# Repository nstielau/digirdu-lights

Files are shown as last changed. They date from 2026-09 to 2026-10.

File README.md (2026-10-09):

# Digirdu Lights

Expressive didgeridoo lighting for an **Unexpected Maker FeatherS2**, an
**ICS43434 I2S microphone**, and **32-pixel NeoPixel FeatherWings**. The local
wing previews a ~100-foot culvert with the player at its midpoint. Additional
ESP32/wing nodes receive musical features wirelessly over **ESP-NOW**.
Brightness is capped at **15%**, including overlapping visual layers. Audio
stays in RAM; only normalized features and animation state are transmitted.

## Hardware designs

The [producer enclosure](hardware/producer/README.md) contains the editable
Fusion model, pink/purple print files, all button variants, and assembly notes
for the **Adafruit ESP32-S3 Reverse TFT Feather** with an ICS43434 microphone
and 350 mAh LiPo. Revision 11 includes removable four-button assembly carriers.
This mechanical design targets a different board from the FeatherS2 software
setup described below; importing the CAD does not change deployed firmware.

## OTA application upgrades

[OTA operations and recovery](docs/ota-operations.md) describe the implemented
GitHub release/Firebase update workflow, device enrollment and validation status.
Devices try open `openwireless.org` at boot and return to ESP-NOW for playing.
App 1.0.7 adds Battery as the sixth effect. USB base 1.0.4 adds voltage to
device reports and supplies the shared sensor reader; install that base on
each board before it can receive app 1.0.7.
App 1.0.6 keeps the wing data line LOW through sleep to prevent stray pixels.
App 1.0.5 added hold-to-sleep with a synchronized red fade. App 1.0.4 added
Chroma, stronger musical effects and the IO43 effect button.
It keeps the app 1.0.3 fix for an intermittent CircuitPython ESP-NOW receive-buffer error that
could stop a consumer or trigger OTA recovery.
Manage enrolled devices at [Digirdu Lights](https://digirdu-lights.firebaseapp.com):
view their reported versions, follow the latest release, pin a version, or pause
updates. Each board needs a one-time USB bootstrap and its own credential.
Your Google profile photo opens the account menu in the top right; sign out
from that menu. Allowlisted administrators can also use the authenticated
[Sound review](https://digirdu-lights.firebaseapp.com/review.html) library. The
public [Effects guide](https://digirdu-lights.firebaseapp.com/effects.html)
describes Spectrum, Ember, Aurora, Ripple, Chroma and Battery for app 1.0.7, including frequency
bands, musical layers, BOOT selection and the mirrored number indicator.
Both web pages use a cyan/hot-pink 1980s laser theme with the supplied horizon
artwork, bundled locally in `web/assets/laser-horizon.png`.
Updates preserve the node's role, wiring and settings. A failing candidate
rolls back to the previous app; CircuitPython and the OTA base remain USB-managed.
The [original proposal](docs/ota-plan.md) records the approved design.

## What the playing controls

Effect 1 is an eight-band spectrum for microphone diagnostics. The other three
effects use the musical layers below simultaneously, with no exclusive
“current instrument” mode. See [spectrum display](#spectrum-display-effect-1).

| Component | Measurement | Visual response |
| --- | --- | --- |
| Drone | 45–180 Hz energy above background, concentrated low peak and pitch stability | Slow, sustained field extending in both directions |
| Harmonics / timbre | Relative 180–1000 Hz energy; 150–1000 Hz centroid and formant balance | Field hue, spacing and motion change at constant loudness |
| Growl | Relative low/mid energy × flatness, spectral change/modulation and spread | Rolling, irregular colored texture within the drone |
| Vocal | 700–3500 Hz share of total energy AND ratio to drone, plus spectral baseline excess | Brighter moving ribbons; strong onset launches a broader pulse |
| Attack | Positive spectral flux plus relative broadband RMS rise | Short pulses traveling outward from the player |
| Silence / decay | Activity hysteresis and separate release envelopes | Lingering light and trails that gradually fade to black |

These are acoustic **heuristics**, not voice identification. Resonance, vocal
formants and noisy articulations overlap. The intensity values express acoustic
character, not guaranteed classifications or source separation. Tune them while
playing the actual instrument in the culvert. A single microphone cannot tell
a fresh articulation from every strong reflected copy of it.

## Signal path and feature interface

`audio_spectrum.py` uses native `ulab` FFT operations, a **1024-sample Hann
window**, DC removal, **16 kHz** signed input and **1024-sample hops** (contiguous, non-overlapping windows).
The nominal update interval and analysis window are **64 ms**, with
15.625 Hz bin spacing. A 512-sample FFT, half-window overlap, or 22.05 kHz is also
configurable; re-run the hardware benchmark before using a shorter hop. Band edges select FFT bins; they are not brick-wall filters.
The low peak estimate is coarse, not a precision pitch tracker.

Initial energy bands: 45–180, 180–450, 450–1000, 1000–3500 and 3500–8000 Hz.
Power is normalized for the Hann window. Broadband RMS is computed from all
FFT power using Parseval's identity, so it is a DC-removed, Hann-weighted RMS.
The separate mic diagnostic reports unwindowed time-domain RMS. Spectral flux uses positive magnitude
changes normalized by frame magnitude; shape flux compares normalized spectral
shapes. By default, noisiness uses the participation ratio in 180–3500 Hz:
`(sum(power)**2 / sum(power**2))` estimates how many bins carry energy, then
removes the Hann footprint of a tone and normalizes to a noise-like spectrum.
This avoids hundreds of logarithms per frame on the ESP32-S2. Set
`roughness_metric="flatness"` for geometric/arithmetic mean power instead, and
check timing again. The diagnostic `flatness` field holds the selected
noisiness measure. Modulation
tracks changes in the *relative* low/mid energy, so scaling volume alone does
not define growl.

`Analyzer.update(raw, dt)` returns a reused `AudioFeatures` object with:

```python
volume, drone, harmonics, timbrePosition, growl, vocal
roughness, centroid, attack, decay                 # all 0..1
attackEvent, yellEvent                            # one-frame booleans
active, calibrating, clipped                      # state/diagnostics
rms, noiseFloor, bandEnergy, bandRatio, flux, flatness, modulation
spectrum  # Eight normalized band amplitudes, low to high frequency
fundamentalHz                                    # coarse low-band peak, or 0
```

Copy values if retaining history: the object is updated in place. Consume event
flags once per analysis frame. `attack` holds the event strength, then releases.
Drone, growl and vocal envelopes have separate attack/release times. Timbre and
centroid retain their last positions through silence while light decays.

### Algorithm, step by step

The implementation is split between [spectral measurements](audio_spectrum.py),
[feature detection](audio_features.py), and [rendering](animation.py). All
numbers below describe the defaults in [config.py](config.py); per-node
`OVERRIDES` can change the named parameters.

```mermaid
flowchart TD
    PCM[I2S signed PCM] --> FFT[Remove DC, Hann window, FFT]
    FFT --> Raw[Power bands, centroid, flux, noisiness, spread]
    Raw --> Adapt[Background subtraction and adaptive level reference]
    Adapt --> Features[Simultaneous drone, harmonics, timbre, growl, vocal]
    Raw --> Events[Attack and yell onset gates]
    Features --> Smooth[Separate attack and release envelopes]
    Events --> Scene[Layered field, textures, ribbons and outward pulses]
    Smooth --> Scene
    Smooth --> Radio[ESP-NOW features and scene state]
    Events --> Radio
    Scene --> LEDs[Trails, brightness cap and GRB pixels]
```

**1. Turn each audio window into comparable spectral measurements.** Subtract
its mean before applying the Hann window. For an FFT result `X[k]`, the
one-sided power is `2 * gain² * |X[k]|² / (N * sum(window²))`; DC and Nyquist
get half that factor because they have no separate negative-frequency partner.
RMS is the square root of the sum of this power over all bins. Band energy is
the sum over bins inside each configured interval (lower edge included, upper
edge excluded). The spectrum's `total` used for spectral ratios covers 45 Hz
up to, but excluding, Nyquist; it is distinct from the all-bin RMS power.

Centroids use **power weighting**: `sum(frequency * power) / sum(power)`.
The broad centroid becomes `centroid = clamp(centroid_hz / 3500)` before
smoothing. A second centroid uses only 150–1000 Hz for mouth/formant movement.
The drone estimate is the strongest FFT bin in 45–180 Hz; its concentration
is the fraction of drone-band power in that bin and its immediate neighbors,
clipped to the band. There is no harmonic pitch reconstruction or interpolation.

Two different flux measures serve different purposes:

- **Onset flux:** sum of positive changes in FFT magnitude, divided by the
  larger of the previous/current magnitude sums over 45 Hz to Nyquist. It
  responds to an amplitude jump as well as newly appearing frequencies.
- **Shape flux:** half the sum of absolute differences between spectra after
  each is normalized to unit magnitude sum. It responds to spectral
  redistribution with much less sensitivity to uniform volume changes.

Noisiness and frequency spread use 180–3500 Hz. The default participation
ratio estimates the effective number of occupied power bins; subtract
`noise_tonal_bins=2`, divide by `bin_count * noise_expected_fill` (default 0.5),
and clamp to 0..1. Optional logarithmic flatness computes the geometric mean
relative to the arithmetic mean, with a small numerical floor. Spread is the
power-weighted standard deviation of frequency, in Hz. These are texture
proxies: dense tonal harmonics can also occupy many bins.

**2. Learn background slowly and normalize playing level separately.**
Calibration lasts two seconds and ignores the first 0.2 seconds of microphone
startup. It takes the lower 20th percentile of RMS and, independently, each
band's power. The RMS noise floor cannot fall below 2 PCM units; each band has
a minimum background power of `2² / 5`.

During operation, the background updates only when `rms < 1.8 * noiseFloor`.
It rises with a 120-second time constant and falls with a four-second time
constant. Each band's learning target is also capped at twice its current
estimate. A strong foreground event therefore cannot immediately become the
new background. Continuous playing during calibration can still produce a bad
starting floor; calibrate quietly.

Let `S(a, b, x) = clamp((x-a)/(b-a), 0, 1)`. The shared activity gate is
`g = S(1.6, 5.0, rms/noiseFloor)`. `active` turns on at a ratio of 2.8 and turns
off after 0.45 seconds continuously below 1.6. This flag describes activity;
the continuous gate and release envelopes control the lights.

A separate playing-level reference starts at the larger of 120 PCM units or
five times the calibrated noise floor. Only frames above the active-on ratio
update it. Clamp each observation to between half and twice the reference,
then follow it with a 12-second rise or 45-second fall. Volume is:

```text
volume_target = g * clamp(
    log(1 + max(0, rms-noiseFloor)/noiseFloor)
    / log(1 + 2*level_reference/noiseFloor), 0, 1)
```

This logarithmic response makes quiet detail visible while limiting one loud
burst's influence. It is a rolling exponential reference, not a sliding-window
maximum. Other features mostly use spectral ratios rather than this volume.

**3. Calculate the continuous musical layers together.** Subtract the learned
background from each of the five band powers and clamp at zero. Divide by the
larger of their sum and the squared noise floor to obtain `bandRatio`.
Consequently the ratios can sum to less than one near silence. Below, `m` is
the combined 180–1000 Hz ratio, and all `S` outputs are bounded to 0..1.

| Feature | Calculation before its final smoothing |
| --- | --- |
| Drone | `g * S(2,6,drone_snr) * S(0.4,0.85,concentration) * (0.6 + 0.4*pitch_stability)`. `drone_snr` is the square root of raw drone power divided by its learned background. Stability follows frame-to-frame fractional changes of the strongest low bin; a 30% change maps to zero instantaneous stability. |
| Harmonics | `g * S(0.03,0.65,m)`: relative harmonic presence rather than loudness. |
| Timbre position | `0.65*S(150,1000,timbre_centroid_hz) + 0.35*(450–1000 Hz ratio)/m`, with a protected denominator. This blends formant position and upper-mid balance. |
| Roughness | `g * (0.55*noisiness + 0.25*modulation + 0.20*shape_flux)`, after mapping these inputs through their configured ranges. |
| Growl | `roughness * S(0.08,0.55,m) * (0.6 + 0.4*S(200,1200,spread_hz))`. Mid energy must coexist with texture; level alone is insufficient. |
| Vocal | Compute the ratio-based vocal base below, then multiply by `0.75 + 0.25*excess` relative to a slowly learned vocal share. |

Modulation here is **variation of relative mid-band energy**, not a detected
vibrato frequency: compare `m` with its 0.6-second reference, take the absolute
difference, and smooth it over 0.16 seconds. Default scaling ranges are
0.015–0.18 for modulation, 0.03–0.4 for noisiness, and 0.02–0.25 for shape flux.

Vocal detection uses the overlapping **700–3500 Hz** range, including part of
the mid/formant band; it does not use only the named 1000–3500 Hz band.
Unlike `bandRatio`, these vocal ratios use raw spectral powers with noise-floor
protection in the denominators:

```text
share = vocal_energy / max(total_energy, noiseFloor²)
relative_to_drone = vocal_energy / max(drone_energy, noiseFloor²)
vocal_base = g * sqrt(S(0.10,0.55,share) * S(0.12,1.50,relative_to_drone))
excess = S(0.04,0.25,share-vocal_reference)
vocal_target = vocal_base * (0.75 + 0.25*excess)
```

The vocal reference follows the share over 15 seconds only while the gate is
open and `vocal_base < 0.25`. Strong vocals cannot train themselves away.
Uniformly amplifying a clean drone preserves its spectral ratios, so it does
not create the missing high-frequency share required for a yell.

**4. Detect events without repeatedly firing on a sustained sound.**

- ATTACK score is `g * (0.65*S(0.06,0.4,flux) + 0.35*S(0.08,0.6,rms_rise))`,
  where `rms_rise = max(0, rms-previous_rms) / max(rms,noiseFloor)`. Fire at
  score 0.5 or above; rearm only below 0.18, with a 0.18-second cooldown.
- YELL fires when `vocal_base >= 0.58` **and** its rise from the previous frame
  is at least 0.10. Rearm below 0.25, with a 0.6-second cooldown. These checks
  use the unsmoothed base so a sustained vocal produces an envelope without
  repeatedly creating events. A gradual vocal can have intensity without YELL.
- Both events require the active-on RMS ratio and compare current RMS with
  60% of their own previous-event RMS memory, which decays over 0.8 seconds.
  This suppresses some weaker echoes; it cannot identify all reflected sounds
  and may also reject intentionally softer articulations.
- Calibration completion and detected capture gaps suppress events for 0.15
  seconds. Partial capture, a reported overflow, or a gap over three hop periods
  resets spectrum history. The first fresh spectrum has zero flux.

`attackEvent` and `yellEvent` last one analysis frame. `attack` preserves the
triggering score and decays with a 0.22-second time constant. ESP-NOW repeats
recent event counters and ages so a missed packet need not lose the pulse.

**5. Smooth features and let the scene ring out.** Every exponential smoother
uses `target + (previous-target)*exp(-dt/tau)`, choosing the attack constant
when rising and the release constant when falling. Times below are time
constants: after one constant, about 37% of the old difference remains.

| Envelope | Attack | Release |
| --- | --- | --- |
| Volume and harmonics | 0.09 s | 0.60 s |
| Drone | 0.30 s | 1.80 s |
| Growl and roughness | 0.16 s | 0.85 s |
| Vocal | 0.08 s | 0.50 s |
| Timbre and centroid | 0.22 s | 0.22 s; retain last position when the gate closes |

The scene also retains `decay = max(volume_target, previous_decay*exp(-dt/3.5))`.
The renderer builds a continuous field from drone, volume and this decay;
harmonics change wave spacing and speed, timbre changes hue, growl adds moving
texture, and vocal adds ribbons. Events enter a fixed eight-pulse pool and
travel outward from the player's coordinate at 1.15 half-culvert lengths/s,
with a 1.35-second intensity decay. These are artistic speeds, not sound speed.
App 1.0.4 mixes the larger of `0.85*drone`, `0.30*volume`, and
`0.42*decay`, with 0.28-second pixel trails. The 3.5-second audio decay remains
separate, so shortening trails does not abruptly end the atmosphere.
Contributions are capped before
conversion to GRB bytes at brightness 0.15 (maximum channel value 38).
The musical effects change palette and layer parameters while preserving the
shared detector and scene state. Spectrum uses its own band-level envelopes.

### Expressive musical effects (1.0.4)

App 1.0.4 includes the September 16 preview that strengthens effects 2–4
using a labelled didgeridoo feature capture, plus the IO43 button and Chroma. Spectrum's eight bar envelopes and the detector thresholds
are unchanged. Consumers need the updated renderer to match this release;
the ESP-NOW packet format remains v3.

| Feature (median) | Drone section | Rhythms | Growls |
| --- | --- | --- | --- |
| Drone | 1.00 | 0.98 | 0.99 |
| Harmonics | 0.45 | 0.635 | 0.66 |
| Growl | 0.05 | 0.18 | 0.21 |
| Roughness | 0.16 | 0.44 | 0.47 |

There were 4 attack events in the drone label, 42 during rhythms and 16 during
growls. Growls and rhythms overlap; these results do not establish reliable
technique classification. One yell event occurred under the growl label and
two under the yell label. The 80-second logger ended before the final decay
section, so the full three-yell exercise and acoustic decay were not verified.
Only timestamped feature/event logs were saved locally, not raw audio.
Labels follow host cues; tool/message delays made the windows longer than the
requested ten seconds. The median table includes transition samples and uses
the normal once-per-second feature log, not every FFT frame.

The renderer now expands measured timbre positions 0.12–0.45, growl 0.04–0.30,
and vocal 0.03–0.40 to their full visual ranges. These are visual transfer
functions (`visual_*_range`), not changes to classification. Faster waves and
a lower wave trough increase motion contrast. Short pixel trails keep attacks
distinct; immediate whole-wing accents accompany the outward pulse on attacks
and yells. These accents decay over 0.13/0.32 seconds and account for event age
on wireless receivers. Ripple has a stronger underlying field, while remaining
the most pulse-focused effect. All overlapping layers still obey brightness 0.15.

New visual controls in `config.py`: `visual_timbre_range`, `visual_growl_range`,
`visual_vocal_range`, the three `*_field_gain` values, `wave_floor`,
`vocal_ribbon_gain`, `attack_bloom_gain/s`, `yell_bloom_gain/s`, and `pulse_gain`.
The existing wave speeds, pulse width/speed/decay and `trail_s` remain tunable.

A host comparison used 32 frames at 64 ms with the observed drone feature
values, then changed only growl from 0.05 to 0.21 or timbre from 0.20 to 0.30.
Mean absolute GRB-byte differences (old → preview) were:

| Effect | Growl response | Timbre response | Frame-to-frame motion |
| --- | --- | --- | --- |
| Ember | 2.04 → 9.39 | 0.30 → 1.10 | 0.18 → 0.72 |
| Aurora | 0.80 → 5.78 | 0.59 → 2.43 | 0.09 → 0.55 |
| Ripple | 0.70 → 4.63 | 0.12 → 0.96 | 0.05 → 0.37 |

These compare output buffers, not perceived brightness or measured light.
The baseline is the renderer/configuration at commit `17d17ed`. Brightest
channel values remain at most 38; regression checks cover observed-range
response, late event accents, fade to black, and the cap.

The producer USB upload verified all 18 base/recovery files. Eight-second
native runs per musical effect included I2S, FFT, actual NeoPixel writes,
ESP-NOW, watchdog and health checks (including each run's calibration):

| Effect | Frames / fps | Mean / maximum work | Frames over 64 ms | Radio sends / errors |
| --- | --- | --- | --- | --- |
| Ember | 111 / 13.8 | 63.4 / 84.0 ms | 47 | 93 / 0 |
| Aurora | 107 / 13.4 | 65.5 / 86.1 ms | 63 | 92 / 0 |
| Ripple | 115 / 14.3 | 62.3 / 82.0 ms | 43 | 81 / 0 |

All three runs reported zero send skips and zero detected discontinuities.
Timing still exceeds the hop budget on many frames; no-discontinuity output
does not prove lossless capture. These runs used ambient sound, not a repeat
of the labelled didgeridoo performance. CircuitPython subsequently hard-faulted
during the post-benchmark soft restart. All installed files still matched;
a full reset was used to leave safe mode. The fault's native cause has not
been established, and a short running-app check cannot establish long-term
stability.

## Spectrum display (effect 1)

The initial effect is **Spectrum**, display number 1 / protocol ID 0. Hold the
wing in landscape: **eight columns across, four rows high**. Low frequencies
are left, high frequencies right; bar height is the level in that frequency
bucket. A red-to-violet rainbow runs across the columns. The top pixel of each
bar dims continuously between row steps. Brightness remains capped at 0.15.

| Column, left to right | Frequency range (Hz) |
| --- | --- |
| 1 | 45–90 |
| 2 | 90–180 |
| 3 | 180–350 |
| 4 | 350–700 |
| 5 | 700–1400 |
| 6 | 1400–2800 |
| 7 | 2800–5000 |
| 8 | 5000–8000 |

These are eight independent sums of the existing Hann FFT's power, not a
redistribution of the five musical detector bands. Upper edges are exclusive.
At 16 kHz / 1024 samples, FFT bins are 15.625 Hz apart; this is a coarse
level display, not precision pitch measurement. Raising the sample rate leaves
the default top edge at 8 kHz; tune `spectrum_edges` to include higher frequencies.
Wider buckets collect more broadband-noise power; heights show integrated band
amplitude, not power per Hz or calibrated sound pressure.

Each bucket gets a quiet-start background estimate and the same gated, slow
background learning as the musical detectors. The display computes:

```text
amplitude[i] = sqrt(max(0, power[i] - background[i]))
target[i] = activity_gate * clamp(spectrum_gain * amplitude[i]
                                / (level_reference * spectrum_full_scale)) ** spectrum_curve
height[i] = 4 * attack_release_smooth(target[i])
```

The shared level reference adapts slowly (12 s up / 45 s down, bounded input).
It does not stretch every frame's tallest bar to full height: a louder version
of the same sound raises the bars. Defaults are gain 1, full-scale reference
multiplier 2, amplitude curve 0.6, attack 0.05 s and release 0.30 s. Adjust
`spectrum_gain`, `spectrum_full_scale`, `spectrum_curve`, `spectrum_attack_s`,
`spectrum_release_s`, and the nine `spectrum_edges` in your node profile.
Calibration still needs two quiet seconds. On silence the bars fall smoothly;
there are no added musical pulses or background glow in this diagnostic effect.

Factory wiring has four progressive rows: top row indices 0–7, bottom 24–31.
The bottom-up bar coordinate `(x, y)` maps to `(3-y)*8+x`. Set
`spectrum_rotation=180` on a flipped wing. This mapping ignores culvert
`pixel_positions`; complete 32-pixel tiles repeat the display, and leftover
pixels stay dark. The confirmed portrait number indicator keeps its independent
orientation and still appears for 1.5 s when BOOT changes the effect.

ESP-NOW **protocol v3 / 51 bytes** carries all eight normalized levels at
8-bit precision, as well as the existing features, events and effect ID.
Update producer and consumers together: v2 and v3 reject each other's packets.
Consumers do not need a microphone or FFT. They use the producer's level
smoothing; loss of the radio link fades the last levels over `decay_s`.
`SPECTRUM levels=(...)` in both serial logs exposes the eight values, low to high.

## FeatherS2 wiring

Disconnect power before changing wiring. These are **GPIO numbers**: Feather
D-number aliases do not necessarily match them.

| Connection | FeatherS2 pin | CircuitPython name |
| --- | --- | --- |
| Mic BCLK / SCK | GPIO 5 | `board.IO5` |
| Mic LRCLK / WS | GPIO 6 | `board.IO6` |
| Mic DOUT / SD | GPIO 9 | `board.IO9` |
| Mic SEL / LR | GND | Left channel selected |
| Mic 3V / VDD | 3.3V | Use the main 3V3 supply |
| Mic GND | GND | Shared ground |
| Wing data, factory jumper | GPIO 38 | `board.IO38` |
| Wing power | Feather USB/BAT and GND headers | Aligned, soldered headers |

The mic uses standard I2S, 32-bit slots carrying 24-bit signed samples,
16 kHz sampling, and the left channel. CircuitPython converts capture to
signed 16-bit samples for level measurements. GPIO 9 is also the SCL pin:
do not use I2C/STEMMA devices on that pin while this mic is connected.
The FeatherS2 onboard APA102 status LED is separate from the FeatherWing.
The wing's default jumper occupies the standard Feather M0 D6 header position,
which maps to **GPIO 38** on FeatherS2. Do not use FeatherS2's `board.D6` alias:
it maps to GPIO 3 at a different physical position and leaves this wing dark.

## Setup and firmware

Host requirements: Python 3.10+, `make`, `curl`, USB data cable. Tools install
into `.venv`; no extra CircuitPython library bundle is needed by this app.
`make check` additionally needs Python 3.10–3.13 for the pinned NumPy version.
The pinned firmware is **CircuitPython 10.3.1 for `unexpectedmaker_feathers2`**.
The Adafruit ESP32-S2 Feather and FeatherS2 Neo use different firmware.

```sh
make setup
make ports
make firmware       # Download the correct .uf2
```

The connected FeatherS2 initially had CircuitPython **6.2.0-beta.1** from 2021.
That version needs upgrading for the `audioi2sin.I2SIn` API used here. Its
existing app and libraries were backed up to
`.artifacts/feathers2-files-1789493704704278000/` before the upgrade.

For future firmware upgrades, first back up the files on `CIRCUITPY`. Enter
the UF2 loader: press Reset, then press Boot when the onboard RGB LED turns
purple. The drive is normally called **FTHRS2BOOT**.
Older loaders may show no purple: press Reset, wait about one second, then
press Boot. Their drive may be called **UFTHRS2BOOT**; both names are supported.
Once that drive appears, run:

```sh
make flash
```

The FeatherS2 target copies the official UF2 to the identified bootloader drive.
It does not erase the entire flash. Wait for **CIRCUITPY** to reappear. If no
bootloader drive appears, consult the manufacturer's recovery instructions
linked below; do not use the old ESP32 board's flash command on this board.

### Older boards without a working UF2 loader

Hold **BOOT**, tap **RESET**, then release BOOT. If the recovery USB port does
not appear, unplug USB and reconnect it while holding BOOT, then release BOOT.
This uses the chip's built-in ROM loader and does not require a purple LED.

```sh
make ports
make flash-rom      # Checks ESP32-S2/16 MB, backs up flash, ERASES, writes .bin
```

Tap Reset after flashing if instructed. This installs CircuitPython directly;
it does not install the optional TinyUF2 loader. Use `make flash-rom` for later
firmware reinstalls if no FTHRS2BOOT drive is available. Routine app changes
still use only `make deploy`. Firmware and full flash backups stay in
`.artifacts/` and are ignored by Git.

## Deploy and test

```sh
make check
make deploy
make test-mic
make benchmark
make console
```

`make deploy` automatically identifies supported boards from CircuitPython's
board ID: FeatherS2 uses GPIO 38 and its matched CIRCUITPY drive; Adafruit
Feather ESP32 V2 (HUZZAH32 V2) uses GPIO 32 and serial file transfer. Both get
the same OTA base and complete recovery application, preserving device settings. An unknown model stops before
writing; add and verify its hardware profile before deploying to it. Use
`BOARD=...` to require a specific model. Firmware installation still requires
an explicit board choice for anything other than the default FeatherS2.

Deployment stops the app, backs up existing application files under
`.artifacts/`, stages uploads, verifies readback, and restarts. Startup checks require audio-level output (leader)
or a running render loop (follower), with no traceback. Existing `node_config.py` is preserved unless `NODE_CONFIG=...`
is supplied explicitly. A level log alone cannot establish that the microphone responds
to sound; compare quiet and clap levels and watch the LEDs.

Keep the room quiet for the **first two seconds** after startup to calibrate
the noise floor. Then play a steady drone, change mouth/tongue position, add a
growl, vocalize, and try hard DOOTs. Watch both the feature logs and the lights.

`make test-mic` captures ten seconds with the LEDs off, prints RMS (average
signal strength), peak, and sample span, then resumes the app. Stay quiet at
first and clap during the test. The maximum RMS should exceed the quiet level;
constant zero/span-zero data indicates a wiring or power problem. These are
relative digital levels, not calibrated sound-pressure decibels.

`make benchmark` measures the producer's live audio/animation loop and then
resumes the app. See [Benchmarking](#benchmarking) for its scope, interpretation,
and recorded hardware results.

`make console` shows `AUDIO rms=... drone=... growl=... vocal=...` plus
`ATTACK strength=...` and `YELL vocal=...` lines. `clip=True` means the microphone
PCM is saturating; software gain cannot recover the lost waveform.
Ctrl-C stops the app and turns off the wing, Ctrl-D restarts/calibrates it,
and Ctrl-] closes the console. Close other serial terminals before deployment.

For multiple boards or a differently named mount:

```sh
make deploy PORT=/dev/cu.usbmodem... MOUNT=/Volumes/CIRCUITPY
# Linux example: PORT=/dev/ttyACM0 MOUNT=/media/yourname/CIRCUITPY
```

## Benchmarking

### Repeat the hardware measurement

Connect the **microphone FeatherS2**, close other serial terminals, and run:

```sh
make ports
make benchmark PORT=/dev/cu.usbmodem...
```

With OTA enabled, first enter [USB maintenance](docs/ota-operations.md#maintenance-and-usb-repair).
This loads the recovery app and invokes `lights_app.benchmark(5)` through the REPL. It stops the
running app, creates fresh analysis/render/radio state, and runs for about five
seconds including the initial two-second calibration. Stay quiet during
calibration, then play or clap to exercise the feature and pulse layers. The
benchmark calculates all pixel bytes but **does not write them to the wing**.
It then restarts the normal app, which calibrates again. A standalone producer
profile with `radio_role="off"` omits radio work; record the role with results.

For comparisons, record board/firmware, deployed revision, node overrides,
FFT/hop/rate, pixel count, radio role, effect, and the sound used. Compare quiet,
steady-drone and attack/vocal-heavy runs separately: active pulses increase
rendering work. Five seconds is a quick diagnostic with only about three
seconds after calibration, not a sustained-load test. Re-run after changes to
FFT overlap, pixel count, noisiness metric or effects; also inspect normal
LED-enabled operation for timing warnings.

### What the output measures

| Field | Meaning |
| --- | --- |
| `frames` | Complete analyzed and rendered frames, including calibration frames |
| `fps` | Frames divided by total loop wall time, including blocking microphone capture |
| `work_mean_ms`, `work_max_ms` | Processing time **after** each `mic.record()` returns: FFT, feature updates, button polling, rendering, radio work, event/periodic logging and explicit garbage collection |
| `budget_ms` | `1000 * hop_size / sample_rate`; 64 ms with the defaults |
| `overruns` | Frames whose measured post-capture work exceeds that budget |
| `discontinuities` | Detected incomplete captures, reported overflows, or capture-to-capture gaps longer than three hop periods |
| `sent` | Broadcasts submitted without a synchronous send error; not consumer acknowledgements |
| `errors` | Exceptions from send attempts |
| `skipped` | Send opportunities skipped while the previous send is still pending |

The work timer excludes the blocking capture call and its internal copying;
it also excludes printing the over-budget warning itself. LED serialization
is excluded in benchmark mode. Consequently a mean below 64 ms does **not**
prove that the complete producer keeps up continuously. Normal operation uses
the same timing loop with LED writes enabled. The ESP32-S2 driver does not
report every DMA overflow: `discontinuities=0` is not proof of lossless capture.
The nominal maximum is 15.625 windows/s; this is not a measured end-to-end
sound-to-light latency. Capture, envelopes, radio scheduling and consumer
rendering all contribute to perceived response.

### Recorded results — September 15, 2026

FeatherS2, ESP32-S2 at 240 MHz, CircuitPython 10.3.1, 16 kHz capture, 1024 FFT /
1024 hop, 32-pixel renderer, participation noisiness, ESP-NOW producer enabled.
The live sound varied and triggered ATTACK/YELL features; it was not a recorded,
repeatable didgeridoo dataset. These measurements were taken during development
of the implementation committed in `4ceb381`; no new hardware timing run is
implied by this documentation update.

```text
AUDIO BENCH frames=72 fps=14.3 work_mean_ms=59.1 work_max_ms=97.7 budget_ms=64.0 overruns=20 discontinuities=0
RADIO BENCH sent=48 errors=0 skipped=0
```

| Check | Measured result | Interpretation |
| --- | --- | --- |
| Live producer throughput | 14.3 frames/s versus nominal 15.625 | Below the intended capture-window cadence |
| Post-capture work | 59.1 ms mean; 97.7 ms maximum | Average fits narrowly; peak exceeds the 64 ms budget |
| Over-budget frames | 20 of 72 (about 28%) | Current configuration has intermittent processing overruns |
| Radio submissions | 48; zero reported errors or pending-send skips | Sender path ran; submission success alone says nothing about reception |
| Separate renderer stress check | Maximum 20.2 ms with all features/events and a full pulse pool | Renderer-only diagnostic, not total frame time; do not add it to the live measurement, which already includes rendering |
| Native FFT sanity check | 93.75 Hz sine, amplitude 1000: RMS 706.65, drone-power share about 0.99998 | Agrees with the expected sine RMS near 707 and correct low-band placement |
| Two-device radio check | ESP32 V2 accepted 94 packets in its first eight seconds, zero rejected; later restart/rejoin reached 256 accepted, zero rejected | Confirms actual reception and automatic rejoining at the tested location; not culvert-wide RF coverage |

The implementation uses native `ulab` arrays for FFT, dot products and
per-pixel math. Full-window hops reduce the number of FFTs per second;
participation noisiness avoids per-bin logarithms; RMS reuses FFT power;
frequency arrays are cached and the event pulse pool is bounded. These choices
reduce work, but the measured overruns remain. Validate processing headroom on
the actual sound/effect load before adding pixels or shortening the hop.

### Previous Culvert preview: historical measurement

Before Spectrum replaced effect 1, after adding the stronger volume response and attack bloom, a mostly quiet
five-second producer run measured **77 frames, 15.3 frames/s, 55.4 ms mean work,
66.1 ms maximum, two overruns, zero detected discontinuities**, and 44 radio
submissions with no errors/skips. The sound load differs from the earlier
attack-heavy run, so this is a functional timing check, not evidence of a
performance improvement. LED writes are still excluded in benchmark mode.

On the board's native renderer, fixed test features at volume 0.05 versus 0.8
produced sums of all pixel channel bytes of **298 versus 1540** (about 5.2×),
with the same drone and residual decay levels. An attack-strength-0.8 test
produced a peak of **38**, with every pixel reaching at least 20 in one channel.
These are output-byte checks, not measured light intensity or an acoustic test.
The producer's full file readback and startup passed with effect 0 selected.

### Producer with OTA health monitoring (September 16, 2026)

After installing app **1.0.3** and base **1.0.1** on FeatherS2, a 12-second
mostly quiet run used `lights_app.run(seconds=12, health=Health(watchdog, False))`.
It included actual NeoPixel writes, the 20-second watchdog and OTA feature-health
checks, as well as microphone capture, FFT, Spectrum rendering and ESP-NOW.

| Measurement | Result |
| --- | --- |
| Frames / update rate | 146 / 12.1 fps |
| Post-capture work | 74.6 ms mean / 93.0 ms maximum |
| Work over the 64 ms budget | 136 of 146 frames |
| Detected discontinuities | 0 |
| ESP-NOW sends / errors / skips | 146 / 0 / 0 |
| Free Python heap before the run | 7,678,640 bytes |

Most frames exceeded the processing budget. Zero detected discontinuities does
not prove lossless capture; the driver cannot report every DMA overflow. These
numbers include LED writes and the health monitor, so they are not directly
comparable to the LED-disabled measurements below. After enabling OTA, the board
checked in to Firebase over HTTPS, returned to ESP-NOW channel 1 and continued
processing changing microphone levels for the 65-second observation window.

### Spectrum preview: measurement before OTA

After replacing effect 1 with the eight-band display, `make deploy` verified all
ten application files on the FeatherS2 and retained its producer profile.
A mostly quiet five-second `make benchmark` run measured **74 frames, 14.7 fps,
55.9 ms mean work, 69.1 ms maximum, three overruns of the 64 ms budget, and zero
detected discontinuities**. ESP-NOW submitted **51 packets with zero errors or
skips**. Benchmark mode excludes LED writes and capture blocking from work time;
these numbers do not establish worst-case performance or consumer reception.
The initial serial logs showed changing low-band levels near the noise floor.
The ESP32 V2 consumer subsequently received the same update: all ten application
files passed final readback, with its saved consumer profile preserved. Its
eight-second startup check accepted **96 protocol-v3 packets, zero rejected**,
with a live link to the producer and Spectrum selected. Reported band levels
were near zero (mostly dark; one bottom pixel briefly at channel value 1).
A subsequent 30-second serial observation included a consumer reboot/rejoin
and reached **308 accepted packets, zero rejected**. During active sound, sampled
volume varied from **0.34 to 0.91**, the second frequency bucket reached **0.87**,
and rendered output varied from **5 to 17 lit pixels**, with peak channel values
**13–38**. This verifies changing producer features, consumer reception and bar
output. The source sound during that log capture was not identified.

The user subsequently **visually confirmed rainbow bars rising and falling in
response to sound on both the producer and consumer wings**. This completes
the two-board Spectrum response check; it does not establish didgeridoo
classification accuracy or RF coverage inside the culvert.

### Algorithm checks versus musical accuracy

`make check` runs 72 host tests using pinned NumPy and generated PCM, plus
packet-state, renderer, button and deployment checks. Signal cases include
50/93.75/140/175 Hz drones at different levels, equal-RMS timbre changes,
modulated mid-band noise, vocals layered over drone, attacks and decaying tails,
loud outliers, and a 60-second sustained drone that must not become background.
They verify calculations and expected behavior under controlled inputs. Host
execution time is not an ESP32 performance benchmark, and these tests do not
provide precision/recall or classification accuracy on real didgeridoo playing.
The earlier clap-reactive rainbow and the two-board Spectrum response have
visual confirmation; the musical layers still need an instrument trial in the culvert.

## Tune the installation

Defaults live in `config.py`; put per-node changes in an `OVERRIDES` dictionary
in a node profile, then run `make deploy NODE_CONFIG=path/to/profile.py`. Routine
`make deploy` preserves the configuration already saved on that board. Important groups:

- **Capture:** `sample_rate`, `fft_size`, `hop_size`, `bands`, `timbre_band`,
  `vocal_band`, `roughness_band`, `gain`. Use full-window hops on this FeatherS2 for processing headroom; half-window
  hops are available for faster boards. At 22.05 kHz,
  extend the high band's upper edge to 11025 Hz.
- **Background:** `calibration_s`, `min_noise_rms`, `noise_rise_s`,
  `noise_fall_s`, `noise_learn_ratio`, activity ratios and `silence_hold_s`.
- **Dynamics:** `level_initial`, `level_rise_s`, `level_fall_s`,
  `adaptation_limit`, and each feature's attack/release times.
- **Growl:** `mid_ratio`, `flatness_range`, `modulation_range`,
  `shape_flux_range`, `roughness_weights`, `spread_hz`, `roughness_metric`,
  `noise_tonal_bins`, `noise_expected_fill`.
- **Vocal:** `vocal_total_ratio`, `vocal_drone_ratio`, `vocal_excess_range`,
  `yell_on/off`, `yell_rise`, `yell_cooldown_s`.
- **Attacks/echoes:** flux/rise ranges, `attack_on/off`, cooldown,
  `echo_memory_s` and `echo_event_ratio`. Higher echo rejection can also miss
  intentionally softer repeated articulations.
- **Visuals:** hue/timbre span, wave speed/spacing, pulse speed/width,
  `decay_s`, `trail_s`, and per-pixel coordinates. Spectrum has separate
  band/amplitude/smoothing controls described above. Keep `brightness=0.15`.

Start with a quiet reset. Play the same drone softly and loudly: `drone` should
persist and `vocal` should stay low. Move mouth/tongue position at similar level:
`timbrePosition` should move. Add a growl: adjust texture thresholds before gain.
Add vocals: tune the two energy-ratio ranges before `yell_on`. Finally stop and
listen to the culvert tail while adjusting `decay_s` and echo rejection. Do not
calibrate during continuous playing. Flat data for two seconds stops the app
with an explicit wiring error and clears the wing.

## Multiple wireless FeatherWings

Each wireless node needs an ESP32 and local power for its FeatherWing. Wings
alone do not contain a radio. The current mic board is the **producer** (internally `leader`); consumers
(internally `follower`)
render the transmitted features without initializing a microphone. Consumers support **FeatherS2 GPIO 38** and **Adafruit Feather ESP32 V2 GPIO 32**.
The board ID selects the verified pin automatically. The ESP32 V2 profile is
consumer-only; microphone wiring is configured on FeatherS2.

ESP-NOW uses a common 2.4 GHz channel (default 1), without a router, Wi-Fi login,
or internet connection during playback. The OTA startup phase may connect to
Wi-Fi, then disconnects before restoring the lighting channel. The sender broadcasts version-3, 51-byte packets at up to ~16 updates/second. Packets contain eight spectrum levels, feature envelopes, scene
time/phase, the selected effect ID, a boot/session ID, sequence number, and recent event counters,
strengths and ages. Receivers filter the configured leader MAC and group, reject
duplicate/out-of-order packets, and recover a recent event if one packet is
lost. Broadcasts are unencrypted; MAC/group filtering avoids mixing installations
but is not authentication. Only lighting state is sent, never audio.

A follower starts dark until it receives valid state. After 0.5 seconds without
valid packets it releases the last state over `decay_s`; it does not freeze
bright or abruptly switch off. Scene phase is refreshed on receipt, providing
approximate visual synchronization, not sample-accurate clock synchronization.
Radio range and reception inside the culvert require a real multi-node test.

### How connections work

```mermaid
flowchart LR
    Mic[ICS43434 microphone] --> Producer[FeatherS2 producer + wing]
    Button[BOOT button: next effect] --> Producer
    Producer -->|ESP-NOW broadcast, channel 1| A[Consumer A + wing]
    Producer -->|Same lighting state| B[Consumer B + wing]
    Producer -->|Same lighting state| C[Additional consumers + wings]
```

There is no pairing button, network password, connection handshake, or consumer
registration. Power the producer and any configured consumers; each consumer
listens independently for the producer's broadcasts. Adding another consumer
does not add another transmit stream. Consumers do not relay packets, so each
must be within radio reach of the producer. This is one producer broadcasting
to many consumers, not a mesh. Every node needs local power.

| Setting | What must match |
| --- | --- |
| `radio_channel` | Same 2.4 GHz channel on all nodes; default 1 |
| `radio_group` | Same installation number on all nodes; default 1 |
| `leader_mac` | Consumers accept the microphone board's MAC, currently `7c:df:a1:03:4c:2c` |
| `radio_role` | One `producer`; all other nodes `consumer` |
| Firmware/protocol | Deploy this application version to all nodes |
| `pixel_positions` | May differ per wing to locate it in the shared scene |

To test: power both boards, keep quiet through producer calibration, then clap
or play. On the consumer, `LIGHTS ... received=... link=live` should show an
increasing receive count. Press the producer's BOOT button for about 0.2 seconds;
the consumer's `effect=` should change too. If reception stays at zero, check
producer power, matching MAC/channel/group, and distance. If packets arrive but
the wing stays dark while playing, check the wing data jumper and local power.
Silence normally fades the lighting to black.

The consumer status line also reports `age_ms` since the latest accepted packet
(`-1` before the first), `active`, received `vol/drone/growl/vocal` envelopes,
and the number of pixels with nonzero output (`lit`) plus the largest output
channel byte (`peak`). Changing envelopes and pixel bytes demonstrate received
state reaching the renderer and LED write call; physical illumination still
needs a visual check. The producer broadcasts even during silence, so an
increasing receive count serves as a basic heartbeat while its audio loop runs.
It is not an independent watchdog for a stalled microphone or producer loop.

### Saved roles and joining

The same application runs on all nodes. A new node defaults to **consumer**;
its saved `node_config.py` selects the role. We deliberately do not auto-detect
producer status from microphone noise: an unconnected data pin can produce
nonzero samples. An explicit producer profile avoids multiple accidental
producers. Role and coordinates survive reset and routine app updates.

For the known microphone board:

```sh
make deploy NODE_CONFIG=examples/node_producer.py
make test-mic
```

For each new **FeatherS2 or Feather ESP32 V2 consumer**, connect it over USB,
edit a copy of the consumer example with that wing's coordinates, and deploy:

```sh
make deploy NODE_CONFIG=examples/node_follower.py
# Optional model enforcement for the HUZZAH/Feather ESP32 V2:
make deploy BOARD=adafruit_feather_esp32_v2 NODE_CONFIG=examples/node_follower.py
```

With multiple USB boards, select the consumer's port. For FeatherS2, also
select its matching CIRCUITPY mount if needed:

```sh
make deploy NODE_CONFIG=examples/node_follower.py PORT=/dev/cu.usbmodem... MOUNT=/Volumes/CIRCUITPY
```

Then use `make deploy` without `NODE_CONFIG` for ordinary software updates.
The producer's state is broadcast, so multiple powered consumers can join at
once without being added to a peer list. A newly joining consumer picks up the
current effect from the next accepted packet. Broadcast has no per-consumer
acknowledgement; a successful send does not prove that every wing received it.

The known producer MAC is `7c:df:a1:03:4c:2c`. Match `leader_mac`, `radio_group`
and `radio_channel` on consumers. `make console` reports MAC, role and link state.
Use `radio_role="off"` for a local audio preview without transmitting. Profiles
accept `producer`/`consumer` as well as the internal `leader`/`follower` names.

### Effect library and BOOT button

App 1.0.4 also accepts a normally-open button between **FeatherS2
IO43 (TX) and GND**, alongside BOOT/IO0. Both inputs have internal pull-ups, independent
40 ms debouncing, and advance one effect on a short release. In 1.0.5, holding either for three
seconds starts sleep instead of changing effects. Both trigger the same number indicator and ESP-NOW effect update.
No external pull-up is required. Set `button_extra_next_gpio=None` to disable
the added input or change it to another unused GPIO. This additional input is
included in OTA release 1.0.4.
IO43 is for normal effect selection; USB maintenance still uses BOOT after RESET.
Do not initialize UART TX on IO43 while using this button. USB serial is separate.
Run `make test-buttons` in USB maintenance to inspect both inputs.

The initial IO18 USB deployment on September 16 verified all 18 base/recovery files on the
FeatherS2. The board initially remained in CircuitPython's user-triggered safe
mode; requesting `microcontroller.RunMode.NORMAL` before a hard reset restored
normal startup. Logs then confirmed GPIO0 and GPIO18 with pull-ups, live audio
and ESP-NOW channel 1. IO18 read LOW during inspection and triggered one change
to Ember at startup. Later IO18/IO38 tests remained LOW; disconnecting the
external wiring restored HIGH on both. IO38 is the wing data pin, so it cannot
also be an effect button. A subsequent 60-second IO43 test registered **23
debounced presses, 46 transitions, and a final released/HIGH state**. IO43 is
now deployed alongside BOOT: all 18 base/recovery files passed readback and
startup logged both inputs with pull-ups. Microphone samples became flat during
the wiring investigation but were changing again after the final restore.
This is serial evidence, not a new visual confirmation of both wings.
See [the recovery record](docs/ota-operations.md#io43-button-usb-update) for the
USB filesystem issue encountered during this update.

The initial effect is **Spectrum (ID 0)**, the eight-column diagnostic above.
Test with two quiet seconds after reset, then speak or play near the mic.
Ember, Aurora and Ripple use the musical animations; Ripple gives pulses more
space with a dimmer field. All nodes need protocol v3 for matching spectrum
levels and effect state, and matching renderer versions for matching appearance.

Press and release **BOOT** while the producer is running to advance:

| Display | Protocol ID | Effect | Number color | Character |
| --- | --- | --- | --- | --- |
| 1 | 0 | Spectrum | Blue | Eight rainbow frequency bars, four rows of sound level |
| 2 | 1 | Ember | Orange | Warm, broad waves and stronger growl texture |
| 3 | 2 | Aurora | Mint/cyan | Cooler, tighter waves and wide vocal pulses |
| 4 | 3 | Ripple | Violet | Dimmer atmosphere emphasizing narrow outward attacks |
| 5 | 4 | Chroma | Cyan | Whole-wing frequency color, volume brightness, smooth fades |

### Effect-number confirmation

When an effect changes, the 32-pixel wing shows its **number 1–5** as a 3×7 dot
matrix on black for about **1.5 seconds**, then returns to the live animation.
This replaces the previous subtle palette preview. The digit appears even in
silence, and its color identifies the effect as well. Brightness remains capped
by `brightness=0.15`; the indicator does not add brightness to the scene.

Read the wing in portrait orientation: four pixels across and eight tall. The
font uses three columns and seven rows, leaving a blank right column and bottom
row. The default mapping places physical pixel 0 at the bottom left. It is
derived from the progressive eight-pixel rows in
[Adafruit's PCB layout](https://github.com/adafruit/Adafruit-NeoPixel-FeatherWing-PCB/blob/master/Adafruit%20NeoPixel%20FeatherWing.brd),
rotated into portrait. If your installation mounts a wing upside down, set
`effect_indicator_rotation=180` in that node's profile.

The producer shows the number when its debounced BOOT press changes the effect.
Consumers show it when they receive a different effect ID. That ID is still
present in every version-3 packet, so a missed change is recovered from the next
accepted update. Unchanged packets **do not restart** the timer. Fast successive
changes replace the displayed number with the latest one. A consumer joining
an effect different from its initial setting also shows the number. Radio and
frame timing introduce a small delay between nodes; this is not an exactly
synchronized display timer. A packet-format update or pairing is not required.

The number is an output overlay: microphone sampling, feature analysis, radio
updates, scene time, pulses and trails continue underneath it. The overlay is
not stored in the trails, so it leaves no ghost digit. Silence returns to dark
after the indicator expires; holding BOOT does not auto-repeat. Startup alone
does not show a number unless the effect subsequently changes.

Per-node controls in `config.py` / `OVERRIDES`:

- `effect_indicator_enabled`: enable the overlay (default `True`).
- `effect_indicator_s`: positive display duration, default `1.5` seconds.
- `effect_indicator_rotation`: `0` or `180` degrees in portrait orientation.
- `effect_indicator_map`: optional 32-entry permutation of physical indices
  0–31, listed row by row for logical 4×8 coordinates; default uses the factory
  mapping. Rotation is applied to logical coordinates before this mapping.

The indicator uses local physical pixels, independently of `pixel_positions`
used to place a wing along the culvert. On a wired chain of complete 32-pixel
wings, it repeats the number on each wing. Counts not divisible by 32 skip the
indicator; their normal animation continues. Firmware on every node must include
this renderer to display the number. Consumer status logs use `indicator=1..5`
while the overlay is active and `indicator=0` otherwise; protocol IDs remain
zero-based. Producer change logs include the corresponding `display=1..5`.

The initial effect after a producer reset comes from `effect_index`; button
changes are not written to flash on every press. Scene state and trailing light
continue across effect changes.

BOOT connects GPIO 0 to ground. It is a normal readable input during the app,
with a special boot-selection role **at reset**: holding BOOT while resetting
enters the ROM download loader. For effect changes, press BOOT without RESET.
See [Espressif's boot-pin description](https://docs.espressif.com/projects/esptool/en/latest/esp32s2/advanced-topics/boot-mode-selection.html).
Use a deliberate ~0.2-second press so the audio loop can sample it twice.

If even a one-second hold does not change the producer's wing, connect the
microphone FeatherS2 to USB and run `make test-buttons PORT=/dev/cu.usbmodem...`.
This temporarily stops audio/lighting and polls the configured button pins
every 5 ms for 20 seconds, using the deployed debounce settings. Press and
release BOOT several times after the host prompt. Results show the saved role,
pin configuration, raw levels (`0=pressed`, `1=released`), transitions, and
accepted presses; output appears after the test, then the normal app resumes.
It needs no firmware/app update. No raw transitions means input, configuration,
or physical button operation needs investigation; transitions and accepted
presses isolate the remaining investigation to the normal app/effect path.
Do not treat a received effect name by itself as proof a specific press worked.

For later external buttons, set `button_next_gpio` and optionally
`button_previous_gpio` in the producer profile. Each switch connects its GPIO
to GND; the app enables internal pull-ups. Set a pin to `None` to disable that
control. Keep GPIO 5/6/9 for the microphone and GPIO 38 for the wing.

Coordinates are `(axial, angle)` for each physical pixel: axial runs from -1 at
one end of the culvert through 0 at the player to +1 at the other end; angle is
0..1 turns around the circumference. The default wing previews the entire
length. Give each wireless wing its own coordinate interval to distribute the
field, or use identical positions for mirrored previews. The follower example
covers -0.6..-0.4. Pulse speed is artistic (half-lengths/second), not sound speed.
The default index order is a logical line; supply `pixel_positions` in actual
LED wiring order for a spatial 4×8 layout. Each wireless wing keeps 32 pixels;
do not multiply a node's count by the number of wireless nodes.

## Files and checks

- `lights_app.py`: confirmed GPIOs, I2S capture, leader/follower loop, diagnostics.
- `config.py`, `node_config.py`: shared defaults and per-node overrides.
- `audio_spectrum.py`: window, FFT and spectral measurements.
- `audio_features.py`: simultaneous normalized features and event logic.
- `animation.py`, `effects.py`: native-array layered rendering, effect library,
  bounded pulse pool, trails and button debounce.
- `radio_protocol.py`, `wireless.py`: tested packet logic and ESP-NOW transport.
- `sound_reactive.py`: earlier helpers, retained for microphone diagnostics.
- `tests/`: generated PCM and packet-loss scenarios; no recorded audio.

`make check` installs pinned **NumPy 2.2.6** into `.venv` for host FFT tests.
Firmware uses built-in `ulab`; NumPy is never copied to the board. Tests exercise
silence/DC, band placement and RMS, drone frequency/volume variations, equal-RMS
timbre shifts, layered growl/vocal, onsets, normalization, release tails,
brightness bounds, pulse motion, coordinate mapping, packet loss/replay, and
deployment board selection/refusal before writes.

## Original Adafruit Feather ESP32 V2

This board now runs the shared ESP-NOW consumer app with ordinary `make deploy`.
It uses **GPIO 32** for the wing and has no CIRCUITPY USB drive. The previous
rainbow-only app is preserved in `examples/esp32_rainbow.py`; explicitly select
it with `LEGACY_RAINBOW=1`:

```sh
make deploy BOARD=adafruit_feather_esp32_v2 LEGACY_RAINBOW=1
make console BOARD=adafruit_feather_esp32_v2
```

Its firmware installation command is
`make flash BOARD=adafruit_feather_esp32_v2`. This command checks the 8 MB
ESP32-PICO-V3-02, backs up all flash, erases it, and installs CircuitPython.
At the reliable 115200 baud rate, allow about 13 minutes for the backup and
2–3 minutes for flashing. Use it only for firmware installation.

The original board's rainbow was deployed and visually confirmed on September
15, 2026. Its original 8 MB backup remains at
`.artifacts/flash-backup-1789492118517035000.bin`.

## Hardware history — September 15, 2026

- Identified ESP32-S2 revision 0.0, 16 MB flash, MAC `7c:df:a1:03:4c:2c`.
- Upgraded from CircuitPython 6.2.0-beta.1 to 10.3.1 through ROM recovery;
  esptool verified the written firmware hash. Holding BOOT while reconnecting
  USB successfully exposed the recovery port on this early board.
- Original full flash saved to `.artifacts/flash-backup-1789494748940767000.bin`;
  original app/library files also backed up separately before upgrading.
- Deployed both app files with readback verification. Microphone test measured
  RMS from **1.2 to 101.5**, with maximum sample span **434**. After restarting,
  a **144.5 RMS** spike triggered a beat and faster rainbow motion.
- The original five signal-processing tests and Python syntax checks passed.
- User reported the wing was completely dark with the initial GPIO 3 setting.
  Corrected the data pin to GPIO 38 by matching physical header positions;
  redeployment passed readback and serial startup checks on GPIO 38.
  User visually confirmed the corrected rainbow works and reacts to claps.

## Current didgeridoo validation

- The effect-number indicator is deployed on both the FeatherS2 producer and
  ESP32 V2 consumer, with all ten application files verified on each. The
  consumer's on-board test generated and wrote all four glyphs: 10/13/13/12 lit
  pixels for numbers 1/2/3/4, peak channel value 38, then resumed reception.
  The producer also rendered and broadcast two automatic cycles (2,3,4,1),
  submitting 188 radio updates with zero reported errors/skips, then resumed
  the microphone app on Culvert. The demo paused audio capture; normal button
  indicators run alongside capture. The user then visually confirmed that
  **both wings show matching, readable effect numbers** during the demo,
  verifying the default orientation and consumer mirroring.
- A consumer redeployment with music playing near the powered producer passed
  all ten file readbacks and startup verification. After joining, eight status
  samples stayed `link=live`, reaching **104 accepted packets, zero rejected**.
  Received volume varied **0.12–0.65**, vocal intensity **0.12–0.46**, and all
  32 pixels had nonzero output, with peak channel values **4–26**. This verifies
  changing producer features reaching the consumer renderer and LED write
  call; it does not establish physical illumination or musical classification.
- 47 deterministic host tests pass; these use generated signals, not labelled
  didgeridoo recordings.
- Both the FeatherS2 producer and Feather ESP32 V2 consumer run CircuitPython
  10.3.1. The ESP32 V2 consumer's ten files passed serial readback and startup
  checks. Real ESP-NOW reception reached **94 accepted packets, zero rejected**
  over its first eight seconds, with `link=live` throughout. Consumer MAC:
  `14:33:5c:97:f2:a0`.
- Producer deployment passed file readback and serial startup checks. Native
  FFT verification placed a 93.75 Hz tone almost entirely in the drone band,
  with RMS 706.65 for a 1000-amplitude sine. Native packet decoding passed.
- [Recorded benchmark results](#recorded-results--september-15-2026) document
  producer timing, overruns, renderer stress, and the scope of radio evidence.
- The earlier clap-reactive rainbow and matching effect-number indicators were
  visually confirmed. The new musical layers still need an instrument trial.
  Culvert classification accuracy and RF coverage are unmeasured.
- Before Spectrum replaced effect 1, both the FeatherS2 producer and ESP32 V2
  consumer received the clearer Culvert renderer. Each deployment passed all ten file readbacks and startup
  checks. The updated consumer accepted **99 packets, zero rejected**, with a
  live link after joining; received volume varied **0.07–1.00** and output peak
  channel values **7–38**. These logs verify changing state reaching the updated
  renderer; physical appearance still needs visual confirmation. The complete
  producer update also supersedes the earlier interrupted USB copy.
- BOOT input was verified directly (ten accepted presses), then the running
  audio app logged all three requested changes: Ember, Aurora, Ripple. This
  establishes the producer's button-to-effect path independently of appearance.

## Human-reviewed sound library

`review/recordings/` is the canonical, intentionally committed review library.
It currently contains two ten-second, 16 kHz, mono, signed 16-bit WAVs and their
authoritative human-label JSON:

- `drone-yell-10s.wav`, SHA-256
  `efa8b234ee94c014437b7d48fd6f612cd8aed68bb49764d009c5cb97f7cfafa2`:
  drone 2250–10000 ms and yell 4250–4750 ms.
- `high-yell-01.wav`, SHA-256
  `d96ef870ca8fe8a96dff2867de41d47002a7700ff73c6fe66d56637bef6a72bb`:
  drone 1020–6950 ms and yell 2950–3050 ms.

These recordings are approved exceptions to the normal rule against committed
recordings. They are review evidence, not hi-fi references or proof of general
classifier accuracy. Human labels are authoritative; detector output may be
compared with them but must never rewrite them. Transient markers are unlabelled
attack observations, not substitutes for yell or drone labels.

The online [Sound review](https://digirdu-lights.firebaseapp.com/review.html)
reuses the fleet site's Google sign-in, App Check, and existing administrator
allowlist. The page requests the catalog, derived bundle, and WAV bytes through
authenticated Firebase callables. Raw recordings and bundles are not copied to
public Hosting, and the review controls remain hidden until authorization
succeeds. The dropdown switches between recordings and resets the playhead,
selected label, zoom, pan, replay bounds, and event filters.

The waveform is a normalized peak-amplitude preview; each bar summarizes one
1024-sample hop, about 64 ms at 16 kHz. Directly beneath it, the aligned
spectrogram shows 64 logarithmic frequency bands from 31.25 Hz to 8 kHz. Its
dark-blue-to-yellow colors use a fixed -90 to 0 dBFS range, so intensity remains
comparable when switching recordings. The spectrogram, waveform, labels and
detector markers share one playhead, zoom and horizontal pan. Detected events
are listed one per line.

Recheck CoreAudio device indexes immediately before capture because connected
devices can reorder them:

```sh
ffmpeg -f avfoundation -list_devices true -i ""
make record-review AUDIO_INPUT=1
```

The reviewed takes used the MacBook Air microphone at index 1 on the capture
machine. `AUDIO_INPUT` is uppercase and Make variable names are case-sensitive.
The recorder writes exactly ten seconds of PCM and atomically replaces
`REVIEW_AUDIO`, so use a unique ignored path for experiments rather than
overwriting a committed recording:

```sh
make record-review AUDIO_INPUT=1 \
  REVIEW_AUDIO=.artifacts/samples/review/growl-high-01.wav
```

After creating a matching human-authored labels file, generate the ignored
feature, event, comparison, effect and run artifacts with:

```sh
make sound-review \
  REVIEW_AUDIO=review/recordings/drone-yell-10s.wav \
  REVIEW_LABELS=review/recordings/drone-yell-10s.labels.json
python3 -m http.server 8765 --directory .artifacts/sound-review
```

Then open
`http://127.0.0.1:8765/review.html?catalog=/recordings/catalog.json`. The local
catalog dropdown contains every approved recording from
`review/recordings/catalog.json`. The page keeps the
audio, waveform, labels, detected events, derived features and virtual LEDs on
one playhead. It supports play/pause, scrubbing, zoom and replay around a
selected label. Local `?catalog=` and single-bundle `?data=` loading are
accepted only on `localhost` and `127.0.0.1`; production always uses the
authenticated catalog. Edit labels in the JSON file and regenerate the bundle.
Everything under `.artifacts/sound-review/` is derived and remains ignored.

To browse and play both approved recordings through the local Recording
selector, generate the protected review-library staging and serve the repository
root:

```sh
make review-library
python3 -m http.server 8765
```

Then open
`http://127.0.0.1:8765/web/review.html?catalog=/firebase/functions/review-data/catalog.json`.
Local `?catalog=` loading is also restricted to loopback hosts. It reads the
ignored generated bundles and WAVs directly from
`firebase/functions/review-data/`; those recordings are not copied into the
public web build or Firebase Hosting.

To add an approved recording, put its WAV and matching labels JSON in
`review/recordings/`, add the ordered entry to `catalog.json`, and run:

```sh
make review-library
make web-deploy
```

`make review-library` validates IDs, WAV format, file associations, label
bounds, and deterministic analysis before replacing the ignored deployment
staging under `firebase/functions/review-data/`. `make web-test` depends on that
build, so invalid or stale library data stops `make web-deploy` before Firebase
changes. The committed WAVs are published by the site only through the
administrator-protected callable; do not add them to `web/` or public Hosting.

These takes verify deterministic analysis and the human-review plumbing. They
do not establish generalized yell, growl, rhythm or vocalization accuracy, live
hardware replay equivalence, or culvert RF coverage. Exploratory recordings
remain local and ignored until explicitly approved for this library.

## References

- [FeatherS2 CircuitPython downloads](https://circuitpython.org/board/unexpectedmaker_feathers2/)
- [Unexpected Maker UF2 loader instructions](https://help.unexpectedmaker.com/docs/boards/uf2-bootloader-mode/)
- [FeatherS2 GPIO aliases](https://github.com/adafruit/circuitpython/blob/10.3.1/ports/espressif/boards/unexpectedmaker_feathers2/pins.c)
- [FeatherS2 physical pinout](https://feathers2.io/images/feathers2_pinout_extended2.jpg)
- [CircuitPython I2S microphone API](https://docs.circuitpython.org/en/latest/shared-bindings/audioi2sin/index.html)
- [TDK ICS43434 datasheet](https://invensense.tdk.com/wp-content/uploads/2016/02/DS-000069-ICS-43434-v1.2.pdf)
- [NeoPixel FeatherWing wiring](https://learn.adafruit.com/adafruit-neopixel-featherwing/pinouts)

- [ulab native spectrum utilities](https://micropython-ulab.readthedocs.io/en/latest/ulab-utils.html)
- [CircuitPython ESP-NOW API](https://docs.circuitpython.org/en/latest/shared-bindings/espnow/index.html)

## Saved playing samples and Chroma

The September 16 take is preserved locally at
`.artifacts/samples/didgeridoo-2026-09-16/take1.jsonl`, with a SHA-256 manifest
and capture notes in the same directory. These private samples stay ignored by
Git. Copy that directory separately when moving to another computer.
The original `.artifacts/didgeridoo-take1.jsonl` is retained too.

**These are timestamped feature logs, not raw microphone audio.** They contain
roughly one level/spectrum observation per second plus individual attack/yell
logs. They support animation comparisons, not rerunning FFTs or testing revised
audio classifiers. A future classifier experiment needs a fresh PCM recording.
Section labels are approximate cues, not exactly ten-second ground truth;
there is no recorded final decay segment.

```sh
make replay
open .artifacts/replay.html
# Replay a different compatible feature log:
make replay CAPTURE=path/to/take.jsonl REPLAY_OUTPUT=.artifacts/comparison.html
# Preview normalization fitted to another take (does not edit firmware defaults):
.venv/bin/python tools/replay.py path/to/take.jsonl --calibrate
```

The self-contained HTML player shows **all five current firmware renderers**
side by side, with play/pause, seek and section labels. Re-run the command after
editing effects. It holds measured features between observations and delivers
each event once at its timestamp (rounded up to the next 20 fps frame, with age
correction). Unlogged attack/decay envelopes are reconstructed. An eight-second
**synthetic fade** is clearly labelled; it is not a measurement of reverberation.
The browser amplifies the 0.15-capped pixel output for visibility. It cannot
establish real LED brightness, timing performance or acoustic classification.
The sibling `.json` report contains source checksum, section counts, normalization
statistics and the renderer configuration.

### Effect 5: Chroma

Chroma fills the wing with one smoothly changing color. Low spectral centers
are red, moving through yellow/green/cyan/blue to violet as frequencies rise.
Loudness controls HSV brightness independently; color does not trigger flashes
or add light. Volume rises over 0.06 seconds and falls over 0.8 seconds. Color
blends over 0.3 seconds; below normalized volume 0.10 it holds its last hue while
brightness continues fading. These are exponential time constants, not delays.
The digit **5** appears in cyan when selected, using the existing indicator.

Frequency is a **coarse spectral centroid, not the didgeridoo fundamental**:

1. Use the same eight spectrum levels sent to consumers. Approximate relative
   power with `level ** (2 / spectrum_curve)`, undoing amplitude compression.
2. Weight each band's geometric center `sqrt(low_hz * high_hz)` by that power.
   Shared gain cancels in the weighted average. Band clipping and smoothing
   prevent exact reconstruction of FFT energy.
3. Map the logarithm of that frequency between **153.28 and 350.55 Hz** onto
   hue 0.0–0.75. These are the 10th/90th percentiles of **63 active paired
   spectrum observations** from the saved take, excluding labelled quiet and
   volume below 0.10. Observations outside the range clamp to endpoint colors.
   The full observed range was roughly 97–1871 Hz; percentiles keep rare peaks
   from compressing ordinary playing into a tiny color range.

Tune `chroma_frequency_hz`, `chroma_hue_range`, `chroma_color_s`,
`chroma_attack_s`, `chroma_release_s` and `chroma_min_volume` in `config.py`.
Recalibrate after changing spectrum bands or compression. Bounds are fixed
from the take so a yell cannot instantly redefine the range; existing audio
normalization still adapts slowly. Consumers use the same calculation and
configuration, with minor smoothing/quantization differences possible.

Chroma appends protocol ID 4; previous IDs remain unchanged and packets remain
51 bytes. **Update every consumer before selecting effect 5:** older apps reject
that ID and eventually fade on missing valid packets. Chroma is included in
OTA release 1.0.4. Keep effects 1–4 selected until every board reports 1.0.4.

Validation for this preview: `make check` passed **87 tests**. The local browser
player rendered all five canvases, advanced playback and sought correctly with
no JavaScript errors. USB deployment to FeatherS2 UID `c7fd1a30c4c2` verified
all **18 files**, preserved its producer profile, and restarted I2S, ESP-NOW
and both effect buttons. Startup logged changing microphone levels and one
68.9 ms processing-budget warning against the 64 ms hop; this was not a new
performance benchmark. Chroma's physical appearance is not yet user-confirmed,
and the consumer had not received the preview during this USB test. Startup
remains Spectrum; see OTA operations for release rollout results.

### Public effect replay

The website’s [Effects overview](https://digirdu-lights.firebaseapp.com/effects.html)
includes the five-effect comparison, play/pause/seek controls, and Chroma’s
calibration and blending details for firmware 1.0.6. The saved performance is
from September 16; the animations use the released renderer.

`make replay-web` regenerates `web/assets/effects-replay.json` from `CAPTURE`
(default: the saved take above). The user requested this public visual replay;
the exported asset contains LED frames and section labels, not the original
feature logs or audio. It is a generated snapshot, so regenerate it after changing
the renderers. The normal website build copies this checked-in asset and does
not require access to private captures. Playback starts paused and stops when
the browser tab is hidden. If the asset cannot load, the written guide remains
available. Public playback never controls connected lights.

## Hold to sleep (1.0.5)

On the producer, hold **BOOT/IO0 or the external IO43 button** continuously:

1. At **three seconds**, every pixel turns pure red at the configured 0.15 cap.
2. Red fades linearly to black over the next **three seconds**. Releasing the
   button after the red fade starts does not cancel it or change the effect.
3. The app closes microphone, buttons and ESP-NOW, disables the watchdog and
   Wi-Fi, and requests deep sleep with **no wake alarms**.

A short press changes effects **on release**, with the existing debounce and
number indicator. Sleep works independently of which effect is selected.
`button_sleep_hold_s` and `sleep_fade_s` configure the default 3 + 3 seconds.

The producer alternates repeated 17-byte `DGRS` sleep-control packets with
normal 51-byte `DGRD` v3 feature packets during the fade. Controls include the
producer session, shared sequence number, elapsed fade milliseconds and total
fade duration. Consumers require the configured producer MAC/group and a recent
feature frame from that session. Late receivers join the remaining fade;
duplicates cannot restart it, and losing the link cannot cancel an accepted
sleep. This is best-effort broadcast: a node that misses every command remains
awake. Old apps ignore the control packets, so update **all nodes to 1.0.5**.

**Reset each sleeping board to wake it** (or power-cycle it). Reset starts the
normal boot/OTA check and Spectrum again. A producer reset cannot wake sleeping
consumers over ESP-NOW because their radios are off. Release BOOT before RESET
to avoid the ROM loader. Sleep requests are ignored during the first OTA
health trial; retry after the update confirms and reboots, so intentional sleep
cannot be mistaken for a failed candidate.

CircuitPython can simulate deep sleep while maintaining a USB/BLE host
connection. Use battery or a power-only supply to assess true low-power behavior;
USB logs are not proof of current consumption. The wing/microphone power rails
are not switched off by this firmware, so peripherals can still draw power.
See the official [CircuitPython alarm documentation](https://docs.circuitpython.org/en/latest/shared-bindings/alarm/index.html).

### Sleep output hold (1.0.6)

A 1.0.5 sleep test left one wing pixel white with slight color changes despite
the completed red fade. The cause is not yet proven; the data GPIO was released
when the app unwound its hardware contexts. Version 1.0.6 reclaims that same
wing GPIO, writes a final black frame, waits for it to latch and preserves the
output LOW with `preserve_dios` through CircuitPython cleanup/deep sleep. It is
an output hold, not a wake alarm. Reset restores normal pin initialization.
The fix applies to FeatherS2 IO38 and ESP32 V2 D32 without changing wiring.
The user confirmed the 1.0.6 retest on both boards: both wings faded red to
completely black and stayed black, including the previously white pixel.
Producer logs showed 3.117 seconds from sleep request to alarm handoff, with
no application traceback. Resetting each board then restored sound response
on both wings, as visually confirmed by the user. Holding a pin can add some sleep current; electrical
power consumption remains unmeasured.

### Unexpected pixels after sleep: hardware protection

**Status: deferred at the user's request (September 20, 2026).** Resume when
requested. The affected board(s) and dependence on USB versus battery power
are still unknown. No proposed resistor or power-switch modification has been
installed. Start by identifying the affected wing and observing it asleep
before resetting it; then compare USB-connected and battery-only operation.

The user subsequently reported intermittent bright pixels after long-press
sleep, including battery operation. The earlier passing test does not establish
that the symptom is eliminated. App 1.0.8 still sends black, drives the wing
GPIO LOW and requests `preserve_dios`; no new software fix has been validated.
A quiet USB console cannot distinguish simulated sleep from a stopped app.

For a floating-input hypothesis, a practical first hardware test is a **10 kΩ
pull-down resistor from the selected data GPIO to GND**, placed near the wing:

| Board | Resistor connections (controller side of the wing's level shifter) |
| --- | --- |
| Original FeatherS2 producer | IO38 → 10 kΩ → GND |
| Feather ESP32 V2 consumer | D32/GPIO32 → 10 kΩ → GND |

Power down before wiring. This is a resistor to ground, not a direct short;
it biases the signal LOW when the MCU releases it. It cannot clear a color
already latched in a powered pixel or prove the cause of an intermittent fault.
The FeatherWing's labelled DIN pad is on the **level-shifted output** side;
use the selected GPIO/header connection for this input pull-down.

For dependable darkness independent of a floating pin or MCU failure, switch
**the wing's LED/level-shifter power** off with a suitable default-off high-side
load switch. Keep grounds connected and data LOW while the wing is unpowered.
The wing accepts **both VBAT and VUSB through diodes**: cutting only one source
leaves the other able to power it. Isolate both wing feeds or switch their
combined supply, while preserving power to the MCU. There is no configured
wing power-enable GPIO in this project; this requires a reviewed hardware
modification and corresponding firmware, not an OTA-only change. Do not connect
LED power directly to a GPIO or assign a switch pin without checking conflicts.

Test with laptop USB attached, then battery-only after a fresh reset. Confirm
both red fades finish, leave the boards asleep long enough to reproduce the
intermittent symptom, and check reset restores normal effects. USB connection
changes alone are not proof of true deep sleep or measured battery savings.

Sources: [FeatherWing power and level-shifter wiring](https://learn.adafruit.com/adafruit-neopixel-featherwing/pinouts),
[CircuitPython sleep and pin-preservation behavior](https://docs.circuitpython.org/en/latest/shared-bindings/alarm/index.html).
The pull-down and switched-power suggestions are circuit-design recommendations,
not modifications already installed or verified on these boards.

### OTA activity light (USB base 1.0.3)

During the boot-time OTA check, download, or confirmation report, one cyan
pixel advances along the 32-pixel wing about every half-second, wrapping
around after pixel 32. Indicator brightness is **3%** (GRB `7, 0, 7` after
integer rounding); audio effects retain their separate **15%** cap.
This shows activity, not percentage complete; blocking Wi-Fi/TLS operations
hold the current pixel until they return. The indicator clears and releases
the wing pin before normal audio effects start, including when Wi-Fi fails.
The existing full-wing blue flash still marks the USB maintenance window.

Install this optional **USB base 1.0.3** with `make deploy-base` on each board.
For FeatherS2, first tap RESET, then press/release BOOT during the blue flash.
The deploy command backs up and verifies the base files, preserving credentials,
node settings, recovery app and OTA slots. A normal RESET afterward checks OTA
and shows the new indicator. This base change cannot be delivered through an
app-only OTA release. The sound-reactive app remains **1.0.6**, and future
compatible app bundles still accept base 1.0.1.

## Battery voltage: effect 6 and device reports (app 1.0.8 / base 1.0.4)

Press/release the producer's BOOT or IO43 button to cycle
**Spectrum → Ember → Aurora → Ripple → Chroma → Battery → Spectrum**.
The effect selection is broadcast; **each board displays its own voltage**.
The producer's voltage is never substituted for a consumer's reading.

After the dim amber number 6, the portrait 4×8 wing shows a persistent
battery gauge. Numeric voltage is available in device reports. The gauge fills across
**3.3–4.2 V**, with red/amber/green coloring. It is a voltage scale, **not charge
percentage**. It stays visible in silence and after radio loss. The same
portrait rotation/custom mapping as the effect-number indicator applies.
Audio processing and radio continue; short press returns to Spectrum, and
the three-second hold still triggers shared red-fade sleep.

The display uses a separate **3% cap** and samples every two seconds.
Tune `battery_brightness`, `battery_sample_s`, and `battery_voltage_range`
in Config. App 1.0.8 removes the scrolling text; base 1.0.4 remains compatible.
Readings use eight ADC samples plus a discarded initial conversion. They are
approximate; compare with a multimeter before changing the shared reader's
`CALIBRATION_GAIN` in `battery.py`.

| Board | Sensor and display |
| --- | --- |
| Adafruit Feather ESP32 V2 | Factory BAT/JST divider on ADC1 GPIO35, `board.VOLTAGE_MONITOR`; double the measured ADC voltage. No added wiring. |
| Original Unexpected Maker FeatherS2 | No onboard battery sensor. Reports `unsupported` and displays two amber dashes. An external divider/sensor and explicit future wiring configuration are required. |

The hardware assignments follow [Adafruit's pinout](https://learn.adafruit.com/adafruit-esp32-feather-v2/pinouts)
and the [FeatherS2 manufacturer FAQ](https://feathers2.io/). Do not use the S2
microphone's GPIO9/SCL for I2C battery sensing. No extra sensor pins are claimed.

Each boot check-in and confirmation report includes, for example,
`"battery": {"voltage": 3.876, "status": "measured"}`. Unsupported hardware,
ADC failures, or readings outside 2.0–4.5 V use `voltage: null` with status
`unsupported`, `read_error`, or `out_of_range`; a failed refresh clears the old
reading. Older bases can still submit reports without this field.
The dashboard labels the value **Battery terminal (last report)**: it is a
startup snapshot, not a live feed. It does not measure a USB power bank's
remaining charge, and a charger can produce a plausible BAT voltage with no
battery attached. A numeric reading is not battery-presence detection.

### Install

1. Deploy the backward-compatible device API, then install **USB base 1.0.4**
   using `make deploy-base` on each board. FeatherS2 requires BOOT-after-RESET
   maintenance mode. This preserves credentials, node settings and app slots.
2. Reset normally to check OTA and install **app 1.0.7**. Its manifest requires
   base 1.0.4 because the shared `battery.py` reader is part of the USB base.
3. Update every consumer before selecting effect 6. Older apps reject that
   effect ID; the feature packet stays protocol v3 and does not carry voltage.

The saved didgeridoo take contains no battery measurements. Replay continues
to render only the five audio effects; no battery data is invented.

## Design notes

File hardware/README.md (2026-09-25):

# Hardware

- [Producer enclosure](producer/README.md): Adafruit ESP32-S3 Reverse TFT Feather,
  ICS43434 microphone, LiPo, display and buttons. Current mechanical release: 11.

Keep each new part in its own directory. Hardware revisions are independent of
firmware versions. Read [the hardware guidance](AGENTS.md) before editing models.

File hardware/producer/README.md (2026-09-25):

# Producer enclosure

The DidgeLights handheld producer enclosure fits an **Adafruit ESP32-S3 Reverse
TFT Feather (product 5691)**, an **ICS43434 microphone breakout** and a **350 mAh
LiPo**. It includes a screen window, three main buttons, a short flush reset,
a recessed microphone port, and a rear pop-in USB opening.

The mechanical baseline is **Revision 11**. The user reported saving this model
in Fusion on September 24, 2026. Firmware deployment and board support remain
separate from this mechanical release; the root FeatherS2 notes describe a
different board.

## Start here

- [Complete editable Fusion model](revision-11/DidgeLights-enclosure-v11.f3d)
- [Print choices and assembly instructions](revision-11/README.md)
- [Revision 11 verification](revision-11/verification.json)
- [File sizes and SHA-256 hashes](revision-11/bundle-manifest.json)
- [Editing, verification and packaging workflow](WORKFLOW.md)

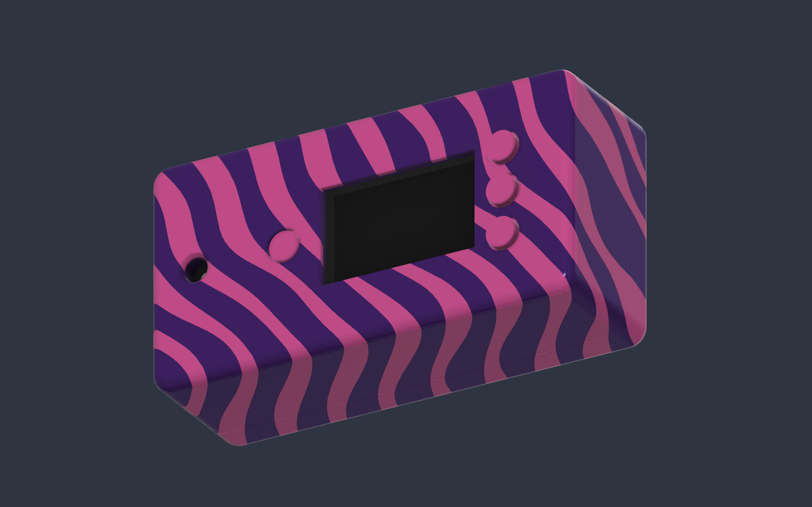
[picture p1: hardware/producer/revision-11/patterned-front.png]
Producer enclosure, pink and purple organic stripes


## Current design

| Item | Design baseline |
| --- | --- |
| Enclosure envelope | Approximately 70.9 × 36.46 × 23.6 mm |
| Battery allowance | User-measured 20 × 38 × 6 mm LiPo, JST connection, rear recess |
| Microphone breakout | User-measured 12.6 × 16.9 × 2.6 mm, opposite Feather USB end |
| Microphone opening | 4 mm throat with 5 mm entrance from a 0.5 mm, 45° recess |
| Rear pop-in USB opening | 14.2 × 5.4 mm, locally reduced to a 2 mm panel thickness |
| On-board USB opening | Removed from case; rear pop-in port retained |
| Fasteners | Two M2 × 20 mm socket-cap screws; recessed head pockets |
| Locating pegs | Tapered, 2.3 mm root / 1.5 mm tip; 2.6 mm receiving holes |
| Colors | Pink/purple organic oblique stripes, flush 0.8 mm exterior regions |

These describe the saved design and supplied measurements, not universal
dimensions for every compatible-looking board or socket. The earlier generic
Feather mounting assumptions were corrected during fitting. Inspect the native
model before changing board mounts.

Revision 11 adds optional one-piece button sets on removable **0.2 mm frames**.
Both flat and domed versions include three main buttons and the short flush reset.
All three standalone plunger variants remain included. Use a 0.2 mm first layer;
cut off and remove the carrier before installing the PCB. See the detailed
assembly instructions. CAD/mesh checks passed; physical carrier behavior still
needs confirmation with the selected filament and print settings.

## File preservation

The 30 files under `revision-11/` were imported byte-for-byte from the verified
Revision 11 print kit. Its original manifest and baseline checks are preserved.
The duplicate ZIP is intentionally ignored; it can be recreated using the
workflow below. Earlier full revisions and scratch experiments remain in the
original local design workspace and are not needed to open the current F3D.

`previous-bambu-project/DidgeLights-v10-H2D.3mf` is explicitly a prior slicer
project, containing loose buttons rather than the new carriers. The user handles
Bambu Studio and printing; the printer used for this project is a Bambu Lab H2D.

## Reference attribution

The electronic board reference is by **Adafruit Industries**, from the
[5691 Feather ESP32-S3 Reverse TFT CAD directory](https://github.com/adafruit/Adafruit_CAD_Parts/tree/main/5691%20Feather%20ESP32%20S3%20Reverse%20TFT).
See Adafruit's [board repository](https://github.com/adafruit/Adafruit-ESP32-S3-Reverse-TFT-Feather-PCB)
for source attribution and licensing. The enclosure is specific to this board;
do not infer that its mounting layout matches every Feather.

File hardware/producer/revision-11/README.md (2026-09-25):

# DidgeLights revision 11 — four-button assembly carriers

Two new optional prints hold all four plungers in their correct positions on a removable rectangular frame around the TFT. Each print includes three main plungers plus the existing short flush reset. The frame is 0.2 mm thick, the rails are 1.2 mm wide, and four sacrificial links are 0.6 mm wide. A small lift tab helps remove the frame.

The covers, zebra pattern and individual button geometry are unchanged from revision 10.

## Choose one button arrangement

| File | Print quantity | Contents |
| --- | --- | --- |
| button-carrier-domed.stl | 1 | Three domed main buttons and one flush reset, joined by a removable frame |
| button-carrier-flat.stl | 1 | Three flat main buttons and one flush reset, joined by a removable frame |
| button-plunger-domed.stl | 3 | Separate domed main buttons, as before |
| button-plunger-flat.stl | 3 | Separate flat main buttons, as before |
| reset-plunger-flush.stl | 1 | Separate flush reset, for use with either separate main-button choice |

Use one carrier OR three separate main buttons plus one separate reset. A carrier already contains its reset button. Do not print extra plungers for the same assembly.

## Printing and installation

The carrier STLs are already oriented with the flat brims and frame on the bed and the button caps pointing up. Use a **0.2 mm first layer** so the entire carrier frame is one layer thick. Inspect the first-layer preview for all four connecting links. The frame and buttons should print as one connected piece. Peel it off carefully; this is a sacrificial assembly aid, not a durable handle.

1. Support the front cover face down with room beneath the holes for the raised main button caps. Leave the PCB out.
2. Insert all four stems together. The three main buttons go on one side of the TFT; the short reset goes on the opposite side. The carrier rests against the inside of the cover, holding the buttons approximately 0.2 mm above their final seats. Do not force them down while still connected.
3. Support the buttons in their holes and snip the four narrow links flush to the outer edges of the retaining brims. Avoid nicking the brim or stem.
4. Lift out the entire rectangular frame using its pull tab. Remove any loose offcuts and trim protruding link stubs flush. Fully seat each button in its pocket.
5. Install the board and finish the enclosure. Check that each button moves independently and the reset remains flush when unpressed.

**Remove the carrier before installing the board.** It intentionally occupies space needed for the buttons to settle into their final positions. It must not remain inside the assembled case or be left to break during use.

This is a first physical trial of the carrier. CAD checks pass, but survival during bed removal and breakaway behavior still need to be confirmed with your filament and print settings.

## Enclosure and Fusion files

- `DidgeLights-enclosure-v11.f3d`: complete current native assembly. The new `Button carrier - flat` and `Button carrier - domed` components are hidden by default so they do not overlap the regular assembly. Show either component and hide the covers/reference parts to inspect it.
- `front-patterned.3mf` and `rear-patterned.3mf`: unchanged multipart geometry for the pink/purple covers.
- `front-purple.stl` + `front-pink.stl`, and `rear-purple.stl` + `rear-pink.stl`: aligned color regions. Import each cover's pair as parts of one object; preserve their shared placement.
- `plain-front-housing.stl` and `plain-rear-cover.stl`: complete single-color cover alternatives.
- `previous-bambu-project/DidgeLights-v10-H2D.3mf`: unchanged reference copy from the revision 10 bundle. It still contains separate domed buttons, **not** a carrier. Replace those four loose plungers if you choose the carrier. Bambu Studio and printing remain user-controlled.

The carrier sketches are dimensioned and fully constrained. Frame thickness, rail width and link width are exposed as Fusion parameters. The carrier's plungers are exact solid copies of the existing variants; regenerate those copies if the source button geometry changes.

The pink/purple cover pattern remains a flush 0.8 mm exterior partition. Its original parametric plain covers and hidden ribbon tools are retained. Patterned covers are partition snapshots: regenerate them after changing the source covers, rather than exporting an old patterned snapshot.

## Checks

Each carrier is one connected solid, including its first-layer midsection. At 0.21 mm temporary stand-off it has no positive-volume interference with the front cover. Removing the added carrier material recovers the exact original four plungers. Active Fusion features are healthy. Exported carrier meshes are closed, consistently wound and nondegenerate, and native/archive integrity checks pass.

All previous standalone button meshes and patterned/plain cover files are byte-identical to the revision 10 bundle. Their earlier fit checks are carried in `baseline-verification/`. `verification.json` records this revision's checks; `bundle-manifest.json` contains file hashes.

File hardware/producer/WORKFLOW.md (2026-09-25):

# Producer CAD workflow

## Continue editing

1. Read `../AGENTS.md` and the latest revision README. Open the current Fusion
   document or import the complete F3D archive. Confirm the document and components
   before making changes; the original document name was `DidgeLights enclosure v3`.
2. Work in a new revision. Preserve the last released files. Keep intermediate
   exports and safety copies in ignored `work/` or `backups/` directories.
3. Edit the parametric covers and named dimensions. Regenerate patterned-cover
   partitions after cover changes and carrier copies after button changes.
   The hidden carrier components are optional prints, not extra installed parts.
4. Check feature health and relevant fit, button travel, screw and peg clearance.
   For carriers, verify insertion before the PCB and independent buttons after
   frame removal. Physical feedback is distinct from CAD checks.
5. Export the complete F3D, both covers and color regions, every button variant,
   preview images and verification records. Orient print files on the bed in mm;
   keep each cover's color regions aligned. Update the assembly instructions.
6. Generate a manifest for the new revision, verify it, build an ignored print-kit
   ZIP, then run `make check` from the repository root and commit the release files.

The Fusion file contains the current native design; there is no supported script
that reconstructs every historical revision from scratch. Local one-off scripts
were deliberately not imported as a reusable build system.

If using a local Fusion MCP connection, discover its current tools and establish
a fresh session. The original endpoint was `http://127.0.0.1:27182/mcp`; it is a
local service, not a hosted project dependency. Use one Fusion request at a time
and inspect its returned success/error data, not merely the shell exit code.
Do not commit session IDs or assume the original endpoint is still running.

## Verify and package Revision 11

Run this from the repository root. It checks every imported file against the
original manifest before creating a bundle under ignored `hardware/producer/dist/`.
The archive contains the same files as the delivered kit; ZIP metadata/compression
may differ, so the ZIP file's own hash need not match the original.

```sh
python3 - <<'PY'
import hashlib
import json
from pathlib import Path
from zipfile import ZIP_DEFLATED, ZipFile

release = Path('hardware/producer/revision-11')
manifest = json.loads((release / 'bundle-manifest.json').read_text())
names = [entry['file'] for entry in manifest['files']]
assert len(names) == len(set(names)), 'Duplicate manifest entries'
for entry in manifest['files']:
    data = (release / entry['file']).read_bytes()
    assert len(data) == entry['bytes'], entry['file']
    assert hashlib.sha256(data).hexdigest() == entry['sha256'], entry['file']
names.append('bundle-manifest.json')
assert set(names) == {
    path.relative_to(release).as_posix()
    for path in release.rglob('*') if path.is_file()
}, 'Unlisted or missing release files'
dest = Path('hardware/producer/dist/DidgeLights-v11-print-kit.zip')
dest.parent.mkdir(parents=True, exist_ok=True)
with ZipFile(dest, 'w', ZIP_DEFLATED) as archive:
    for name in names:
        archive.write(release / name, 'DidgeLights-v11-print-kit/' + name)
with ZipFile(dest) as archive:
    assert archive.testzip() is None
    for name in names:
        assert archive.read('DidgeLights-v11-print-kit/' + name) == (release / name).read_bytes()
print(f'Verified and packaged {len(names)} files: {dest}')
PY
```

The manifest proves release-file identity. Geometric and mesh results are in
`revision-11/verification.json`; unchanged earlier checks are in its
`baseline-verification/` directory. Future geometry changes require new checks,
not just new hashes.

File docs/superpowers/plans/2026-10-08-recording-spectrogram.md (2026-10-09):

# Recording Spectrogram Implementation Plan

> **For agentic workers:** REQUIRED SUB-SKILL: Use superpowers:subagent-driven-development (recommended) or superpowers:executing-plans to implement this plan task-by-task. Steps use checkbox (`- [ ]`) syntax for tracking.

**Goal:** Add a deterministic log-frequency spectrogram beneath the recording waveform and display each detected event on its own line.

**Architecture:** The offline Python review pipeline computes a compact 64-row, fixed-dBFS spectrogram from each existing PCM hop and embeds it in review bundle schema version 2. A focused browser module validates and rasterizes the payload; the existing review page places its canvas in the waveform timeline so zoom, pan, seek, and playhead state stay shared.

**Tech Stack:** Python 3, NumPy, `unittest`, browser ES modules, Canvas 2D, Node test runner, Playwright, Firebase review-library generation.

**Repository note:** Do not create commits unless the user explicitly authorizes them. The checkpoints below end with verification and `git diff` review rather than automatic commits.

---

## File Map

- Modify `tools/sound_review.py`: generate the fixed-scale spectrogram and add it to analysis and review bundles.
- Modify `tests/test_sound_review.py`: cover silence, deterministic tone placement, and schema-version-2 artifact output.
- Modify `tests/test_review_library.py`: verify generated authenticated-library bundles carry aligned spectrogram data.
- Create `web/spectrogram.mjs`: validate spectrogram payloads, map intensities to the approved palette, and paint a DPR-aware canvas.
- Create `web/test/spectrogram.test.mjs`: unit-test browser-side validation and raster ordering without a browser.
- Modify `tools/build_web.mjs`: copy the standalone spectrogram module into built web output.
- Modify `Makefile`: copy the module into local `make sound-review` output.
- Modify `web/review-page.js`: normalize spectrogram data and render it inside the existing shared timeline.
- Modify `web/review.html`: add shared-timeline spectrogram styles, frequency/intensity labels, and a single-column detector list.
- Modify `web/test/app.spec.js`: test layout, shared interactions, switching, missing/malformed data, and one-event-per-line behavior.
- Modify `README.md`: replace the “spectrogram is not currently shown” limitation with the implemented display semantics.

### Task 1: Generate a Deterministic Log-Frequency Spectrogram

**Files:**
- Modify: `tests/test_sound_review.py:19-40,391-637`
- Modify: `tools/sound_review.py:1-25,243-255`

- [ ] **Step 1: Write failing generator tests**

Add `from tools import sound_review` beside the existing imports, then add these
focused tests to `SoundReviewAnalysisTests`. The explicit `hasattr` assertions
make the first run fail as a test assertion rather than aborting module import:

```python
def test_spectrogram_preview_maps_silence_to_fixed_floor(self):
    config = Config()
    hops = [array.array("h", [0]) * config.hop_size for _ in range(2)]

    self.assertTrue(hasattr(sound_review, "spectrogram_preview"))
    preview = sound_review.spectrogram_preview(hops, config)

    self.assertEqual(preview["min_frequency_hz"], 31.25)
    self.assertEqual(preview["max_frequency_hz"], 8000.0)
    self.assertEqual(preview["min_dbfs"], -90.0)
    self.assertEqual(preview["max_dbfs"], 0.0)
    self.assertEqual(preview["rows"], 64)
    self.assertEqual(preview["columns"], 2)
    self.assertEqual(preview["frames"], [[0] * 64, [0] * 64])

def test_spectrogram_preview_places_tone_in_expected_log_band(self):
    config = Config()
    frequency_hz = 500.0
    samples = array.array(
        "h",
        (
            round(12000 * math.sin(2 * math.pi * frequency_hz * index / config.sample_rate))
            for index in range(config.hop_size)
        ),
    )

    self.assertTrue(hasattr(sound_review, "spectrogram_preview"))
    first = sound_review.spectrogram_preview([samples], config)
    second = sound_review.spectrogram_preview([samples], config)
    peak_row = max(range(first["rows"]), key=first["frames"][0].__getitem__)
    expected_row = math.floor(
        math.log(frequency_hz / first["min_frequency_hz"])
        / math.log(first["max_frequency_hz"] / first["min_frequency_hz"])
        * first["rows"]
    )

    self.assertEqual(first, second)
    self.assertLessEqual(abs(peak_row - expected_row), 1)
    self.assertGreater(first["frames"][0][peak_row], 0)
    self.assertTrue(all(0 <= value <= 255 for value in first["frames"][0]))
```

- [ ] **Step 2: Run the tests and confirm RED**

Run:

```bash
.venv/bin/python -m unittest \
  tests.test_sound_review.SoundReviewAnalysisTests.test_spectrogram_preview_maps_silence_to_fixed_floor \
  tests.test_sound_review.SoundReviewAnalysisTests.test_spectrogram_preview_places_tone_in_expected_log_band
```

Expected: two assertion failures because `spectrogram_preview` does not exist.

- [ ] **Step 3: Implement the minimal generator**

Import host NumPy in `tools/sound_review.py` and add constants plus the generator immediately after `waveform_preview`:

```python
import numpy as np

SPECTROGRAM_MIN_HZ = 31.25
SPECTROGRAM_MIN_DBFS = -90.0
SPECTROGRAM_MAX_DBFS = 0.0
SPECTROGRAM_ROWS = 64

def spectrogram_preview(hops, config):
    """Return fixed-scale, byte-quantized log-frequency magnitudes per hop."""
    fft_size = config.fft_size
    if config.hop_size != fft_size:
        raise ValueError("Spectrogram preview requires contiguous full FFT hops")
    max_frequency_hz = config.sample_rate / 2.0
    window = np.hanning(fft_size)
    amplitude_scale = 2.0 / (float(np.sum(window)) * 32768.0)
    frequencies = np.fft.rfftfreq(fft_size, 1.0 / config.sample_rate)
    edges = np.geomspace(SPECTROGRAM_MIN_HZ, max_frequency_hz, SPECTROGRAM_ROWS + 1)
    band_indexes = []
    for row, (low_hz, high_hz) in enumerate(zip(edges, edges[1:])):
        upper = frequencies <= high_hz if row == SPECTROGRAM_ROWS - 1 else frequencies < high_hz
        indexes = np.flatnonzero((frequencies >= low_hz) & upper)
        if not len(indexes):
            center_hz = math.sqrt(low_hz * high_hz)
            indexes = np.array([int(np.argmin(np.abs(frequencies - center_hz)))])
        band_indexes.append(indexes)

    floor_amplitude = 10.0 ** (SPECTROGRAM_MIN_DBFS / 20.0)
    frames = []
    for hop in hops:
        if len(hop) != fft_size:
            raise ValueError("Expected one complete PCM hop")
        samples = np.asarray(hop, dtype=float)
        samples -= float(np.mean(samples))
        amplitude = np.abs(np.fft.rfft(samples * window)) * amplitude_scale
        amplitude[-1] *= 0.5
        frame = []
        for indexes in band_indexes:
            peak = max(float(np.max(amplitude[indexes])), floor_amplitude)
            dbfs = max(SPECTROGRAM_MIN_DBFS, min(SPECTROGRAM_MAX_DBFS, 20.0 * math.log10(peak)))
            frame.append(round((dbfs - SPECTROGRAM_MIN_DBFS) * 255.0 / (SPECTROGRAM_MAX_DBFS - SPECTROGRAM_MIN_DBFS)))
        frames.append(frame)
    return {
        "min_frequency_hz": SPECTROGRAM_MIN_HZ,
        "max_frequency_hz": max_frequency_hz,
        "min_dbfs": SPECTROGRAM_MIN_DBFS,
        "max_dbfs": SPECTROGRAM_MAX_DBFS,
        "rows": SPECTROGRAM_ROWS,
        "columns": len(frames),
        "frames": frames,
    }
```

- [ ] **Step 4: Run the focused generator tests and confirm GREEN**

Run the command from Step 2.

Expected: two tests pass with no warnings or errors.

- [ ] **Step 5: Run the complete Python sound-review test module**

Run:

```bash
.venv/bin/python -m unittest tests.test_sound_review
```

Expected: all existing sound-review tests still pass.

### Task 2: Add Spectrogram Data to Review Bundle Schema Version 2

**Files:**
- Modify: `tests/test_sound_review.py:1193-1240`
- Modify: `tests/test_review_library.py:103-134`
- Modify: `tools/sound_review.py:527-589,1140-1160`

- [ ] **Step 1: Write failing artifact and library assertions**

Update `test_artifacts_include_a_deterministic_browser_review_bundle` so its expected key set includes `"spectrogram"`, its expected schema version is `2`, and it asserts alignment:

```python
self.assertEqual(bundle["schema_version"], 2)
self.assertEqual(bundle["spectrogram"]["columns"], len(bundle["waveform"]))
self.assertEqual(bundle["spectrogram"]["rows"], 64)
self.assertTrue(
    all(
        len(frame) == bundle["spectrogram"]["rows"]
        for frame in bundle["spectrogram"]["frames"]
    )
)
```

In `test_build_is_ordered_deterministic_and_removes_stale_entries`, add:

```python
self.assertEqual(bundle["schema_version"], 2)
self.assertEqual(bundle["spectrogram"]["columns"], len(bundle["waveform"]))
self.assertEqual(bundle["spectrogram"]["rows"], 64)
```

- [ ] **Step 2: Run the bundle tests and confirm RED**

Run:

```bash
.venv/bin/python -m unittest \
  tests.test_sound_review.SoundReviewEffectTests.test_artifacts_include_a_deterministic_browser_review_bundle \
  tests.test_review_library.ReviewLibraryTests.test_build_is_ordered_deterministic_and_removes_stale_entries
```

Expected: failures for missing `spectrogram` and schema version `1`.

- [ ] **Step 3: Integrate the generator into analysis and artifact output**

Add the preview to the `analyze_wav` result:

```python
return {
    "info": info,
    "labels": labels,
    "waveform": waveform_preview(hops),
    "spectrogram": spectrogram_preview(hops, config),
    "features": features,
    "events": list(events),
    "comparison": comparison,
    "fps": fps,
    "feature_fps": config.sample_rate / config.hop_size,
    "detector_config": _serialize_detector_config(detector.config),
}
```

Update only the browser review bundle schema number and payload in `build_artifacts`:

```python
{
    "schema_version": 2,
    "duration_ms": result["info"]["duration_ms"],
    "sample_rate_hz": result["info"]["sample_rate_hz"],
    "audio_url": audio_url,
    "waveform": result["waveform"],
    "spectrogram": result["spectrogram"],
    "labels": result["labels"]["labels"],
    "features": result["features"],
    "events": result["events"],
    "comparison": result["comparison"],
    "effects": result["effects"],
}
```

Keep the run-manifest schema at `1`; it is a separate contract.

- [ ] **Step 4: Run focused bundle tests and confirm GREEN**

Run the Step 2 command with the confirmed class names.

Expected: both tests pass.

- [ ] **Step 5: Verify deterministic library generation**

Run:

```bash
.venv/bin/python -m unittest tests.test_review_library tests.test_sound_review
```

Expected: both modules pass, including byte-for-byte repeated library generation and unchanged labels.

### Task 3: Validate and Rasterize Spectrograms in a Focused Browser Module

**Files:**
- Create: `web/spectrogram.mjs`
- Create: `web/test/spectrogram.test.mjs`

- [ ] **Step 1: Write failing browser-module unit tests**

Create `web/test/spectrogram.test.mjs`. Import dynamically inside each test so
the first run produces assertion failures rather than an uncaught module-load
error:

```javascript
import assert from 'node:assert/strict';
import test from 'node:test';
const valid={
  min_frequency_hz:31.25,max_frequency_hz:8000,
  min_dbfs:-90,max_dbfs:0,rows:2,columns:2,
  frames:[[0,255],[64,128]],
};

async function loadModule(){
  return import('../spectrogram.mjs').catch(()=>null);
}

test('missing spectrogram remains backward compatible',async()=>{
  const module=await loadModule();
  assert.ok(module,'spectrogram module should exist');
  assert.equal(module.normalizeSpectrogram(undefined,2),null);
});

test('normalizes aligned byte frames and rasterizes high frequencies on top',async()=>{
  const module=await loadModule();
  assert.ok(module,'spectrogram module should exist');
  const normalized=module.normalizeSpectrogram(valid,2);
  const rgba=module.spectrogramRgba(normalized);
  assert.equal(rgba.length,2*2*4);
  assert.deepEqual([...rgba.slice(0,4)],[255,207,106,255]);
  assert.deepEqual([...rgba.slice(8,12)],[7,11,35,255]);
});

test('rejects malformed or horizontally misaligned spectrograms',async()=>{
  const module=await loadModule();
  assert.ok(module,'spectrogram module should exist');
  assert.throws(()=>module.normalizeSpectrogram({...valid,columns:3},2),/columns/);
  assert.throws(()=>module.normalizeSpectrogram({...valid,frames:[[0,256],[64,128]]},2),/byte/);
  assert.throws(()=>module.normalizeSpectrogram({...valid,min_dbfs:0,max_dbfs:-90},2),/dB/);
});
```

- [ ] **Step 2: Run the module test and confirm RED**

Run:

```bash
node_modules/.bin/node --test web/test/spectrogram.test.mjs
```

Expected: three assertion failures stating that the spectrogram module should exist.

- [ ] **Step 3: Implement validation, palette interpolation, and canvas painting**

Create `web/spectrogram.mjs` with these exported interfaces:

```javascript
const PALETTE=[
  {at:0,rgb:[7,11,35]},
  {at:.35,rgb:[22,93,117]},
  {at:.68,rgb:[212,91,114]},
  {at:1,rgb:[255,207,106]},
];

function finite(value,name){
  if(typeof value!=='number'||!Number.isFinite(value))throw new Error(`${name} must be finite`);
  return value;
}

function positiveInteger(value,name){
  if(!Number.isInteger(value)||value<=0)throw new Error(`${name} must be a positive integer`);
  return value;
}

export function normalizeSpectrogram(value,waveformColumns){
  if(value===undefined)return null;
  if(!value||typeof value!=='object'||Array.isArray(value))throw new Error('spectrogram must be an object');
  const rows=positiveInteger(value.rows,'spectrogram rows');
  const columns=positiveInteger(value.columns,'spectrogram columns');
  if(columns!==waveformColumns)throw new Error('spectrogram columns must match waveform');
  const minFrequencyHz=finite(value.min_frequency_hz,'minimum frequency');
  const maxFrequencyHz=finite(value.max_frequency_hz,'maximum frequency');
  if(minFrequencyHz<=0||maxFrequencyHz<=minFrequencyHz)throw new Error('spectrogram frequency bounds are invalid');
  const minDbfs=finite(value.min_dbfs,'minimum dBFS');
  const maxDbfs=finite(value.max_dbfs,'maximum dBFS');
  if(maxDbfs<=minDbfs)throw new Error('spectrogram dB bounds are invalid');
  if(!Array.isArray(value.frames)||value.frames.length!==columns)throw new Error('spectrogram frame count is invalid');
  const frames=value.frames.map(frame=>{
    if(!Array.isArray(frame)||frame.length!==rows)throw new Error('spectrogram row count is invalid');
    return frame.map(sample=>{
      if(!Number.isInteger(sample)||sample<0||sample>255)throw new Error('spectrogram values must be bytes');
      return sample;
    });
  });
  return {minFrequencyHz,maxFrequencyHz,minDbfs,maxDbfs,rows,columns,frames};
}

function colorFor(value){
  const position=value/255;
  const right=PALETTE.findIndex(stop=>position<=stop.at);
  if(right<=0)return PALETTE[0].rgb;
  const low=PALETTE[right-1],high=PALETTE[right];
  const mix=(position-low.at)/(high.at-low.at);
  return low.rgb.map((channel,index)=>Math.round(channel+(high.rgb[index]-channel)*mix));
}

export function spectrogramRgba(spectrogram){
  const rgba=new Uint8ClampedArray(spectrogram.columns*spectrogram.rows*4);
  spectrogram.frames.forEach((frame,x)=>frame.forEach((value,row)=>{
    const y=spectrogram.rows-1-row;
    const offset=(y*spectrogram.columns+x)*4;
    rgba.set([...colorFor(value),255],offset);
  }));
  return rgba;
}

export function paintSpectrogram(canvas,spectrogram,devicePixelRatio=1){
  const width=Math.max(1,Math.round(canvas.clientWidth*devicePixelRatio));
  const height=Math.max(1,Math.round(canvas.clientHeight*devicePixelRatio));
  canvas.width=width;canvas.height=height;
  const source=document.createElement('canvas');
  source.width=spectrogram.columns;source.height=spectrogram.rows;
  source.getContext('2d').putImageData(new ImageData(spectrogramRgba(spectrogram),spectrogram.columns,spectrogram.rows),0,0);
  const context=canvas.getContext('2d');
  context.imageSmoothingEnabled=false;
  context.drawImage(source,0,0,width,height);
}
```

- [ ] **Step 4: Run the module tests and confirm GREEN**

Run:

```bash
node_modules/.bin/node --test web/test/spectrogram.test.mjs
```

Expected: all three spectrogram module tests pass.

### Task 4: Render the Shared Timeline and Stack Detector Events

**Files:**
- Modify: `web/review.html:12-52,88-94,105-111`
- Modify: `web/review-page.js:1-120,420-560`
- Modify: `web/test/app.spec.js:91-405`
- Modify: `tools/build_web.mjs:8-10`
- Modify: `Makefile:84-92`

- [ ] **Step 1: Extend browser fixtures and write failing UI assertions**

Add a helper near the review fixtures in `web/test/app.spec.js` and include a matching payload in every fixture intended to exercise current schema behavior:

```javascript
function testSpectrogram(columns){
 return {min_frequency_hz:31.25,max_frequency_hz:8000,min_dbfs:-90,max_dbfs:0,
  rows:3,columns,frames:Array.from({length:columns},(_,column)=>[0,80+column*20,255-column*20])};
}
```

Add one browser test that verifies layout and shared interaction:

```javascript
test('review stacks a log spectrogram under the waveform on the shared timeline',async({page})=>{
 await routeReviewBundle(page,'/spectrogram-review.json');
 await page.goto('/review.html?data=/spectrogram-review.json');
 const amplitude=page.locator('.waveform-region');
 const spectrogram=page.locator('.spectrogram-region');
 await expect(page.locator('#review-spectrogram')).toBeVisible();
 const amplitudeBox=await amplitude.boundingBox();
 const spectrogramBox=await spectrogram.boundingBox();
 expect(spectrogramBox.y).toBeGreaterThanOrEqual(amplitudeBox.y+amplitudeBox.height);
 expect(Math.abs(spectrogramBox.width-amplitudeBox.width)).toBeLessThanOrEqual(1);
 await expect(spectrogram).toContainText('8 kHz');
 await expect(spectrogram).toContainText('31 Hz');
 await expect(spectrogram).toContainText('-90 dBFS');
 const waveform=page.locator('#review-waveform');
 const box=await waveform.boundingBox();
 await waveform.click({position:{x:box.width/2,y:spectrogramBox.y-box.y+spectrogramBox.height/2}});
 expect(Number(await page.getByRole('slider',{name:'Position'}).inputValue())).toBeGreaterThanOrEqual(495);
 await page.getByRole('slider',{name:'Zoom'}).fill('4');
 await page.getByRole('slider',{name:'Zoom'}).dispatchEvent('input');
 await expect(waveform).toHaveAttribute('data-zoom','4');
});
```

Extend the event-filter test after enabling Transient so it verifies distinct rows:

```javascript
const eventBoxes=await page.locator('#review-events li').evaluateAll(items=>items.map(item=>item.getBoundingClientRect().toJSON()));
expect(new Set(eventBoxes.map(box=>Math.round(box.y))).size).toBe(eventBoxes.length);
expect(eventBoxes.every(box=>box.width===eventBoxes[0].width)).toBeTruthy();
```

Add missing and malformed payload tests:

```javascript
test('review explains when an older bundle has no spectrogram',async({page})=>{
 await routeReviewBundle(page,'/older-review.json',{spectrogram:undefined});
 await page.goto('/review.html?data=/older-review.json');
 await expect(page.locator('.spectrogram-empty')).toContainText('unavailable');
});

test('review rejects malformed spectrogram bytes',async({page})=>{
 await routeReviewBundle(page,'/invalid-spectrogram.json',{spectrogram:{...testSpectrogram(4),frames:[[0,1,300],[0,1,2],[0,1,2],[0,1,2]]}});
 await page.goto('/review.html?data=/invalid-spectrogram.json');
 await expect(page.locator('#review-status')).toContainText(/could not load/i);
});
```

Replace `routeReviewBundle` with an override-aware helper that preserves the
existing audio route:

```javascript
async function routeReviewBundle(page,url='/gesture-review.json',overrides={}){
 const bundle={
  duration_ms:1000,
  audio_url:'/fixture.wav',
  waveform:[0,.2,.8,.3],
  spectrogram:testSpectrogram(4),
  labels:[{type:'drone',start_ms:200,end_ms:800}],
  events:[{type:'yell',time_ms:500,confidence:.9}],
  features:[{time_ms:500,volume:.8,drone:.7,vocal:.9,transient_strength:.2}],
  comparison:{},
  effects:{frames:{}},
  ...overrides,
 };
 await page.route(`**${url}`,route=>route.request().resourceType()==='document'
  ?route.continue():route.fulfill({json:bundle}));
 await page.route('**/fixture.wav',route=>route.abort());
}
```

Add `spectrogram:testSpectrogram(high?4:3)` to `hostedReview`, use four waveform
samples for the high recording, and assert `#review-spectrogram` has
`data-columns="3"` before switching and `data-columns="4"` afterward. This
proves a recording change replaces the raster rather than retaining stale data.

- [ ] **Step 2: Run focused browser tests and confirm RED**

Run:

```bash
PATH="$(pwd)/node_modules/.bin:$PATH" npm run test:browser -- --project=desktop-chromium --grep='spectrogram|event visibility'
```

Expected: failures because there is no canvas/region, malformed spectrograms are not validated, and events still use a wrapping flex row.

- [ ] **Step 3: Add the shared timeline structure and styles**

In `web/review.html`:

- change the panel heading to `Waveform and spectrogram`;
- change the viewport accessible label to `Audio waveform and log-frequency spectrogram timeline`;
- make `.timeline-track` a stacked container with enough height for an 84 px waveform and a 150 px spectrogram;
- move waveform bars and marker layers into `.waveform-region`;
- add `.spectrogram-region`, `.spectrogram-canvas`, `.spectrogram-axis`, `.spectrogram-legend`, and `.spectrogram-empty` rules;
- keep `.track-cursor` positioned across the complete stacked track; and
- add `#review-events.review-list{display:grid;grid-template-columns:minmax(0,1fr)}` plus full-width list-item styling.

Use these key dimensions and selectors so the browser assertions remain stable:

```css
.timeline-track{position:relative;min-height:234px}
.waveform-region{position:relative;height:84px}
.spectrogram-region{position:relative;height:150px;border-top:1px solid #46314f;background:#070b23}
.spectrogram-canvas{display:block;width:100%;height:100%}
.spectrogram-axis{position:absolute;inset:5px auto 5px 6px;display:flex;flex-direction:column;justify-content:space-between;pointer-events:none;color:#fff;font:10px ui-monospace,monospace;text-shadow:0 1px 3px #000}
.spectrogram-legend{position:absolute;right:7px;bottom:5px;color:#fff;font:10px ui-monospace,monospace;text-shadow:0 1px 3px #000}
.spectrogram-legend::before{content:"";display:inline-block;width:72px;height:8px;margin-right:5px;background:linear-gradient(90deg,#070b23,#165d75,#d45b72,#ffcf6a)}
#review-events.review-list{display:grid;grid-template-columns:minmax(0,1fr)}
#review-events.review-list>li{width:100%;box-sizing:border-box;padding:7px 9px;border:1px solid #46314f;border-radius:5px;background:#0b0a15}
```

- [ ] **Step 4: Normalize and render the spectrogram in the existing page**

At the top of `web/review-page.js`, import the new module:

```javascript
import {normalizeSpectrogram,paintSpectrogram} from './spectrogram.mjs';
```

In `normalizeBundle`, normalize the waveform first, then pass its length into `normalizeSpectrogram`:

```javascript
const waveformRows=Array.isArray(bundle.waveform)?bundle.waveform:[];
return {
  ...bundle,
  duration_ms:durationMs,
  waveform:waveformRows,
  spectrogram:normalizeSpectrogram(bundle.spectrogram,waveformRows.length),
  // existing normalized fields remain unchanged
};
```

Refactor `renderWaveform` to append, in order, a `.waveform-region`, a `.spectrogram-region`, and the shared `.track-cursor`. Put bars and marker layers inside the waveform region. For a current bundle, append this canvas and labels to the spectrogram region:

```javascript
const canvas=document.createElement('canvas');
canvas.id='review-spectrogram';
canvas.className='spectrogram-canvas';
canvas.dataset.columns=String(state.bundle.spectrogram.columns);
canvas.setAttribute('role','img');
canvas.setAttribute('aria-label',`Log-frequency spectrogram from ${state.bundle.spectrogram.minFrequencyHz} Hz to ${state.bundle.spectrogram.maxFrequencyHz} Hz, ${state.bundle.spectrogram.minDbfs} to ${state.bundle.spectrogram.maxDbfs} dBFS`);
spectrogramRegion.append(canvas,frequencyAxis(state.bundle.spectrogram),intensityLegend(state.bundle.spectrogram));
requestAnimationFrame(renderSpectrogramCanvas);
```

For a missing spectrogram, append a `.spectrogram-empty` paragraph containing `Spectrogram unavailable for this older review bundle.`. Implement `renderSpectrogramCanvas` as:

```javascript
function renderSpectrogramCanvas(){
 const canvas=waveform.querySelector('#review-spectrogram');
 if(canvas&&state.bundle?.spectrogram)paintSpectrogram(canvas,state.bundle.spectrogram,window.devicePixelRatio||1);
}
```

Use these helpers for the axis and legend referenced above:

```javascript
function frequencyLabel(value){
 return value>=1000?`${Number((value/1000).toFixed(2))} kHz`:`${Math.round(value)} Hz`;
}

function frequencyAxis(spectrogram){
 const axis=document.createElement('div');
 axis.className='spectrogram-axis';
 axis.append(
  Object.assign(document.createElement('span'),{textContent:frequencyLabel(spectrogram.maxFrequencyHz)}),
  Object.assign(document.createElement('span'),{textContent:frequencyLabel(spectrogram.minFrequencyHz)}),
 );
 return axis;
}

function intensityLegend(spectrogram){
 const legend=document.createElement('div');
 legend.className='spectrogram-legend';
 legend.textContent=`${spectrogram.minDbfs} dBFS → ${spectrogram.maxDbfs} dBFS`;
 return legend;
}
```

Create one observer after `waveformTrack` is available and repaint after zoom:

```javascript
const spectrogramResizeObserver=new ResizeObserver(renderSpectrogramCanvas);
spectrogramResizeObserver.observe(waveformTrack());

function setZoom(value){
 state.zoom=Math.max(1,Math.min(8,Number(value)));
 waveform.dataset.zoom=String(state.zoom);
 waveformTrack().style.setProperty('--timeline-zoom',state.zoom);
 requestAnimationFrame(renderSpectrogramCanvas);
}
```

Do not create a second scroll container or gesture state.

Add `web/spectrogram.mjs` beside the other standalone review modules in both
explicit copy lists:

```javascript
await copyFile('web/spectrogram.mjs',out+'/spectrogram.mjs');
```

```make
	cp web/spectrogram.mjs .artifacts/sound-review/spectrogram.mjs
```

Update `renderLabelOverlays`, `renderEventOverlays`, and their query sites to find layers inside `.waveform-region`; their existing class selectors and behavior otherwise stay unchanged.

- [ ] **Step 5: Run focused browser tests and confirm GREEN**

Run the Step 2 command.

Expected: spectrogram and event-row tests pass in Chromium.

- [ ] **Step 6: Run browser tests in both supported engines**

Run:

```bash
PATH="$(pwd)/node_modules/.bin:$PATH" npm run test:browser -- --grep='review'
```

Expected: all review tests pass in Chromium and WebKit, including existing seek/pan/filter/recording-switch behavior.

### Task 5: Document, Regenerate, and Verify the Complete Change

**Files:**
- Modify: `README.md:1084-1112`
- Generated and ignored: `firebase/functions/review-data/`

- [ ] **Step 1: Update the recording-review documentation**

Replace the current waveform-only limitation with text that states:

```markdown
The waveform is a normalized peak-amplitude preview; each bar summarizes one
1024-sample hop, about 64 ms at 16 kHz. Directly beneath it, the aligned
spectrogram shows 64 logarithmic frequency bands from 31.25 Hz to 8 kHz. Its
dark-blue-to-yellow colors use a fixed -90 to 0 dBFS range, so intensity remains
comparable when switching recordings. The spectrogram, waveform, labels and
detector markers share one playhead, zoom and horizontal pan. Detected events
are listed one per line.
```

- [ ] **Step 2: Rebuild the authenticated review library**

Run:

```bash
make review-library
```

Expected: two recordings are generated under ignored `firebase/functions/review-data/`, each `bundle.json` has schema version `2`, a 64-row spectrogram, and the same number of waveform and spectrogram columns.

- [ ] **Step 3: Run focused Node and browser validation**

Run:

```bash
PATH="$(pwd)/node_modules/.bin:$PATH" npm test
PATH="$(pwd)/node_modules/.bin:$PATH" npm run test:browser -- --grep='review|spectrogram'
```

Expected: Node tests and review browser tests pass in all configured browser projects.

- [ ] **Step 4: Run required repository validation**

Run:

```bash
make check
make web-test
```

Expected: Python compilation/unit tests, Node/function tests, Playwright tests, and Firebase emulator tests all pass. If an unrelated external emulator prerequisite fails, record the exact failing command and output; do not claim full validation.

- [ ] **Step 5: Review the final diff and generated-data boundary**

Run:

```bash
git status --short
git diff --check
git diff -- tools/sound_review.py tests/test_sound_review.py tests/test_review_library.py web/spectrogram.mjs web/test/spectrogram.test.mjs web/review-page.js web/review.html web/test/app.spec.js README.md
```

Expected: only the planned source, test, documentation, design, and plan files are uncommitted; ignored `firebase/functions/review-data/` is absent from `git status`; no WAV, label, credential, recording, or unrelated file changed.

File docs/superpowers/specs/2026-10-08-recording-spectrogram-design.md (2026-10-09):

# Recording Spectrogram Design

## Goal

Add a deterministic spectrogram to the authenticated real-world recording
review page. It must appear directly below the existing peak-amplitude waveform,
share the same timeline interactions, expose frequency content on a logarithmic
axis, and keep each detected event on its own line.

## Scope

This change extends the existing generated review bundle and browser review UI.
It does not alter audio classification, human labels, event matching, firmware,
the radio protocol, or the five-effect public replay.

## Review Layout

The Waveform panel remains the recording's primary timeline. Its timeline track
contains two vertically stacked regions:

1. the existing normalized peak-amplitude bars; and
2. a spectrogram canvas immediately beneath the bars.

The two regions share one horizontal viewport, timeline width, playhead, zoom
factor, scrollbar, click-to-seek gesture, and drag-to-pan gesture. Existing
human-label and detected-event markers remain over the waveform region so they
do not hide spectral detail. The playhead spans both regions.

The spectrogram uses a dark-blue, cyan, magenta, and yellow intensity palette.
It shows logarithmic frequency labels from 31.25 Hz through the 8 kHz Nyquist
limit and a fixed -90 to 0 dBFS intensity legend.
Using a fixed level range makes color intensity comparable across recordings.

The Detected events panel retains its current visibility filters and click-to-
seek behavior. Its list uses a single-column layout so every visible event is a
separate full-width row. Human labels and comparison metrics retain their
existing layouts.

## Spectrogram Data

`tools/sound_review.py` adds a pure spectrogram preview helper and includes its
result in every generated review bundle. It uses the same contiguous 1024-sample
hops and 16 kHz sample rate as the current waveform and feature analysis, so one
spectrogram column aligns with one waveform bar.

Each hop is Hann-windowed and transformed with the host FFT implementation.
Magnitude is converted to dBFS, clamped to the fixed -90 to 0 dBFS display
range, and resampled into 64 logarithmic frequency bands from 31.25 Hz through
Nyquist. Each display band uses the maximum FFT-bin magnitude whose center lies
inside its geometric edges; a band narrower than the FFT spacing uses the
nearest FFT-bin magnitude. Values are quantized to integers from 0 through 255.
Quantization keeps authenticated callable responses compact and makes the
derived artifact deterministic.

The bundle gains a `spectrogram` object containing:

- the frequency and dB bounds;
- the row and column counts; and
- frame-major quantized intensity values.

The review bundle schema version increments for the new field. The recording
library generator rebuilds both tracked-source derived bundles used by Firebase;
the source WAV and human-authored label files remain unchanged.

## Browser Rendering

`web/review-page.js` validates spectrogram metadata, dimensions, and byte values
while normalizing a bundle. A missing spectrogram is accepted for backward
compatibility with older local artifacts and displays a clear unavailable
message. Present but malformed spectrogram data rejects the recording bundle so
the page never presents misleading frequency output.

The renderer paints the quantized values into a canvas, with high frequency at
the top and low frequency at the bottom. It accounts for device pixel ratio and
repaints after bundle changes or relevant size changes. The canvas belongs to
the existing timeline track, so CSS timeline zoom and horizontal scrolling keep
it aligned with waveform bars without maintaining a second pan state.

Selecting another recording resets the existing playhead, selection, zoom,
pan, replay, and event-filter state, then renders that recording's waveform and
spectrogram together. No browser-side audio decoding or duplicate FFT pipeline
is introduced.

## Error Handling

- Silence maps to the fixed dB floor without non-finite values.
- Invalid dimensions, bounds, frame counts, or intensity values reject the
  loaded bundle with the existing review error state.
- A valid older bundle without the optional field shows the waveform and an
  explicit spectrogram-unavailable message.
- Empty detector results continue to show the existing empty-state message.

## Testing

Python unit tests use generated PCM to verify silence, byte bounds, dimensions,
determinism, and placement of a sine wave's strongest energy near its expected
log-frequency row. Artifact and recording-library tests verify that generated
bundles include spectrogram data while labels remain unchanged.

Playwright tests verify that the spectrogram is rendered directly beneath the
waveform, uses the shared timeline through seeking, zooming, panning, and
recording changes, handles missing data, rejects malformed data, and keeps each
visible detected event on a separate row without changing filter or seek
behavior.

The completed change is validated with `make check`.

## Acceptance Criteria

- Each real-world recording shows amplitude and log-frequency content on one
  aligned timeline.
- Color intensity uses the same fixed dBFS range for every recording.
- The existing playhead, zoom, pan, seek, labels, event filters, and recording
  selector continue to work.
- Every visible detected event appears on its own line.
- Generated artifacts are deterministic and authoritative labels are unchanged.
- `make check` passes.

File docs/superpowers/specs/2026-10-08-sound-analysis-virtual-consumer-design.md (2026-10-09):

# Sound Analysis Virtual Consumer Design

Date: 2026-10-08
Status: Approved and implemented

## Goal

Make the sound-analysis review page more concise and useful while preserving the
firmware renderer as the single source of truth. Rename the page to **Sound
Analysis**, keep a synchronized virtual consumer visible in a sticky left rail,
and let the reviewer switch among the five sound-driven effects while viewing a
complete portrait 4×8 FeatherWing matrix.

## Rendering approach

The browser will not reimplement the Python animation engine. The existing
offline review pipeline continues to instantiate `CulvertAnimation` once per
effect and virtual node and render deterministic frames from the analyzed audio
features.

`tools/sound_review.py` will serialize all 32 LEDs from each rendered frame
instead of averaging them into eight groups. Renderer output is physical-order
GRB bytes. The review pipeline will use the shared `FEATHERWING_PORTRAIT`
mapping to reorder those bytes into logical, row-major portrait coordinates and
convert each pixel to RGB. This keeps physical mapping and channel conversion
in Python beside the authoritative firmware definitions. The browser receives
32 RGB triples ready to place in a four-column, eight-row grid.

The effects artifact continues to contain timelines for Spectrum, Ember,
Aurora, Ripple, and Chroma across the existing virtual nodes. Battery remains
excluded because sound-review recordings contain no node-voltage measurements.
Virtual node `0` remains the displayed consumer, preserving current behavior.

The effects artifact metadata will describe a 32-pixel portrait layout with
four columns, eight rows, row-major logical ordering, and RGB channel order.
Generated review-library bundles will be rebuilt from source recordings so the
deployed page and authenticated recording payloads use the same schema.

## Page layout and behavior

`web/review.html` changes its heading from “Human-reviewed sound analysis” to
“Sound Analysis.” The protected review area becomes a desktop two-column grid:
a narrow virtual-consumer rail on the left and the existing recording,
playback, waveform, label, event, feature, and comparison panels on the right.

The virtual-consumer rail contains an Effect label, a native select control,
and the full portrait 4×8 LED matrix. The rail uses sticky positioning below the
site header so it remains visible during analysis scrolling without covering
content. At the existing narrow-screen breakpoint, the layout becomes one
column, the rail moves above the analysis panels, and sticky positioning is
disabled.

The selector is populated in bundle order and is limited to the five available
sound effects. Spectrum is the initial selection. A reviewer’s selected effect
persists while playing, seeking, zooming, selecting labels, and changing
recordings when the new bundle contains that effect. Changing the selection
immediately redraws the nearest frame at the canonical playhead time; it does
not restart audio or reset the playhead.

Playback, manual seeking, label replay, and recording changes continue to use
the existing shared millisecond playhead. The virtual consumer chooses the
nearest frame from the selected effect’s node-`0` timeline, so every effect
remains synchronized with the waveform, features, events, and audio.

## Empty and invalid states

The virtual consumer always renders 32 pixel elements. Before a valid bundle is
loaded, when no effect timelines are available, or when the selected timeline
has no frame, every pixel is dark and the effect selector is disabled.

Bundle normalization accepts only effect names with frame collections. If a
previously selected effect does not exist in a newly loaded bundle, selection
falls back to the first available effect. Pixel channels are clamped to byte
range before being applied as CSS colors. Existing visible review and audio
errors remain authoritative; a missing visualization does not interrupt audio
review of otherwise valid bundle data.

The matrix keeps `role="img"` and exposes an accessible label containing the
selected effect and frame time. Individual pixels retain numbered RGB labels so
the generated colors remain inspectable without sight.

## File boundaries

- `tools/sound_review.py` owns physical-GRB to logical-portrait-RGB conversion,
  full-frame serialization, and effects-layout metadata.
- `tests/test_sound_review.py` verifies exact conversion, orientation, frame
  dimensions, and deterministic effect output.
- `web/review-mode.mjs` owns small pure helpers for available effect names and
  selected-effect frame lookup so browser behavior can be tested without a DOM.
- `web/test/review-mode.test.mjs` verifies selection, fallback, node-`0` lookup,
  and malformed/missing-frame behavior.
- `web/review-page.js` owns selector state, DOM rendering, and synchronization
  with the canonical playhead.
- `web/review.html` owns the renamed heading, left-rail structure, responsive
  layout, and 4×8 matrix styling.

No firmware renderer, effect algorithm, radio protocol, device configuration,
or public effects replay behavior changes.

## Testing and acceptance

Implementation follows test-first development. Focused Python tests first prove
that a known 32-pixel physical GRB frame becomes the expected row-major portrait
RGB frame and that every generated effect frame contains exactly 32 pixels.
Focused JavaScript tests first prove effect discovery, preserved selection,
fallback selection, and node-`0` frame lookup.

Browser coverage verifies that the page says “Sound Analysis,” the selector
contains exactly the five sound effects, choosing an effect updates the full
matrix without moving the playhead, and desktop/mobile layouts retain all 32
pixels. Existing review-library and authentication tests continue to cover
recording delivery.

The change is complete when the focused tests, web unit tests, browser tests,
web build, and project-wide `make check` pass; generated review artifacts report
a 4×8, 32-pixel portrait layout; and manual inspection confirms the selected
effect stays synchronized while playing and scrubbing.

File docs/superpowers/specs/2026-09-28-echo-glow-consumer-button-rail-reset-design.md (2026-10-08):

# Echo Glow consumer button rail and pinhole reset

## Status

Approved design. This work becomes consumer mechanical revision 3 and starts
from the saved Echo Glow consumer v2 design. Revision 2 remains unchanged.

## Scope

The consumer enclosure keeps its standard removable Feather header stack,
opposite-facing TFT and NeoPixel displays, centered cylindrical battery handle,
plain covers, and optional diffuser. This revision changes only the front-side
button installation aids and reset access.

## Button configuration

The existing three-button positions are retained at x = 7.62 mm and y =
4.445, 11.430, and 18.415 mm for D0, D1, and D2. Two new printable carriers
are added:

- `button-rail-flat.stl` uses the existing flat main-button geometry.
- `button-rail-domed.stl` uses the existing domed main-button geometry.

Each carrier contains only the three main buttons. A single vertical rail follows
their centerline at x = 7.62 mm. The rail is 0.4 mm wide and 0.2 mm thick,
so it prints as a one-layer temporary connection between adjacent button
brims. There is no TFT-surrounding frame, pull tab, reset branch, or permanent
connection. After inserting the three buttons together, the two short rail
segments are cut and the ends are trimmed flush.

The revision bundle also carries forward the five existing producer button
assets: separate flat plungers, separate domed plungers, the flush reset
plunger, and the two legacy four-button carriers. Those remain available for
reproducing earlier assemblies and are labelled legacy; the new rail carriers
are the preferred consumer configuration.

## Reset access

The reset plunger is removed from the preferred consumer assembly. At the
existing Feather reset-switch center, x = 44.45 mm and y = 11.43 mm, the front
housing has a straight 1.5 mm through-hole. The surrounding outside face stays
flush, with no chamfer and no printed insert. A paperclip or approximately
1 mm probe can press the board's own reset switch through the opening.

The legacy `reset-plunger-flush.stl` remains in the bundle for compatibility
with earlier covers. It is not included in the new rail-carrier installation
sequence.

## Deliverables

Create and save `Echo Glow consumer v3` in the `Echo Glow` Fusion project,
leaving v2 unchanged. Export the revised front housing, unchanged rear cover
and diffuser, both rail carriers, all carried-forward button assets, the native
F3D archive, previews, assembly notes, parts list, and verification records.
Striped covers remain deferred.

## Verification

The checks must establish:

1. the pinhole is 1.5 mm nominal and aligned with the Feather reset switch;
2. both rail carriers contain three intended buttons, one connected solid, and
   no positive-volume interference with the front cover or board reference;
3. all exported STLs are closed, consistently wound, nondegenerate, and the
   rail is a connected one-layer-thick temporary bridge;
4. the Fusion archive is complete and saved, and the bundle manifest hashes
   every release file; and
5. the documentation clearly distinguishes the preferred rail/pinhole assembly
   from the carried-forward legacy button options.

Physical print fit, probe feel, breakaway behavior, header stack height, and
reset-switch alignment remain first-print checks and must not be represented as
CAD verification results.

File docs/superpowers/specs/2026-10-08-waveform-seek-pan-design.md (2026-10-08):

# Waveform Seek and Pan Design

## Context

The sound-review page already keeps playback, the position slider, feature
values, detector events, human labels, and the virtual consumer synchronized
through `setTime()`. Zoom widens the timeline track inside a horizontally
scrollable waveform viewport, but the waveform itself does not currently
accept direct seek or drag gestures.

During review of `high-yell-01.wav`, direct interaction was needed to locate a
hard-to-place yell. The human-reviewed drone interval is 1020–6950 ms. The
yell remains unlabeled, and transient detections will not be promoted to human
labels for this take.

## User-visible behavior

- A primary-button click or tap on empty waveform space seeks to the timestamp
  under the pointer.
- If audio is playing, it continues from the new timestamp. If audio is paused,
  it remains paused.
- Pointer movement of five CSS pixels or less remains a click. Movement beyond
  five pixels becomes a pan gesture and must not seek when released.
- A pan changes the waveform viewport's horizontal scroll position without
  changing the playhead.
- Panning clamps naturally to the scrollable bounds. At 1× zoom there is no
  horizontal overflow, so a pan has no visible effect.
- Detector-event and human-label buttons retain their existing click behavior
  and do not start a waveform seek or pan gesture.
- Mouse, pen, and single-touch input share the same pointer-event behavior.
  Vertical page scrolling remains available on touch devices.
- The waveform shows `grab` and `grabbing` cursors to disclose the interaction.
- The existing position slider remains the keyboard-accessible seek control.

## Implementation design

`web/review-page.js` will own a small pointer gesture state containing the
active pointer ID, initial client X coordinate, initial viewport scroll offset,
and whether the drag threshold has been crossed.

On `pointerdown` over empty waveform space, the viewport captures the pointer
and initializes gesture state. On `pointermove`, crossing the threshold changes
the gesture to panning and updates `waveform.scrollLeft` from the original
scroll offset and pointer delta. On `pointerup`, a non-drag gesture converts the
pointer's viewport coordinate plus `scrollLeft` into a track-relative fraction,
clamps it to the track, and calls the existing `setTime()` function. A drag only
ends pointer capture. `pointercancel` and lost pointer capture clear the state
without seeking.

The time conversion will use the rendered timeline track rectangle rather than
assuming a particular zoom level. This keeps seeking correct at every supported
zoom and after responsive layout changes. Seeking continues to flow through
`setTime()`, preserving the existing synchronization and audio behavior.

`web/review.html` will add only the focused cursor and `touch-action` styling
needed for the interaction. No new controls or review-bundle fields are needed.

## Error and edge handling

- Ignore non-primary mouse buttons and additional concurrent pointers.
- Ignore gesture starts from detector-event and human-label buttons.
- Clamp computed timestamps through the existing `setTime()` path.
- Clear gesture state on pointer cancellation or lost capture so an interrupted
  drag cannot cause a later accidental seek.
- Do not alter playback state while seeking or panning.

## Verification

Playwright coverage will verify:

- clicking the waveform seeks to the corresponding timestamp;
- seeking while playing does not pause playback;
- dragging a zoomed waveform changes its horizontal scroll position without
  changing the playhead;
- movement within the threshold still seeks, while movement beyond it pans;
- panning at 1× remains bounded;
- event and label marker clicks preserve their existing behavior; and
- the page remains within its responsive horizontal layout bounds.

The focused browser suite will run on desktop Chromium, mobile Chromium, and
mobile WebKit, followed by the repository's full `make check` and web tests.

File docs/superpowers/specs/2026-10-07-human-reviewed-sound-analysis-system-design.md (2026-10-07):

# Human-Reviewed Sound Analysis System Design

Date: 2026-10-07  
Issue: NIC-8  
Status: Approved design for the first thin slice

## Goal

Build a deterministic, reviewable vertical slice for one 10-second recording from the Mac microphone: a sustained didgeridoo drone with one yell near the middle. The slice must preserve the raw WAV, keep human labels authoritative, reuse the producer’s existing FFT/feature/effect code, compare detected events with the reviewed labels, and expose one synchronized browser review view.

This is the first fixture and validation loop for NIC-8. It is not the complete golden corpus, annotation editor, CBOR replay format, or hardware replay implementation.

## Design decisions

The capture path uses the already-installed `ffmpeg` CoreAudio input on macOS. Capture is raw: no normalization, filtering, resampling after capture, or other signal processing is allowed. The capture command writes a temporary file, validates the result as mono, 16-bit signed PCM at 16 kHz and approximately 10 seconds, then atomically renames it to the fixture path.

The committed fixture is an explicit exception to the repository’s general rule against committing recordings, authorized by the NIC-8 request. Only this short review fixture is committed in this slice; the future corpus remains subject to its own storage decision.

The offline runner reuses `audio_spectrum.Spectrum`, `audio_features.Analyzer`, `config.Config`, and `animation.CulvertAnimation`. It does not maintain a separate desktop implementation of FFT, normalization, smoothing, or visual rendering. A new pure `audio_events.py` module provides semantic event conversion that can later be imported by the CircuitPython producer.

The initial semantic output includes `drone_start`, `drone_stop`, `yell`, and `transient`. Existing `Analyzer` edge flags are the source for yell and transient events. Drone events use configurable hysteresis and minimum-duration rules over the existing normalized drone envelope. Growl, beat, and the richer future label vocabulary are schema-compatible but not required for this fixture.

Derived artifacts use JSON first so a human can inspect and diff them. CBOR export is intentionally deferred until the schema and replay contract are stable.

## Capture and review flow

1. List or select a macOS CoreAudio input.
2. Print a cue for a two-second quiet calibration section, followed by a sustained drone, one yell centered near five seconds, and drone through the ten-second end.
3. Record directly to a temporary WAV with `ffmpeg`.
4. Validate sample rate, channel count, sample width, frame count, and duration. Reject invalid or short captures without replacing an existing fixture.
5. Store the validated source at `tests/fixtures/audio/drone-yell-10s.wav` and write capture metadata separately.
6. Generate an initial label file with the known drone range and review the waveform to place the yell range precisely.
7. Run offline analysis against the WAV and labels.
8. Generate feature, event, comparison, effect, and run artifacts under ignored `.artifacts/sound-review/`.
9. Open the generated review page and verify the shared playhead, human labels, detected overlays, feature tracks, and LED output.
10. Commit the WAV, reviewed labels, source changes, tests, and documentation. Do not commit derived `.artifacts` output.

The human review step is mandatory. The detector may suggest a yell time, but it cannot modify or replace the label file.

## Components and file boundaries

### Capture

`tools/record_fixture.py` owns CoreAudio device discovery, the countdown/cue, `ffmpeg` invocation, temporary-file handling, and WAV header validation. It has no analysis logic.

### Semantic event layer

`audio_events.py` owns a small stateful detector with explicit configuration:

- drone on/off thresholds;
- minimum drone-on and drone-off durations;
- event cooldowns where applicable;
- timestamp and confidence construction.

The detector consumes normalized `AudioFeatures` frames and returns immutable event dictionaries. It must run on CPython and CircuitPython-compatible Python without dependencies beyond the standard language subset already used by the firmware.

### Offline runner

`tools/sound_review.py` owns WAV reading, contiguous PCM hops, analysis timestamps, semantic event collection, label parsing, matching metrics, feature serialization, effect simulation, and review-bundle generation.

Each complete 1024-sample hop is passed to `Spectrum.push`. A feature timestamp is the end of the hop in milliseconds, matching the live producer’s post-capture processing point. The first incomplete FFT window is withheld exactly as it is on-device. `Analyzer.update` receives the configured hop duration.

The runner renders the existing `CulvertAnimation` at a deterministic review frame rate. The core renderer continues to use the configured 32-pixel installation model; the review artifact exposes eight representative RGB pixels by grouping the 32-pixel output into eight equal spatial groups. At least three virtual node distances are rendered, including the producer midpoint and two opposing culvert positions. The artistic wave speed comes from `Config`; physical sound speed is not used.

### Browser review

`web/review.html` provides the static structure and `web/review-page.js` owns loading and interaction. The generated review bundle provides the audio URL/data, downsampled waveform, human labels, features, detected events, comparison metrics, and eight-pixel frames for each virtual node.

The browser has one canonical playhead in milliseconds. Audio playback position, waveform cursor, every track cursor, event emphasis, feature marker, and LED frame selection are derived from that value. Scrubbing updates all views. The first slice supports play/pause, scrubbing, zoom, and replay around a selected label; label editing is deferred until the fixture review flow is proven.

## Artifact schemas

The authoritative label file is `tests/fixtures/audio/drone-yell-10s.labels.json`:

```json
{
  "audio_file": "drone-yell-10s.wav",
  "sample_rate_hz": 16000,
  "labels": [
    {"type": "drone", "start_ms": 2000, "end_ms": 10000},
    {"type": "yell", "start_ms": 4700, "end_ms": 5400}
  ]
}
```

The actual yell timestamps are set by human waveform review after capture. Every label has a known type and either a range (`drone`, `yell`) or a point (`beat`, `transient`); this first fixture uses only the two range types.

The feature artifact contains ordered frames with `time_ms`, `calibrating`, `volume`, `drone`, `growl`, `vocal`, `transient_strength`, `low_energy`, `mid_energy`, `high_energy`, `spectrum`, and `active` fields. Values intended for display or comparison are normalized to `0.0..1.0`; raw RMS and dominant frequency are retained in explicitly named fields.

The event artifact contains ordered records with `type`, `time_ms`, `confidence`, and optional `end_ms`. `drone_start` and `drone_stop` form an interval; `yell` and `transient` are point events.

The effects artifact contains a fixed frame rate, node distances, eight RGB pixels per node per frame, and the source feature timestamp used for each frame. RGB bytes use the same GRB-to-logical conversion as the renderer output after grouping; the schema names the channel order explicitly.

The run manifest contains:

- source WAV relative path and SHA-256;
- label file SHA-256;
- sample rate, FFT size, hop size, Hann-window declaration, and analysis frame rate;
- complete detector thresholds and timing parameters;
- effect-engine version/configuration and virtual node distances;
- source-module hashes and git commit when available;
- a fixed random seed field, set to `0` for this deterministic slice.

No generated artifact is allowed to overwrite the label file.

## Comparison rules

Point/range event matching is one-to-one and deterministic: sort both sides by timestamp, match the earliest unmatched detected event to the earliest unmatched human label of the same type when the detection lies inside the label expanded by the configured tolerance, then continue. The default tolerance is 250 ms. For a range label, onset timing error is detected time minus label start; a detection inside the range is a true positive even if its onset is later than the label start.

The report includes true positives, false positives, false negatives, precision, recall, F1, signed timing error, absolute timing error, and unmatched records for `yell` and `transient`.

Drone comparison pairs detected start/stop events with the human drone range and reports start error, stop error, interval intersection-over-union, false-active seconds, and false-inactive seconds. Silence before calibration and any post-drone tail are included in the false-event accounting.

## Error handling

- Missing `ffmpeg`, unavailable CoreAudio input, nonzero recorder exit, malformed WAV, wrong channel count, wrong sample width, wrong sample rate, or duration outside the configured tolerance produces a clear failure and preserves the previous fixture.
- Invalid labels—unknown type, non-integer timestamp, negative time, end before start, out-of-bounds range, duplicate incompatible file metadata, or sample-rate mismatch—fail before analysis.
- Non-monotonic frames, incomplete hops, non-finite values, and invalid detector output fail the run and do not produce a success manifest.
- The browser displays a visible status/error message when any bundle or audio resource cannot be loaded; it does not silently show empty tracks.

## Testing strategy

Host unit tests use the existing `unittest` suite and generated short PCM arrays for algorithm-level behavior. The committed WAV is used by an integration test that checks header validation, label loading, analysis completion, event ordering, and repeatability.

Required tests include:

- WAV reader rejects non-16-kHz, non-mono, non-16-bit, truncated, and non-integral-hop input;
- runner timestamps are monotonic and match hop duration;
- drone detector starts/stops once with hysteresis and does not chatter around thresholds;
- yell/transient conversion preserves one-frame edge events and confidence;
- comparison metrics match known hand-built labels with exact TP/FP/FN and timing values;
- two complete runs over the same WAV/config produce byte-identical features, events, effects, and normalized run metadata;
- effect simulation produces eight RGB pixels for every configured node and changes predictably when an event is inserted;
- browser review keeps the waveform cursor, feature cursor, event highlight, and LED frame on the same timestamp, and reports missing asset errors.

The normal project `make check` remains the primary host verification command. A focused review command runs the fixture analysis and writes ignored artifacts for manual inspection.

## Acceptance criteria for this slice

The slice is complete when a developer can run the documented capture or fixture-analysis command, open the generated review page, hear the committed ten-second WAV, see the waveform and human labels, see detected overlays and disagreement metrics, scrub or replay the yell region, and see synchronized eight-pixel effect output for multiple virtual nodes. Re-running the command with the same source and configuration must produce identical derived content. The labels must remain unchanged by every automated step.

The fixture is evidence that the plumbing is deterministic and reviewable. It is not evidence of general didgeridoo classification accuracy, a complete golden corpus, RF replay equivalence, or hardware validation.

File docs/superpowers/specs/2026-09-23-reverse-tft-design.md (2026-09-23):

# Reverse TFT board support and device dashboard

Date: September 23, 2026

## Status and decisions

The user selected **layout A, performance first**, then approved the revision
with physical buttons and their on-screen labels down the **left edge**. That
screen direction is settled. This document specifies the remaining hardware,
setup, radio, update and power behavior for review before implementation.

Use one firmware application for producers and consumers on all supported
boards. Screen support is optional; existing boards continue without a TFT.
The proposed role policy is a guided, one-time microphone check plus explicit
confirmation and a saved role. Automatic role inference on every boot is not
part of this version.

The reviewed browser mockup is local design material, not firmware or measured
telemetry. It is saved under
`.superpowers/brainstorm/94011-1790194594/content/reverse-tft-layouts-v3.html`.
Its radio rates, counts and battery values are simulated.

## 1. Hardware profiles

Add `adafruit_feather_esp32s3_reverse_tft`, keeping the original FeatherS2 and
Feather ESP32 V2 profiles. Use CircuitPython 10.3.1; verify identity and required
modules on hardware before deployment. The connected USB device advertises
Reverse TFT, but its installed firmware and filesystem have not been verified.

Centralize pins and capabilities in a USB-base `hardware.py`, preloaded by the
bootstrap before application import paths are isolated. Base and app must use
the same profile. Host deployment tools may read the pure profile definitions
without importing CircuitPython hardware modules.

| Function | Reverse TFT | Original FeatherS2 | ESP32 V2 |
| --- | --- | --- | --- |
| Wing data, factory jumper | D6 / GPIO6 | IO38 | D32 / GPIO32 |
| I2S BCLK | Proposed D5 / GPIO5 | IO5 | Unsupported producer |
| I2S LRCLK / WS | Proposed D9 / GPIO9 | IO6 | Unsupported producer |
| I2S data input | Proposed D10 / GPIO10 | IO9 | Unsupported producer |
| Display | Built-in `board.DISPLAY`, 240×135 | None | None |
| Battery sensing | MAX17048 over board I2C | Unsupported | ADC1 GPIO35 divider |

New-board microphone wiring is a proposal for an ICS43434: SEL to GND,
VDD to main 3.3V, common GND. Verify actual wiring before capture. Do not reuse
the old GPIO6 microphone clock: it conflicts with this board's wing data.
Keep TFT SPI, GPIO7 TFT/I2C power, GPIO45 backlight, I2C GPIO3/4, and buttons
GPIO0/1/2 reserved. Do not assume FeatherS2's external IO43 button exists here.
Reject conflicting or unsupported pin overrides before claiming any pins.

Use the board's existing display initialization. Read the MAX17048 with bounded
I2C operations and the built-in modules; avoid a new unversioned `/lib`
dependency. Probe only its documented address, 0x36. Unknown sensor revisions,
absent devices or failed reads produce unavailable status, not invented
voltage/percentage. Report voltage through the existing battery report shape;
show the sensor's estimated percentage locally on the TFT. Do not derive a
percentage from the voltage scale used by the Wing's Battery effect.

## 2. One app, explicit saved identity

Separate board identity (detected hardware), role (saved configuration), and
microphone health (runtime observation). A failed microphone must not silently
turn a producer into a consumer, and random input noise must not elect a
producer.

For new, unprovisioned Reverse TFT nodes, show a first-run setup page:

1. Choose Consumer, or Test microphone for Producer.
2. The mic test checks capture completion, non-flat samples, clipping and level
   variation over a bounded ten-second quiet/sound trial. Display a live meter
   and explain flat, clipped or failed capture. Nonzero RMS alone is insufficient.
3. The user confirms Producer after seeing the meter respond, or selects
   Consumer. No automatic promotion based solely on the signal.
4. Save the chosen role and group. An explicit host profile may set the role
   instead. Existing `node_config.py` profiles continue to take precedence;
   existing nodes never enter first-run setup after an update.

For a newly provisioned Reverse TFT without an explicit profile, deployment
must leave the role unconfigured rather than copy the repository's default
consumer override. Resolve setup before constructing the audio configuration
or attempting authenticated OTA. Add `make configure-node` for host-assisted
role/source selection and verified writes while USB owns the filesystem.

Store user selections as validated data, not generated executable Python, in
`/node_state.json`. A base `node_state.py` merges defaults, saved data and
explicit node overrides consistently for the bootstrap and application. Use
bounded sizes, temporary writes, readback and atomic replacement. Do not write
when the USB host owns the filesystem; offer host-assisted setup instead.
Persist on confirmation only, never on each sample or boot.

OTA enrollment follows role selection. Once credentials are provisioned, role
changes require the host enrollment/configuration workflow so the device role
and cloud record cannot disagree. Re-running a microphone health test does not
change enrollment. Setup must never stall an OTA health trial.

Consumers retain an explicit producer MAC and group. Host setup uses the
selected producer's real MAC when provisioning new consumers; do not keep the
old FeatherS2 MAC as an invisible default for a new installation. Automatic
producer discovery/election is outside this increment. Legacy configured
consumers must have their saved source changed before following a new producer.

## 3. TFT layout and behavior

Use the approved landscape 240×135 canvas. Reserve approximately 45 pixels on
the left for button labels; align labels to the physical buttons in the chosen
orientation. Verify the actual top-to-bottom ordering during board bring-up.
The content region keeps the effect name and level meter dominant. Provide
rotation as a profile setting independent of the NeoPixel matrix orientation.

| Area | Producer | Consumer |
| --- | --- | --- |
| Header | PRODUCER, local battery | CONSUMER, local battery |
| Main title | Effect number and name | Received effect number and name |
| Meter | DC-removed microphone RMS in dBFS, clipping flag | Received normalized audio level in percent |
| Lower row | Recently seen consumers, transmit rate | LIVE/LOST, receive rate or age of last valid packet |
| Footer | Channel/group and app version | Channel/group and app version |

Do not label consumer normalized volume as dBFS: the existing feature packet
does not carry raw microphone RMS. Quiet, clipping, calibration, mic fault and
lost link need distinct text states; color alone is insufficient.

D0 opens a diagnostics page with counters: submitted transmits, native send
success/failure, skipped sends, valid receives, rejected packets, packet age,
source MAC and audio timing overruns as applicable. A radio send success does
not prove a consumer received or rendered a frame. Use fixed-size text fields
and rate windows; handle counter wrap and reboot without negative rates.

Implement an optional `dashboard.py` with a pure snapshot/view-model layer and
a lazy CircuitPython display backend. Reuse display objects and built-in font
resources. Start with manual refresh at 5 Hz, dim configurable backlight and
no full-screen decorative animation. Audio/radio processing has priority;
skip a display refresh instead of queueing old updates. Dashboard failure logs
a bounded warning and leaves audio/wing operation running. No display imports
or allocations on boards without a TFT.

Show boot/update state on the TFT as bounded phase text, while retaining the
existing dim cyan wing indicator. Network calls can pause visible updates;
do not display a fabricated percentage or leave the backlight bright by default.
The small boot screen belongs to the USB base hardware helper; never import an
app-slot dashboard during maintenance and risk caching a mixed app version.

## 4. Buttons and power

| Button | Producer | Consumer |
| --- | --- | --- |
| D0, active LOW | Switch dashboard page | Switch dashboard page |
| D1, active HIGH | Short release advances shared effect | No group control; label FOLLOW |
| D2, active HIGH | Three-second hold requests group sleep | Three-second hold requests local sleep |

Preserve D0's ROM-loader and boot-time USB maintenance functions. Do not apply
the old active-low-only button handler to D1/D2. Debounce each input separately.
D1 long holds must not sleep the device. Existing boards retain their current
short/long controls and reset-only wake behavior.

For Reverse TFT, D2 is also the proposed local wake input. Show the hold
countdown, start the existing three-second red fade after the threshold and
broadcast producer sleep during the fade. After the fade, keep output black
and wait for D2 to be stably released before arming a level-triggered wake.
A held or stuck button must not produce an immediate wake/re-sleep loop; show
Release D2 while waiting. Ignore the waking press until a stable release.
A fresh press wakes this board through a normal restart; RESET also works.
Wake does not require a three-second hold. There is no timer wake.

Wake is local: an asleep consumer cannot receive an ESP-NOW wake command.
Each sleeping device requires its own button press or reset. Keep group sleep
best-effort; screen wording must not imply all nodes acknowledged shutdown.
Sleep remains disabled during candidate health trials.

Before sleep, blank the TFT and wing, stop display refresh, release the display
bus/backlight ownership, disable TFT/I2C and onboard NeoPixel power through the
verified profile, stop microphone/radio, and preserve the wing data LOW. Validate
the ordering against CircuitPython's board pin-reset hooks: GPIO7 defaults ON
and must not be re-enabled inadvertently during teardown. A pin alarm and held
power outputs must coexist. Test USB simulated sleep separately from actual
battery sleep. Do not claim measured current savings without measurement.

The separate FeatherWing VBAT/VUSB power rail remains powered. The deferred
intermittent sleep-light issue is not considered fixed by TFT power management.

## 5. Consumer presence over ESP-NOW

Keep the existing v3 audio feature and sleep packets unchanged. Add a separately
versioned presence message with its own magic, group, intended producer MAC,
producer session, consumer boot session/sequence and last accepted audio
sequence. Validate length and fields before use. Count the actual sender MAC,
not a MAC claimed in the payload.

Consumers broadcast one presence message about every 3 seconds with randomized
initial delay and ±0.5-second interval jitter, only after receiving a valid,
recent frame from their configured producer. Broadcast replies avoid per-peer
registration limits for the first version. Producers listen with the existing
native `read_success` completion gate and an eight-packet drain bound.
Retain one outstanding send per device and never block audio waiting for a
presence transmission. Suspend presence during sleep transitions.

Maintain a bounded table of 32 sender MACs, with a configurable maximum and
10-second expiration. Validate intended producer, group and current producer
session; reject stale/duplicate presence sequences. Evict expired records
first, then the least recent, and show a capacity indicator if the table fills.
No fixed-size queue may grow with the number of incoming packets.

Label the number **SEEN/10s**, meaning recently acknowledged listeners. It is
not an exact inventory, a range guarantee, or proof LEDs are visibly working.
Older consumers still render v3 features but are uncounted until updated.
Old producers ignore presence; upgraded consumers still work with them.
Avoid counting unrelated control packets as lost audio sequences.

## 6. Deployment and release compatibility

Update `make` and host helpers to recognize all three exact board IDs, verify
required modules and use native USB/CIRCUITPY deployment for Reverse TFT.
Generalize the existing identity/UID/drive checks rather than treating every
new board as an ESP32 serial-only target. Preserve credentials, profiles,
recovery and slots; routine deployment never erases flash.

For new-board CircuitPython installation, inspect the existing bootloader and
firmware first. CircuitPython 10 requires a compatible TinyUF2 bootloader.
Back up existing contents and use board-specific official artifacts; firmware
installation and application deployment remain separate commands.

Target a new **USB base 1.1.0 / app 1.1.0**, with minimum base 1.1.0. Add
`hardware.py` and `node_state.py` to the base and preload them. Add
`dashboard.py` and `device_setup.py` to the app bundle, alongside the existing
ten modules. Base and cloud validation must support two explicit contracts:

- Legacy schema 1: exact historical ten app files and two-board list.
- Schema 2: exact new twelve app files and three-board list, with minimum base
  1.1.0. Keep app entry-point API 1 and audio protocol v3.

Do not replace the legacy contract with the new constants: doing so would
invalidate installed manifests and rollback slots. Select the exact permitted
file set by schema, reject mixed sets/unknown paths, and retain all digest,
size, sequence and compatibility checks. New Reverse TFT devices cannot run
legacy releases; they need their own compatible recovery bundle at provisioning.

Update Firebase release/report validation and enrollment tools before publishing
the new release. Existing bases must keep selecting compatible 1.0.x releases.
Upgraded old-board bases must still validate and boot installed 1.0.x slots,
then trial 1.1.0 with a valid rollback path. Provisioning must treat the new
native USB board like FeatherS2 for safe filesystem ownership.

## 7. Verification and rollout

Host checks cover profile conflicts, role persistence/precedence and corrupt
state; quiet/flat/clipped microphone-test handling; button polarity, debounce,
hold/release/wake suppression; display snapshots and refresh throttling;
presence validation, duplicates, expiry, capacity and mixed versions; and
legacy/new release contracts including rollback after base upgrade.

Run `make check`, relevant API/emulator/browser checks, and source readback on
each deployment. On the new board verify I2S support, pin assignments, TFT
orientation/button order, battery readings and dim backlight. Compare audio
timing with display disabled/enabled; report measured FPS, mean/max work,
64 ms budget misses and capture discontinuities. Reduce display rate if it
adds sustained overruns. Preserve existing limitations rather than claiming
lossless capture from a zero discontinuity counter.

Bring up a new-board consumer first, then a microphone producer on a second
new board. Validate old/new producer-consumer combinations and count only
upgraded acknowledging consumers. Run user-visible effect-change, unplug/rejoin,
mic quiet/sound, lost-link, Battery and local/group sleep tests. Test wake after
release with USB and battery power separately; confirm reset remains usable.
Keep the old working nodes available throughout migration.

Update README wiring, commands, role setup, display fields, presence semantics,
button controls and OTA upgrade instructions. Update AGENTS with verified new
hardware facts. Record measured hardware results and failures in operations.

## Sources

- [Reverse TFT pinouts](https://learn.adafruit.com/esp32-s3-reverse-tft-feather/pinouts)
- [Button polarities](https://learn.adafruit.com/esp32-s3-reverse-tft-feather/digital-input-multiple-buttons)
- [Battery and power management](https://learn.adafruit.com/esp32-s3-reverse-tft-feather/power-management)
- [CircuitPython 10.3.1 board pins](https://raw.githubusercontent.com/adafruit/circuitpython/10.3.1/ports/espressif/boards/adafruit_feather_esp32s3_reverse_tft/pins.c)
- [CircuitPython 10.3.1 display and power initialization](https://raw.githubusercontent.com/adafruit/circuitpython/10.3.1/ports/espressif/boards/adafruit_feather_esp32s3_reverse_tft/board.c)
- [CircuitPython pin alarms](https://docs.circuitpython.org/en/latest/shared-bindings/alarm/pin/index.html)

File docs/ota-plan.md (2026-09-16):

# OTA upgrades — proposal for review

Status: **approved for implementation**. September 15, 2026.
See [OTA operations](ota-operations.md) for implementation details and measured
validation. This document preserves the original proposal.

## Recommendation and scope

Use a small Firebase HTTPS REST API, a Firebase administration app, and GitHub
Releases as the source of application versions. Each device gets its own token
in `settings.toml`. At boot it tries the open **`openwireless.org`** network,
reports its actual installed versions, asks for the newest compatible stable
release, and installs it if needed. If the network or service is unavailable,
it runs its last working application. No captive portal or MQTT broker is
needed for this workflow.

Keep performance lighting on the existing offline ESP-NOW network. All nodes
update independently over Wi-Fi; the producer does not relay firmware or device
credentials over ESP-NOW. A node within radio range of the producer but outside
Wi-Fi coverage can keep showing lights, but cannot obtain cloud updates there.

Initial supported boards remain the microphone FeatherS2 and consumer Feather
ESP32 V2. Preserve mic GPIO 5/6/9, wing GPIO 38/32, BOOT effect selection, local
node role, orientation, calibration tuning, and brightness 0.15.

## What to reuse from gate_controller

Use its **implemented** [OTA operations](../../gate_controller/docs/ota-operations.md)
and [bench results](../../gate_controller/docs/ota-bench-validation.md), rather
than copying the older rename-based proposal:

- A USB-installed bootstrap and independent application/base version reports.
- Two application slots, a retained confirmed version, two checksummed journals,
  bounded downloads, SHA-256 verification, trial boots, watchdog and rollback.
- GitHub artifacts mirrored to immutable private Storage objects; devices use
  one authenticated HTTPS endpoint, with explicit trusted roots and hostname
  checks. Gate's bench tests needed explicit Google roots on CircuitPython.
- Per-device random tokens, server-side token hashes, disable/revoke support.
- Firebase Hosting, Google sign-in, server-checked admins, App Check for browser
  requests, deny-all direct Firestore client access, and audit records.

Adapt rather than directly copy its XIAO pins, MQTT health conditions, single
application file, credentials, Firebase project, or gate-specific output logic.
Create a **separate Digirdu Firebase project**; do not modify Drawbridge or share
its runtime credentials. Project ID/region will be selected before provisioning.
Its power-loss and recovery qualification is incomplete; repeat those tests on
both of our boards.

## Network phases: protect ESP-NOW during playing

ESP-NOW and an associated Wi-Fi station must use the access point's channel.
Our current lighting channel is 1; `openwireless.org` could be on another
channel. Arbitrary Wi-Fi scans/reconnects during playback would interrupt
reception. This follows [Espressif's coexistence guidance](https://docs.espressif.com/projects/esp-faq/en/latest/application-solution/esp-now.html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).

Proposed first version:

1. **Boot maintenance:** keep LEDs dim with a distinct update status indicator.
   Try only the configured SSID, with no password or setup access point.
   Use a short bounded scan/association attempt (target 8 seconds), 0–2 seconds
   of per-device jitter, and no endless reconnect loop.
2. **Check in:** send running app/base versions and the last saved update result;
   receive desired version, deployment sequence, pause state and manifest.
   Treat captive-portal redirects, TLS failures, malformed content and timeouts
   as unavailable internet. Never disable TLS validation on this open network.
3. **Update if required:** download to the inactive slot with limits, verify,
   journal a pending trial and reboot. Suggested initial bounds: 8 KiB manifest,
   256 KiB total application, 1 KiB chunks, 5-second socket timeout, 90-second
   overall maintenance deadline. Measure DNS/TLS blocking on both boards before
   promising that deadline; use watchdog recovery for a stuck startup. A failed
   maintenance watchdog boot skips networking once to reach the saved app.
4. **Enter lighting:** close sockets, disconnect Wi-Fi, stop scanning, release
   TLS buffers, explicitly restore the configured ESP-NOW channel and start
   audio/rendering. Restore the channel on every success and error exit.
5. **Trial confirmation:** run a new candidate for 30 seconds on ESP-NOW.
   Require imports, finite/bounded feature values, continuing render frames,
   no unhandled errors and role-appropriate subsystem initialization. Producer
   also requires working capture and completed calibration; consumer must keep
   rendering but need not hear a producer. Missing internet or a silent/absent
   producer is not evidence that consumer code is broken. Distinguish RF reception
   and measured audio activity from software health in the report.
6. After a successful trial, commit locally and make **one bounded post-update
   report attempt**: fade, pause lighting briefly, join Wi-Fi, report the actual
   confirmed version, then restore ESP-NOW. On failure persist the latest result
   for the next boot. This short extra interruption occurs only after an update;
   do not periodically reconnect during a show. Treat it as part of startup.

A normal boot reports before lighting starts. Internet-free boots cannot report;
show a timestamped last report, never infer that the device is online. A later
explicit maintenance command/button gesture could check without a power cycle.
Periodic online heartbeats or seamless concurrent Wi-Fi require a separately
reviewed channel-coordination design or a dedicated Wi-Fi/ESP-NOW gateway.

## Application layout and recovery

The app has multiple coupled Python modules, so overwriting root files one by
one is unsafe. Use **two complete module directories**, selected as a unit:

```text
/boot.py                 USB-managed filesystem ownership
/code.py                 USB-managed loader, watchdog, boot maintenance
/lib/ota_*.py            USB-managed updater, HTTP and journal support
/certs/...               USB-managed public TLS roots
/recovery/...            USB-installed complete known-working application
/ota/slot0/...           complete application bundle
/ota/slot1/...           complete application bundle
/ota/state0.json         alternating checksummed selection journals
/ota/state1.json
/node_config.py          per-node role/pins/tuning overrides, preserved
/settings.toml          per-device endpoint/credential, preserved
```

Release the audio, effects, renderer, config defaults, radio protocol/transport,
and main application together. Bootstrap pins a small application API for
startup, progress/health reporting and shutdown; per-node overrides are loaded
separately and validated by the selected app. Never silently reset a producer
to consumer or lose an orientation override during update.

On a fresh VM boot, import only the chosen slot's app modules plus explicit
base libraries. Do not fall back to modules from an older slot or root directory
when an import is missing. Prototype this module isolation on CircuitPython
before implementing cloud delivery. Do not hot-reload an arbitrary set of modules.

Download manifest-listed files individually through the authenticated endpoint;
no on-board ZIP extractor. Accept only fixed relative file names, reject traversal,
unexpected/duplicate files and unsupported sizes; verify every length/digest and
bundle digest before selecting a slot. The active slot and root recovery bundle
are never download destinations. Clean only the inactive slot after validating
space requirements; reject if there is insufficient space plus a reserve.

Write and sync a complete checksummed journal to the older journal generation.
Record a trial as started before importing it. A boot that finds an already-started,
unconfirmed trial rolls back; a loop hang triggers the hardware watchdog.
Confirm only after progress-based health checks, not merely a successful import.
A bad app must not repeatedly download on each boot: remember the rejected digest
and deployment sequence until a newer deployment or explicit retry is assigned.
Recovery is offline-capable and independent of Firebase. These application slots
are on one FAT filesystem, not isolated ESP flash partitions; whole-filesystem
corruption can still require USB repair.

### Filesystem ownership and initial USB install

Every board needs one USB bootstrap/enrollment deployment. CircuitPython must
own writes in OTA field mode; the USB host owns writes in maintenance mode.
Never enable concurrent host/device write protection bypasses. The ownership
choice belongs in `boot.py`, per [CircuitPython storage documentation](https://docs.circuitpython.org/en/stable/shared-bindings/storage/index.html).

FeatherS2 needs a **tested physical recovery route** that exposes writable
CIRCUITPY even when the selected app fails. Choose and verify a spare non-strapping
GPIO/jumper during the first hardware stage. Do not copy the XIAO's GPIO8/D9
assignment. BOOT/GPIO0 held during reset invokes ROM download mode, so it cannot
simply replace Gate's maintenance jumper. A delayed BOOT press after reset is an
alternative only if reliable in bench tests. Preserve the ordinary short BOOT
press for selecting lighting effects. Firmware recovery through ROM remains a
last resort, not the normal maintenance flow.

ESP32 V2 has serial USB rather than a CIRCUITPY drive. Test bootstrap bypass and
serial REPL repair there too. Extend `make deploy` to recognize maintenance
ownership, preserve settings/journals, explicitly select a repaired recovery app
when requested, and retain backups/readback/startup verification. Never erase
flash as a routine OTA recovery step.

OTA v1 updates application code only. CircuitPython, bootloader, loader, HTTP
client, certificates and base libraries remain separately versioned USB updates.
No cloud operation changes device credentials or saved node configuration.
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

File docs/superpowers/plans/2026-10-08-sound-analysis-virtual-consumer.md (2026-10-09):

# Sound Analysis Virtual Consumer Implementation Plan

> **For agentic workers:** REQUIRED SUB-SKILL: Use superpowers:subagent-driven-development (recommended) or superpowers:executing-plans to implement this plan task-by-task. Steps use checkbox (`- [ ]`) syntax for tracking.

**Goal:** Rename the review page to Sound Analysis and add a sticky, effect-selectable virtual consumer that displays the exact Python-rendered 4×8 FeatherWing frame.

**Architecture:** Keep `CulvertAnimation` as the only renderer. The offline Python pipeline converts each physical-order GRB frame into 32 logical portrait RGB pixels, while small pure JavaScript helpers select the available effect and node-`0` timeline for the DOM renderer.

**Tech Stack:** Python 3/unittest, browser ES modules/node:test, HTML/CSS, Playwright, esbuild

---
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

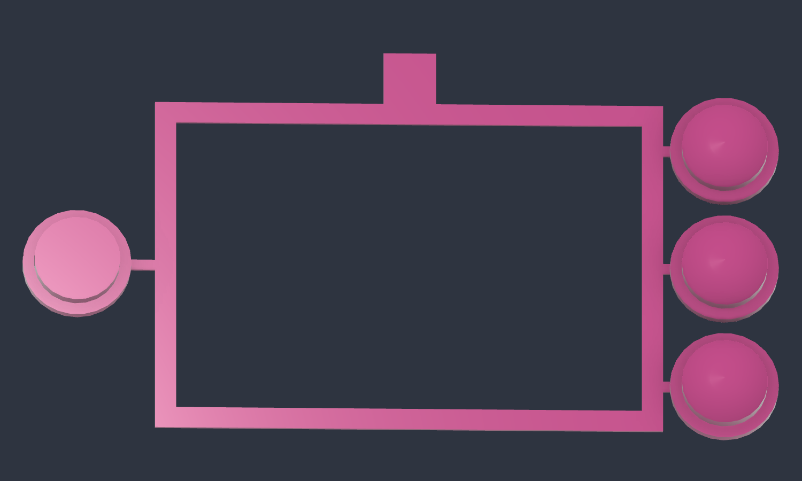
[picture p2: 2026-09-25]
hardware/producer/revision-11/button-carrier-domed.png

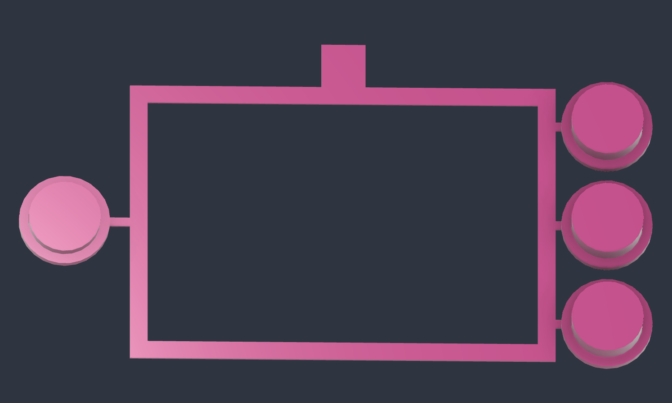
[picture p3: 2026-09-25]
hardware/producer/revision-11/button-carrier-flat.png

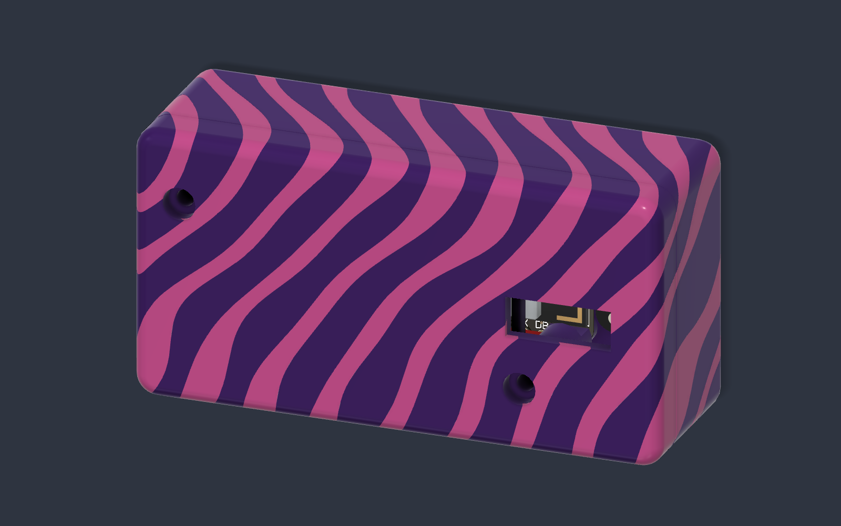
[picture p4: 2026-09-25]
hardware/producer/revision-11/patterned-rear.png

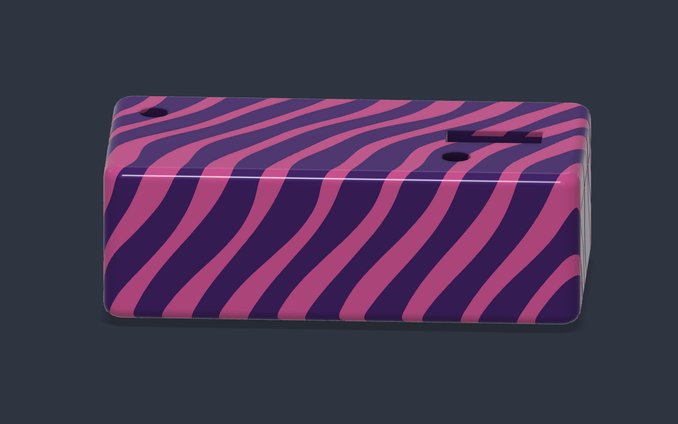
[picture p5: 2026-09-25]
hardware/producer/revision-11/patterned-side-seam.png

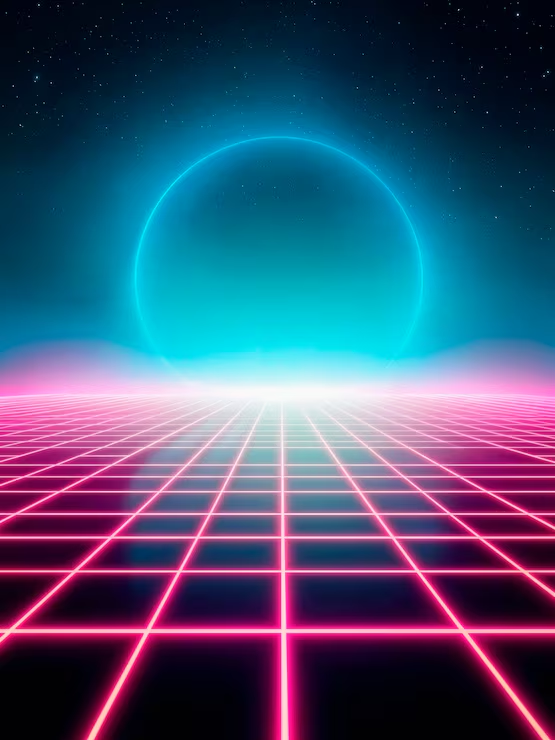
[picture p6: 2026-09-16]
web/assets/laser-horizon.png

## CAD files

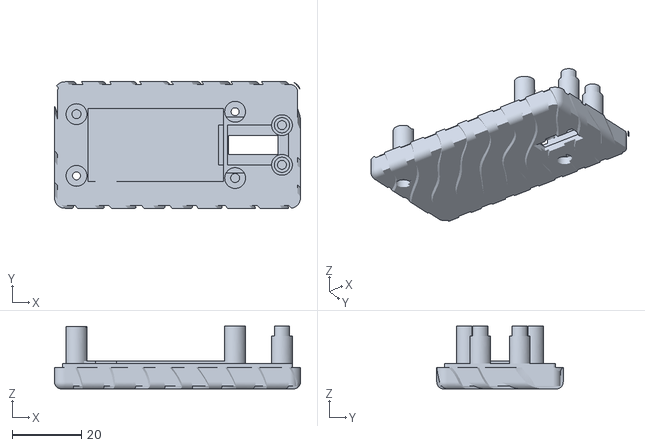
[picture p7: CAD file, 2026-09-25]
hardware/producer/revision-11/rear-purple.stl
70.9 x 36.5 x 18.1

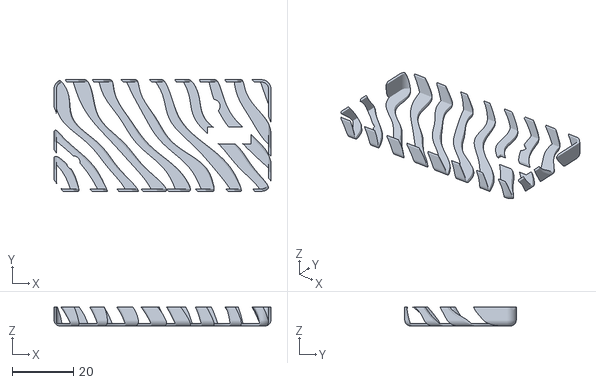
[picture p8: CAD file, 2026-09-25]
hardware/producer/revision-11/rear-pink.stl
70.9 x 36.5 x 6.20

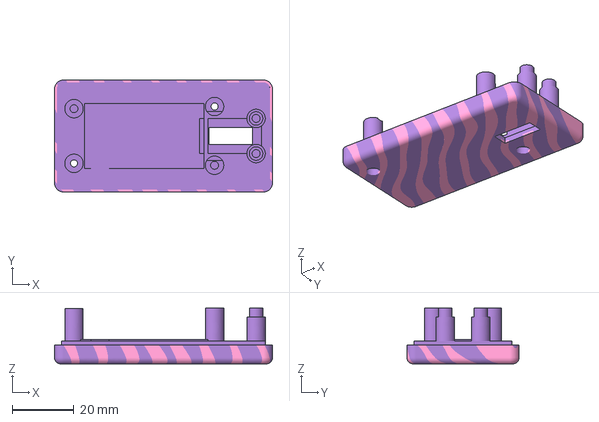
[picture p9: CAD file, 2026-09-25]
hardware/producer/revision-11/rear-patterned.3mf
70.9 x 36.5 x 18.1 mm

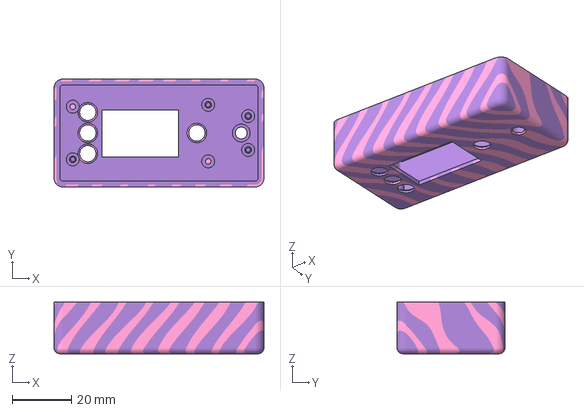
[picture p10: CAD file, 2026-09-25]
hardware/producer/revision-11/front-patterned.3mf
70.9 x 36.5 x 17.4 mm

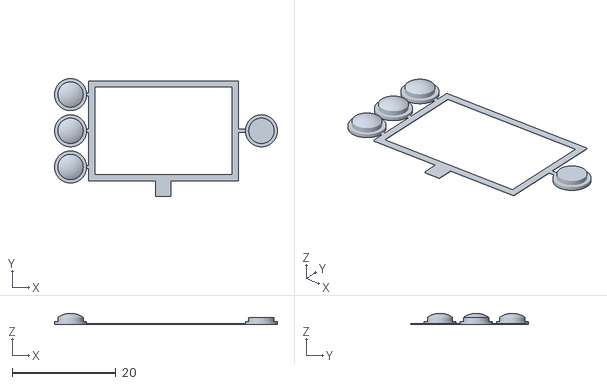
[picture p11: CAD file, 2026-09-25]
hardware/producer/revision-11/button-carrier-domed.stl
43.0 x 22.8 x 2.20

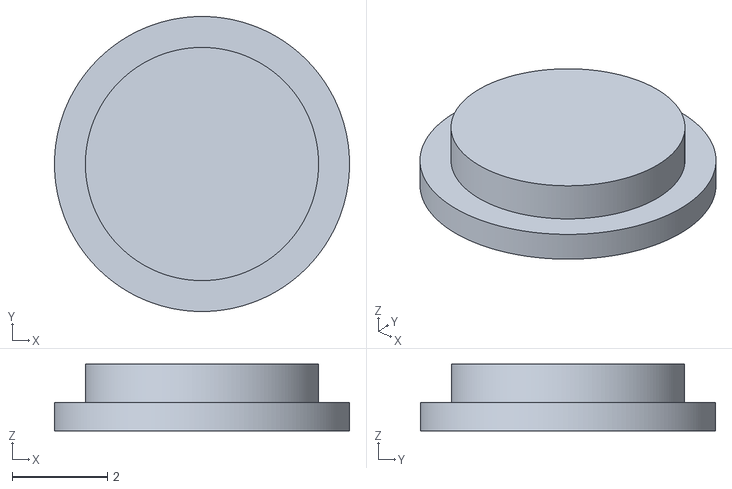
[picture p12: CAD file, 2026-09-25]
hardware/producer/revision-11/reset-plunger-flush.stl
6.20 x 6.20 x 1.40

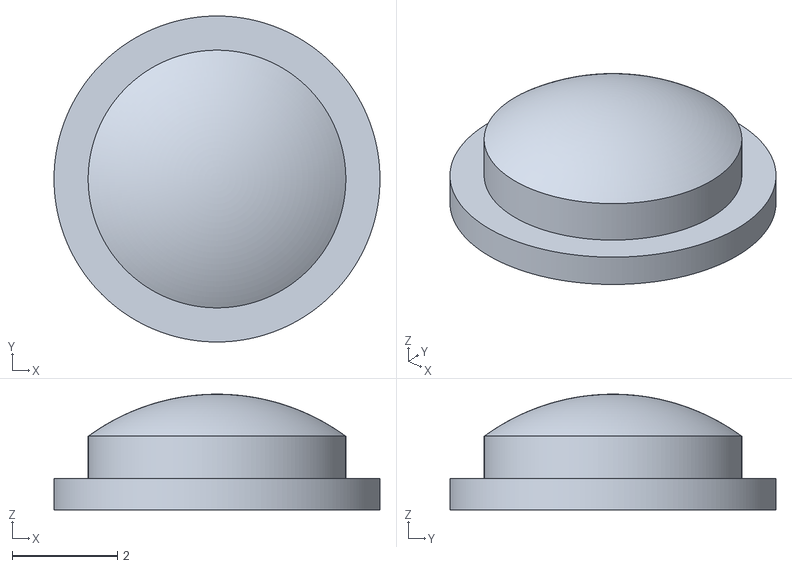
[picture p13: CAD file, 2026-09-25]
hardware/producer/revision-11/button-plunger-domed.stl
6.20 x 6.20 x 2.20

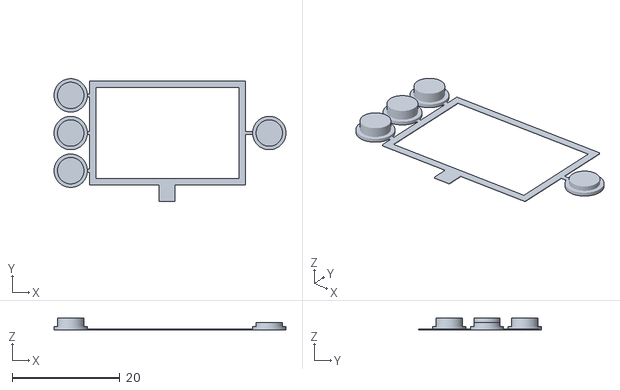
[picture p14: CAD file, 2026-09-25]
hardware/producer/revision-11/button-carrier-flat.stl
43.0 x 22.8 x 2.20

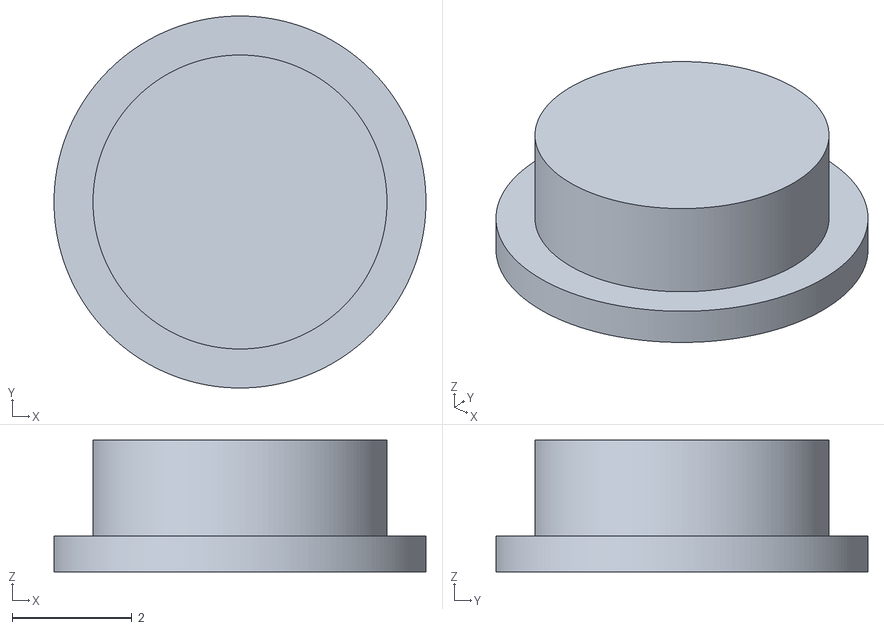
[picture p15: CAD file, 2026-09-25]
hardware/producer/revision-11/button-plunger-flat.stl
6.20 x 6.20 x 2.20

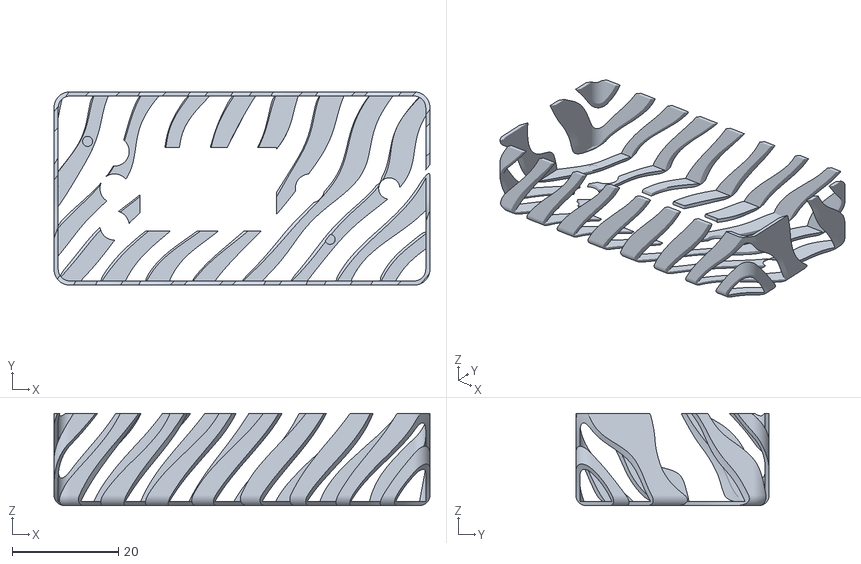
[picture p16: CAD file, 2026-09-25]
hardware/producer/revision-11/front-pink.stl
70.9 x 36.5 x 17.4

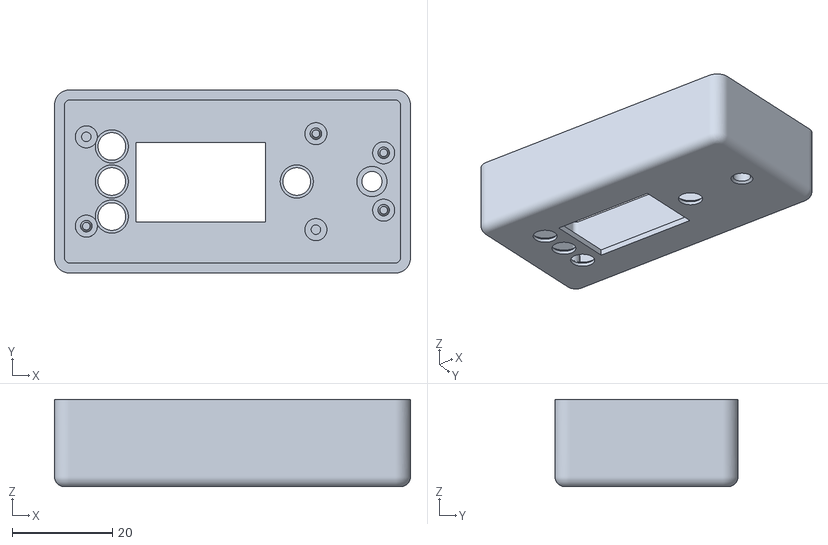
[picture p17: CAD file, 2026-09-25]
hardware/producer/revision-11/plain-front-housing.stl
70.9 x 36.5 x 17.4

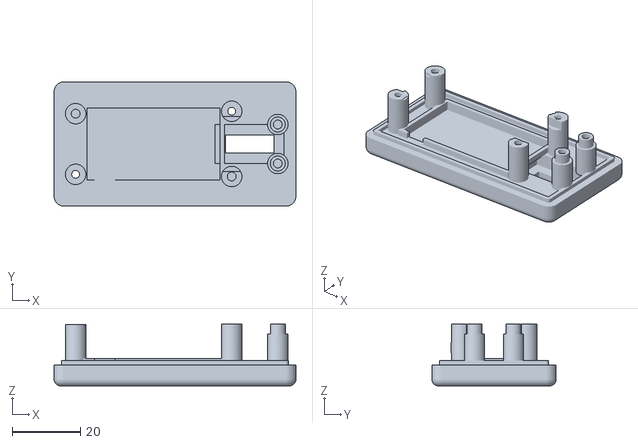
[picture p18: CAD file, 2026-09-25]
hardware/producer/revision-11/plain-rear-cover.stl
70.9 x 36.5 x 18.1

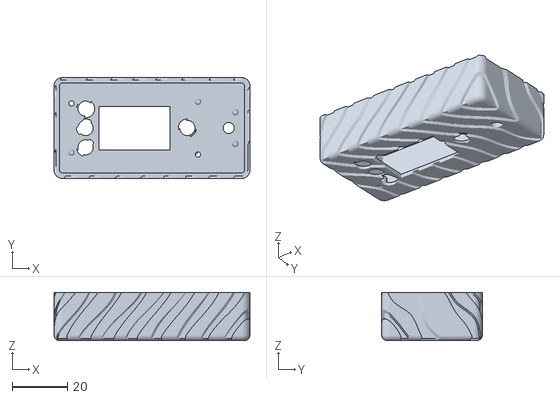
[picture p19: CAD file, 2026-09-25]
hardware/producer/revision-11/front-purple.stl
70.9 x 36.5 x 17.4

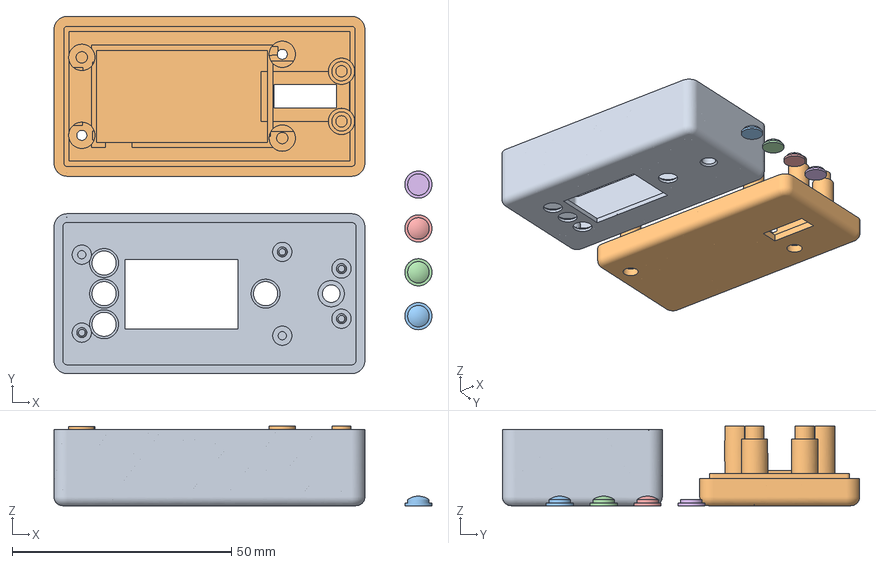
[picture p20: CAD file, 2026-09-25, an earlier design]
hardware/producer/revision-11/previous-bambu-project/DidgeLights-v10-H2D.3mf
86.2 x 81.5 x 18.1 mm
Front housing
Rear cover
Domed main button 1
Domed main button 2
Domed main button 3
Flush reset button

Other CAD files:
hardware/producer/revision-11/DidgeLights-enclosure-v11.f3d

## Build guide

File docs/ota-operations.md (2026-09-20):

# OTA application upgrades

The updater uses GitHub Releases, authenticated Firebase HTTPS, two complete
application slots and automatic trial rollback. Every device first needs a USB
bootstrap and its own token. The original design is in [ota-plan.md](ota-plan.md).
See the validation section below for what has actually been tested.

## Versions and files

`app_version.py` identifies the application (first OTA release 1.0.1);
`ota_manifest.py` identifies the USB-installed base, currently 1.0.1. CircuitPython remains pinned to 10.3.1.

- `code.py`, `boot.py`, `ota_*.py` and `certs/` are the USB-managed base.
- `lights_app.py` contains the previous audio/render/control loops. The other
  application modules remain modular source files at the repository root.
- USB deploy installs all ten application modules under `/recovery/`.
- `/ota/slot0/` and `/ota/slot1/` contain complete OTA applications. The loader
  imports only the selected directory plus base libraries. It cannot fill in a
  missing module from another application version.
- `/ota/state0.json` and `state1.json` alternate checksummed journal generations.
  An interrupted candidate does not overwrite the working slot or root recovery.
- `/node_config.py` retains the board's role and overrides. `/settings.toml`
  retains its credential. Neither is an OTA release asset.

Normal application work changes the application files. A change to boot,
recovery, HTTP, certificates, manifest compatibility or the loader needs a new
base version and deliberate USB deployment. Application OTA cannot replace the
base or CircuitPython itself. The API boundary is a convention for trusted
Python, not a sandbox against malicious release authors.

Base 1.0.1 resumes lighting immediately after an interrupted trial or corrupt
active slot, deferring the cloud report until a later normal boot. This avoids
reconnecting Wi-Fi during the first watchdog recovery boot. Base 1.0.0 boards
need `make deploy-base` over USB; application release 1.0.2 requires base 1.0.1.
App 1.0.2 retains the same audio, effects and ESP-NOW protocol as 1.0.1.

## Initial deployment and enrollment

```sh
make setup
make check
make deploy PORT=/dev/cu.usbserial-...  # Auto-detects supported hardware
make web-setup
make ota-enroll DEVICE_ID=<full-lowercase-cpu-uid> BOARD=adafruit_feather_esp32_v2 ROLE=consumer
make ota-provision DEVICE_ID=<uid> PORT=/dev/cu.usbserial-...
```

For the microphone board use `BOARD=unexpectedmaker_feathers2 ROLE=producer`.
Known full IDs are consumer `4133c5792f0a` and producer `c7fd1a30c4c2`.
The provisioner verifies board model and CPU UID, preserves unrelated TOML
settings, stores a local backup with owner-only permissions, and verifies the
new bytes. Enrollment stores a random token in ignored `.artifacts/ota/<id>.json`
and only its SHA-256 in Firestore. It refuses accidental re-enrollment/rotation.
Do not copy a token to a different board or commit populated settings/backups.

OTA is initially disabled. Enable it after bench validation:

```sh
make ota-provision DEVICE_ID=<uid> PORT=/dev/cu.usbserial-... OTA_ENABLE=1
```

Hard-reset to run `boot.py` and apply filesystem ownership. The normal update
SSID is `openwireless.org` with no password. No captive portal is started.
Tokens authenticate only their own device's reports and approved downloads.
They do not grant fleet administration. Physical access to the filesystem can
read them; there is no encrypted secret storage.

## Maintenance and USB repair

When OTA is enabled, a hard reset shows a dim blue wing for two seconds. During
that window, press the board's maintenance button:

| Board | Button | GPIO |
| --- | --- | --- |
| Unexpected Maker FeatherS2 | BOOT, pressed **after** releasing RESET | IO0 |
| Adafruit Feather ESP32 V2 | SW38 user button | `board.BUTTON`, GPIO38 |

GPIO0 on ESP32 V2 is the onboard NeoPixel, not the user button. Its GPIO38
button has an external pull-up; do not enable an unsupported internal pull-up.
On FeatherS2, holding BOOT through reset enters ROM download mode instead of
application maintenance. BOOT retains effect selection during normal playback.

Maintenance keeps the device filesystem read-only to CircuitPython and permits
USB-host writes on FeatherS2. The ESP32 V2 uses the serial REPL. Do not bypass
concurrent-write protection or try host writes to a field-owned CIRCUITPY drive.
`make deploy` preserves node configuration, settings and OTA slots/journals.
`make deploy-base` updates only the base and certificates, preserving the USB
recovery app too. Host tooling disables the watchdog after entering the REPL
so deliberate USB work is not interrupted by a field watchdog reset.
A normal USB deploy updates the recovery copy and base; it does not silently
replace a confirmed OTA selection. To repair/select the USB recovery application,
back up the journals, then remove both `/ota/state*.json` in maintenance mode.
This is a deliberate recovery operation, not part of routine deploy.

Field mode writes through CircuitPython. A selected trial is marked started
before import. Failure or a reset before confirmation reselects the previous
working copy. A watchdog catches a stuck application loop. The immediate recovery boot
skips networking so the working app can resume; its saved failure report is
sent on a later normal boot. After a failed
candidate, the same deployment sequence is not retried; assign a newer sequence
or release. There is always a USB recovery path, but FAT/filesystem corruption
can still require manual repair. Two directories are not independent flash banks.

## Boot behavior and reporting

The board makes one bounded Wi-Fi attempt (8-second association timeout, 0–2 s
jitter), then checks in with its actual app/base/interpreter versions and saved
update outcome. The HTTP client verifies certificates and hostname using the
public Google roots, rejects redirects/compression and malformed framing, and
bounds body sizes, socket waits and maintenance time. A watchdog reset during
networking skips networking once on the next boot. NVM bytes 0–4 are reserved
for the `DGO1` marker and this skip flag; credentials are never stored there.

The newest compatible stable release is selected unless the device is pinned,
paused or revoked. An unavailable network leaves the installed application
running. TLS buffers/sockets are released and the AP disconnected before the
existing ESP-NOW initialization restores channel 1 (or the node's configured
channel). Consumers update independently; the producer does not relay firmware.

A candidate must run for 30 seconds after calibration with advancing render
frames and bounded finite features. Producer initialization includes I2S; a
consumer need not hear a producer to be healthy. A successful trial confirms
locally, pauses for one bounded report attempt, then restarts into normal
lighting. Failed reporting is retained for a later boot. Ordinary playback
makes no periodic internet connections. The dashboard timestamp is last report,
not proof of current reachability, sound recognition or physical LED output.

## Release workflow

```sh
# Edit app_version.py, test, commit, and push first.
git tag firmware-v1.2.0
git push origin firmware-v1.2.0
make firmware-build VERSION=1.2.0
make firmware-release VERSION=1.2.0
```

The build requires a clean tree and a matching tag at HEAD. It emits individual
app files and `manifest.json`, plus `base-firmware.zip` and `base-manifest.json`
for USB maintenance. Artifacts exclude node configuration, credentials and
recordings. Existing local artifacts cannot be replaced with different bytes.

The GitHub `Verify and import firmware release` workflow runs on published
non-prerelease releases. It uses short-lived workload identity, verifies asset
hashes against the tagged source, mirrors files into create-only Storage objects,
and advances stable to the highest semantic version. There are no static cloud
keys in GitHub. `make firmware-import VERSION=...` provides the same import using
local gcloud credentials. Import failure leaves the prior stable target intact.

Devices select the highest compatible imported version; a newer release requiring
an unavailable USB base does not hide an older compatible application. Routine
releases must retain protocol compatibility across independently updating nodes.
A breaking ESP-NOW change needs staged consumer support before producer migration.
An intentional rollback uses a newer deployment sequence even with older app bytes.

## Firebase operations

Project: **digirdu-lights**, region **us-east1**. Dashboard:
https://digirdu-lights.firebaseapp.com. Runtime identity is
`digirdu-functions@digirdu-lights.iam.gserviceaccount.com`; release import uses
`digirdu-releases@digirdu-lights.iam.gserviceaccount.com`. They have scoped database
and private firmware bucket access. Functions have zero minimum instances and
three maximum instances; container build images expire after seven days.
Drawbridge's project and credentials are separate.

```sh
make web-setup
.venv/bin/python tools/cloud.py web-config
make admin-seed EMAIL=nick.stielau@gmail.com
make web-test
make web-build
make web-deploy
make ota-status
```

Google sign-in and App Check protect browser administration. Google provider
setup requires enabling it in the Firebase console with a support email/OAuth
client. Device endpoints use per-device tokens instead of App Check. Firestore
client rules deny all access; Functions return bounded, authorized views.

The dashboard shows reported app/base versions, desired version, board/role,
last report and update outcome. It supports pinning/rollback, follow-latest,
pause/resume, rename and token revocation. Revocation stops subsequent device
requests and requires deliberate re-enrollment/USB provisioning to restore.
Pausing affects future requests; a device that has already downloaded a verified
bundle may finish its trial. A requested target is never shown as installed
until the device reports it. No API or credentials are service-worker cached.

## Validation

Implemented checks include 76 host firmware tests, backend contract tests,
Firestore emulator authorization/transaction/rule tests, and mobile Chromium
and WebKit dashboard tests. Emulator tests refuse non-local database targets.
The consumer has booted the USB recovery bundle and resumed real ESP-NOW
reception. It sees `openwireless.org`, has approximately 1.9 MB free heap, and
has passed native SHA-256 and storage-capacity probes.

A native HTTPS check-in succeeded over open `openwireless.org`: Firebase recorded
consumer app 1.0.0, base 1.0.0 and the correct hardware/role. The consumer then
returned to ESP-NOW channel 1 and received changing Spectrum data. The dashboard
loads publicly; unauthenticated device requests return HTTP 401. Google sign-in
is enabled and its live popup reaches accounts.google.com. On September 16,
2026, the user confirmed signing in as nick.stielau@gmail.com and viewing the
consumer in the live fleet dashboard. This confirms the authenticated read
flow; live pin/pause/revocation actions have not been user-verified.

The consumer downloaded and SHA-256 verified all ten 1.0.1 release modules over
HTTPS, ran the 30-second trial, and reported `state=current` with 931 frames and
362 received packets. After the confirmation reboot it resumed ESP-NOW channel 1.
A locally injected candidate that raises `RuntimeError` on import rolled back
to the verified 1.0.1 slot and resumed reception. Fault candidates are never
published to GitHub or imported into the cloud.

The initial network attempt reset and recovered into lighting; its cause was
not established. A diagnostic download with the watchdog disabled succeeded;
the subsequent trial and confirmation used the normal watchdog. Reopening the
USB serial bridge also interrupted an early trial, correctly causing rollback.
Keep one serial connection open across resets when measuring a whole update.

A deliberately frozen candidate triggered the 20-second watchdog. Base 1.0.0
selected the correct previous slot but suffered a CircuitPython hard fault
while immediately reconnecting Wi-Fi. After USB installation of base 1.0.1,
the repeated frozen-candidate test rolled back, skipped that network phase and
resumed live ESP-NOW reception (13 packets by frame 33). The server's deployment
counter was advanced beyond the local fault-test sequences; no faulty releases
were published. Application 1.0.2 requires this updated base.

A complete automatic update from 1.0.1 to **1.0.2** then passed with the normal
watchdog enabled throughout. On boot the consumer joined the open SSID,
downloaded all ten modules (58,207 bytes), verified/staged them, rebooted into
the trial and confirmed after 931 frames / 373 received packets. Firebase
recorded app 1.0.2, base 1.0.1, deployment sequence 6 and `state=current`.
After the confirmation reboot it resumed live Spectrum reception on channel 1.
Both GitHub check runs and the release-import workflow passed for 1.0.2.

Both boards have completed USB bootstrap and provisioning; producer details
are below. Physical maintenance and power-loss qualification are tracked
separately from the host tests. Serial reception and pixel-buffer values are not a new visual
confirmation of the installed LEDs.

### Follow-up: intermittent receiver failure

After the successful 1.0.2 update trial, the consumer later saved `ValueError`
and selected USB recovery 1.0.0. Both OTA slots still matched their release
hashes. A direct native receive stress test reproduced `ValueError: Invalid
buffer` after 1,727 polls / 36 ms. CircuitPython 10.3.1 appends the incoming
header, MAC and payload separately, while `read()` tests only whether any bytes
are available.

App 1.0.3 gates reads on `ESPNow.read_success`, which the driver increments
after the complete packet is appended. Consumed native packets are counted
independently of rejected/accepted protocol packets, with 32-bit wrap handling
and the existing eight-packet drain limit. The base remains 1.0.1. This fixes
a reproduced radio failure; the earlier saved error contained only its class,
so it cannot establish that every observed dark interval had this cause.

The fixed native receive path passed 539,217 rapid polling iterations over
30 seconds, receiving 356 valid packets with zero rejected packets or buffer
exceptions. Regression tests cover callback completion, rejected-packet counting,
bounded draining and native counter wraparound.

The consumer subsequently completed the automatic 1.0.3 download, reboot and
30-second health trial. Firebase recorded app 1.0.3 / base 1.0.1, deployment
sequence 7, `state=current`, 931 frames and 360 received packets. Live ESP-NOW
reception resumed after confirmation. GitHub checks and release import passed.

Upstream details: CircuitPython 10.3.1's
[ESP-NOW receive callback and reader](https://github.com/adafruit/circuitpython/blob/10.3.1/ports/espressif/common-hal/espnow/ESPNow.c).

The connected ESP32 V2's USB recovery copy was also updated to 1.0.3 using
`make deploy`, with all 18 deployed files verified and node credentials/profile
preserved. Recovery startup received 85 valid packets in its startup check.
Near-silent spectrum values can legitimately leave the wing dark despite a
live radio link.

### Producer bootstrap (September 16, 2026)

The FeatherS2 `c7fd1a30c4c2` was identified through both USB and CIRCUITPY.
`make deploy` installed and verified all 18 base/recovery files, preserving
`radio_role="producer"` and BOOT/GPIO0. The first staging attempt hit a host USB
I/O error before replacing the original app. The original root app files were
backed up; `diskutil verifyVolume` reported a clean filesystem and remounted
the drive. The retry succeeded without erasing or reformatting flash.

The device-specific credential was provisioned and OTA enabled. The reserved
NVM bytes were checked before use. The host volume was cleanly unmounted before
a hard reset transferred filesystem ownership to CircuitPython; macOS then
mounted CIRCUITPY read-only. Firebase recorded the producer's actual app **1.0.3**,
base **1.0.1**, CircuitPython **10.3.1**, correct board/role and no error.
It disconnected from the AP, resumed ESP-NOW channel 1 and showed microphone
RMS levels changing from roughly 2 to 370 with rising/falling spectrum bars in
the output data. A 65-second observation completed without a reset. This is
serial/feature evidence, not a new visual confirmation on both wings.

The producer reports `state=recovery`, sequence 0 because it is running the
USB-installed app, which already matches the latest release. This is expected
and is not a failed update. A future newer compatible release will download
into an OTA slot and undergo its 30-second trial. Actual OTA download/trial
was verified on the consumer; the producer's current test verifies enrollment,
HTTPS check-in, filesystem ownership, microphone processing and radio startup.

The LED-enabled benchmark with watchdog and health checks measured 146 frames
in 12 seconds (12.1 fps), 74.6 ms mean / 93.0 ms maximum work, 136 frames over
the 64 ms budget, zero detected discontinuities and 146 sends without errors
or skips. See [benchmark interpretation](../README.md#producer-with-ota-health-monitoring-september-16-2026).

During the user's RESET-then-BOOT test, a host poll observed
`DIGIRDU_BOOT mode=maintenance` in `boot_out.txt`. The board subsequently
returned to normal OTA mode with CIRCUITPY read-only to the host. A new Firebase
check-in reported app 1.0.3 with no error, and a passive ten-second serial check
showed continuing microphone levels, spectrum changes and attack events.
This verifies that the physical maintenance branch was reached; host writes
during that window were not tested. Consumer physical maintenance and power-cut
qualification remain separate outstanding checks.

### IO43 button USB update

The external button moved from an unsuccessful IO18 trial to IO43/TX, with
BOOT/IO0 retained. A 60-second native input test recorded 23 debounced presses,
46 transitions and a final HIGH state. IO38 is reserved for the wing data line.
This is a USB development change based on 1.0.3, not a new published OTA release.

The first IO43 deployment hit `EINVAL` accessing `/Volumes/CIRCUITPY/boot.py`.
After `diskutil verifyVolume` reported a clean filesystem and remounted it, the
same FeatherS2 UID showed only default `Hello World` files and empty settings.
The reason for this filesystem reset was not established; no erase, format or
firmware flash was requested by the host tooling. Do not equate a clean FAT
check with verification that application files or credentials are still present.

The saved producer profile was explicitly supplied to a fresh `make deploy`.
All 18 base/recovery files then verified; startup initialized BOOT/GPIO0 and
GPIO43, ESP-NOW channel 1, and changing microphone samples. The earlier flat
microphone failure did not recur in that startup check. The saved device
credential was reprovisioned with OTA enabled, preserving the enrolled identity.
After cleanly unmounting USB storage and resetting, Firebase recorded a fresh
producer check-in with app 1.0.3/base 1.0.1 and no error. CIRCUITPY returned to
host read-only mode. The 45-second boot observation showed changing audio
(logged RMS roughly 4 to 1,079), live spectrum values, and the complete effect
cycle Spectrum → Ember → Aurora → Ripple → Spectrum while audio continued.
This confirms the app's button/effect path in serial output; neither a new
two-wing visual confirmation nor a consumer reception test was performed.

## Chroma release 1.0.4

Application 1.0.4 includes Chroma (display 5, protocol ID 4), stronger
Ember/Aurora/Ripple motion and accents, and the FeatherS2 IO43-to-GND effect
button. It retains the ESP-NOW receive-completion fix from 1.0.3. Base 1.0.1,
CircuitPython 10.3.1, the ten-module app bundle and 51-byte protocol v3 remain
unchanged. Device profiles and credentials remain local.

Roll out to consumers first, then the microphone producer. Keep effects 1–4
selected until all nodes report 1.0.4: consumers on older apps reject effect ID
4 and fade if it stays selected. Spectrum remains the startup default. This
release does not introduce periodic OTA polling or remote resets; each board
checks at normal boot, runs a 30-second health trial, confirms and resumes
ESP-NOW. Use RESET alone, without pressing the maintenance button. Keep open
`openwireless.org` in range. Confirm actual reported versions and outcomes;
publishing a target alone does not prove that boards installed it.

### 1.0.4 rollout evidence (September 16, 2026)

Release source `804f988` and tag `firmware-v1.0.4` were pushed. GitHub's source
checks and release-import workflow passed. The immutable ten-module bundle is
64,209 bytes; Firebase selected deployment sequence 9. The website now labels
the effect library and saved replay as firmware 1.0.4.

The USB-connected ESP32 V2 consumer downloaded and staged 1.0.4 over HTTPS,
rebooted into its trial, then confirmed. Firebase recorded **1.0.4 / base 1.0.1**,
`state=current`, sequence **9**, empty error, **931 frames / 308 packets** in
the trial report. Serial logs showed the cyan number 5, Chroma pixel output
responding to transmitted sound features, and zero rejected packets. After
confirmation/reboot, the consumer resumed Chroma on ESP-NOW channel 1.
These are packet/pixel-buffer observations, not new physical LED confirmation.

After the user reset the separately powered FeatherS2 producer, its boot check
reported the previous USB recovery version and then completed the OTA trial.
Firebase recorded producer **1.0.4 / base 1.0.1**, `state=current`, deployment
sequence **9**, empty error, **415 frames / 286 sends**, and `active=true` in
the confirmation report. Both devices now report the same installed release.
The connected consumer briefly faded during the producer's confirmation/report
and reboot, then resumed live Spectrum reception with zero rejected packets
(365 packets observed after its own latest reboot). Spectrum is the expected
startup effect; Chroma remains effect 5. No new visual LED confirmation was
requested or inferred from these logs. This also verifies the producer's first
newer-version OTA download/trial beyond its USB bootstrap.

## Hold-to-sleep release 1.0.5

App 1.0.5 adds a three-second button hold followed by a three-second red fade
and reset-only deep sleep. Short effect presses now fire on release. Install
consumers first, then the producer; 1.0.4 and older ignore sleep-control packets.
The feature protocol remains v3 and base 1.0.1 needs no USB change. An independent
DGRS control frame carries the repeated sleep countdown. A consumer must have
received a recent feature frame from the same producer session before it accepts
sleep; duplicate/stale/wrong-source commands cannot restart a fade.
Sleep is ignored during the initial 30-second OTA health trial. After confirming,
the reboot starts the app normally and enables sleep. An ordinary intentional
sleep leaves confirmed OTA journals intact; no rollback or persistent sleep flag
is written. Reset each sleeping board separately to wake and run its boot-time
update check. With a USB/BLE host attached, CircuitPython may simulate sleep.
Host regression tests do not establish actual sleep current or visual behavior.

### 1.0.5 rollout evidence

Source `c89b6d4` / tag `firmware-v1.0.5` was pushed and published. GitHub checks
and immutable import passed; the ten app files total 70,968 bytes. All 100 host
firmware tests, web/backend/emulator tests and 30 browser tests passed. The
Effects page was published with the short-release and hold-to-sleep instructions.

The ESP32 V2 consumer downloaded/verified 1.0.5 and confirmed its OTA trial.
Firebase recorded app **1.0.5**, base **1.0.1**, `state=current`, deployment
sequence **10**, no error, **826 frames / 287 received packets**. It then
rebooted and resumed live Ember reception with zero rejected packets. Its
native CircuitPython image exposes the deep-sleep API. The producer subsequently confirmed too (below). Actual red-fade appearance,
deep-sleep current and reset wake-up still require the physical test. A host-connected sleep test alone cannot establish true
low-power consumption.

The producer's normal reset then completed the **1.0.5** OTA trial. Firebase
recorded app 1.0.5 / base 1.0.1, `state=current`, sequence 10, no error, **405
frames / 292 sends**. Both nodes now report 1.0.5. The consumer briefly faded
during the producer's confirmation/reboot, then resumed Spectrum with zero
rejected packets. The physical long-press test is separate from this OTA result.

During the subsequent user-triggered long press, the consumer received the
sleep broadcast at host log time **202.099 s** with **3.00 s remaining** and
logged deep-sleep entry at **205.117 s**: **3.018 s** later. Its output reported
32 lit pixels with peaks decreasing **28 → 15 → 2**, and zero rejected packets.
Cleanup completed without a traceback or OTA failure message; the app stopped
with autoreload off and the USB console retained. This validates native command
receipt, fade timing and handoff to the alarm API. It does not establish true
low-power current on USB, the producer's physical appearance, or reset wake-up.
Logs remain ignored under `.artifacts/sleep-physical-test.log` and
`.artifacts/sleep-physical-events.jsonl`. User visual/reset confirmation remains
separate from the native consumer result.

## Sleep output hold 1.0.6

After the native 1.0.5 sleep test, the user reported one bright white pixel on
the wing with slight color changes. This is not a passed dark-state visual
check. Version 1.0.6 addresses the potentially floating GPIO during VM teardown:
reclaim the verified wing pin after cleanup, send black, drive LOW, wait 1 ms,
then preserve its output state through the alarm call. It uses no wake alarms
and does not require an updated USB base. The suspected cause still needs a
physical retest. Both nodes need a normal reset to wake/check for this update.

Both nodes subsequently confirmed **1.0.6**, base **1.0.1**, deployment
sequence **11**, `state=current`, with no reported OTA error. The consumer
trial recorded **931 frames / 256 packets**; the producer recorded **406
frames / 290 sends**. GitHub checks and release import passed. After its
confirmation reboot, the consumer ran but reported no received packets;
restored reception and the repeat physical sleep test remain pending. These
reports establish installation, not a passed dark-state test.

After connecting the producer to USB, passive console capture showed changing
microphone features with no captured exception. Its active OTA journal was
current with no trial/error, and all ten active files matched their 1.0.6
manifest hashes. The user then confirmed both wings respond to claps again,
establishing restored audio/LED response and wireless reception. The earlier
dark state remains unexplained; this does not establish a crash or its cause.

The 1.0.6 physical sleep retest passed: the user confirmed **both wings faded
red to completely black and stayed black**, including the previously white
pixel. The producer console recorded the sleep request at **28.632 s** and
alarm handoff with the wing data held LOW at **31.749 s** (**3.117 s** later),
without a traceback. The USB console then reported `Code done running`.
Logs are local under `.artifacts/sleep-106-producer.log` and
`.artifacts/sleep-106-producer-events.jsonl`. This confirms the visual result
and native producer handoff; electrical sleep current remains unmeasured.

The user then reset each board with BOOT released and confirmed **both wings
respond to claps again**. Producer USB reconnected and passive logs showed
changing audio features. This completes the two-board visual fade/dark-state
and physical-reset wake test for 1.0.6.

## USB base 1.0.2: OTA activity indicator

The base now shows one cyan pixel during check-in, download and confirmation
reporting, moving to the next physical pixel at two-second service intervals.
Only one of 32 pixels is lit, at 15% maximum brightness; blocking network calls
pause movement. It is an activity marker, not a download percentage. Cleanup
blacks the wing and releases its pin on both normal and network-error exits.
Audio/ESP-NOW resumes through the existing boot flow.

This requires `make deploy-base` over USB on each node (FeatherS2 requires
BOOT-after-RESET maintenance mode). Preserve recovery/active/trial slots,
settings and node identity. App remains 1.0.6; base 1.0.1 remains compatible
with app OTA, with APP_MINIMUM_BASE separate from the installed BASE_VERSION.
Host checks pass 104 tests, including pin mapping, capped single-pixel stepping,
wraparound, error cleanup and unchanged app compatibility. Hardware deployment
and visual confirmation are tracked separately below.

The FeatherS2 producer received all seven base files through `make deploy-base`
with successful readback. After unmounting CIRCUITPY and a normal hard reset,
serial reported app **1.0.6 / base 1.0.2**, completed network maintenance and
resumed I2S/ESP-NOW. Firebase confirmed current 1.0.6, sequence 11, base 1.0.2,
no error. The ESP32 V2 consumer still reports base 1.0.1 and needs its own USB
base deployment. Visual confirmation of the activity indicator is separate
from file verification and the successful boot.
The user subsequently confirmed seeing the advancing cyan pixel during the
producer's OTA check, followed by the normal audio effects. Producer visual
verification is complete.

The ESP32 V2 consumer then received and verified the same seven base files.
After normal reset, Firebase reported **app 1.0.6 / base 1.0.2**, current,
sequence 11, no error on both devices. Consumer logs showed live reception
with **198 accepted / 0 rejected packets** after resuming. Its native boot
capture is `.artifacts/ota-indicator-consumer-boot.log`; producer capture is
`.artifacts/ota-indicator-producer-boot.log`. Consumer visual confirmation
remains separate from these serial/fleet results.

The user then confirmed the consumer's indicator too, but found it too bright
and slow on both boards. USB base **1.0.3** changes only the indicator to
**3% brightness** (integer GRB `7, 0, 7`) and a **0.5-second step interval**.
The audio-effect brightness cap stays 15%. Blocking Wi-Fi/TLS can still hold
the current pixel until control returns. This tuning needs another USB base
deployment on each device; the OTA app remains 1.0.6.

The ESP32 V2 consumer's seven base files verified, and a normal reboot reported
**app 1.0.6 / base 1.0.3** to Firebase with no error. ESP-NOW reception resumed
with **103 accepted / 0 rejected packets** in the startup log
`.artifacts/ota-dim-consumer-boot.log`. All 104 host tests passed. Producer
deployment and the user's assessment of the revised appearance remain pending.

The producer subsequently verified all seven base files too. The deploy
startup check encountered BOOT-triggered CircuitPython USER safe mode. After
cleanly unmounting CIRCUITPY, a normal-mode hard reset restored app startup;
serial reported **app 1.0.6 / base 1.0.3** and resumed microphone capture and
ESP-NOW. No flash erase or app-slot replacement was needed. Both devices now
report base 1.0.3/current app 1.0.6 with no OTA error. The capture is
`.artifacts/ota-dim-producer-boot.log`. GitHub checks passed; the revised
brightness/speed preference has not yet been visually assessed by the user.

## Battery support: app 1.0.7 / USB base 1.0.4

The optional `battery` report field has an explicit status and nullable voltage;
the API still accepts old reports without it. The fleet view labels it as the
last reported BAT/JST voltage, not a live percentage or battery-presence signal.
ESP32 V2 uses its ADC1 GPIO35 divider. Original FeatherS2 reports unsupported
until external sensing is explicitly wired and implemented.

`battery.py` is a shared base module preloaded by ota_bootstrap, and is included
in the eight USB base files. Base deployment preserves recovery/OTA slots and
credentials. App 1.0.7 requires minimum base 1.0.4; publish/deploy the compatible
API first, then USB bases, then boot into app OTA. Existing bases stay compatible
with earlier app releases and old-format reports. No credentials or sensor
values are included in release assets.

Effect 6 selects the local battery gauge/scrolling voltage on each wing. Voltage
does not enter the ESP-NOW feature packet; it remains protocol v3. Upgrade all
consumers before selecting Battery. The display refreshes locally every two
seconds, while cloud snapshots occur only during boot-time network maintenance.
ADC resources are released after each read, and errors replace stale readings.
Host checks cover sensor conversion/cleanup, unsupported S2, error/null states,
report snapshots, local display after radio loss, gauge/scroll/rotation/caps and
cloud schema/round-trip behavior. Native readings, multimeter calibration and
visual acceptance require hardware and are tracked separately.

Release **1.0.7**, tag `firmware-v1.0.7`, source `2243603`, was published and
imported as stable. Firmware/dashboard GitHub checks passed. Local validation
passed **111 firmware tests**, web/API tests, **30 browser tests** and **12
Firestore emulator tests**. The deviceApi function and hosting were deployed
successfully before release publication; old reports remain accepted.

No USB board was connected during implementation, so base 1.0.4 deployment,
native ADC accuracy, actual battery reports, and the two-wing visual test are
pending. Existing base 1.0.3 devices retain compatible app 1.0.6 until their
USB base upgrade. `.artifacts/battery-preview.html` previews actual renderer
frames using clearly labelled simulated 3.3/3.7/4.2 V values and unavailable
state; these are not hardware measurements or saved playing data.

### Consumer deployment, September 20, 2026

The user confirmed LiPo batteries on BAT/JST. After USB enumeration returned,
the first deployment attempt lost its USB connection during setup. A retry
verified all **eight base files** without erasing flash. The ESP32 V2 consumer
then downloaded and confirmed app **1.0.7 / base 1.0.4**, deployment sequence
**12**, with no OTA error and **931 frames** in its health trial. No producer
packets were received during this trial; this does not verify the current RF
link. Firebase accepted the new battery report, **4.379 V / measured**.

An independent native ADC sequence sampled at 20 ms intervals returned
**4.382–4.388 V**. The readings are stable, but not checked against a
multimeter; no calibration gain was changed to force an expected voltage.
The USB-powered charging state can affect the terminal reading. Base readback
and OTA logs are `.artifacts/battery-consumer-base-deploy.log` and
`.artifacts/battery-consumer-ota.log`. Producer base/app upgrade and visual
acceptance are tracked separately from this successful consumer report.

### Gauge-only display: app 1.0.8

The user confirmed both displays appeared, but found scrolling voltage hard to
read. App 1.0.8 keeps the portrait battery gauge visible continuously after the
effect number. Numeric voltage remains in device reports. The 3% cap,
two-second sampling, local readings and unavailable dashes are unchanged.
This is an app-only OTA change; USB base 1.0.4 remains compatible.

The repeated consumer demo ran 60 seconds / 1,063 frames with readings
4.380–4.387 V and peak output 7, then restored normal app 1.0.7 startup.
This confirms the original display ran; gauge-only deployment is pending.

Release **1.0.8**, source `1caaee7` / tag `firmware-v1.0.8`, was published and
imported successfully. All 111 firmware tests, web/API checks, 30 browser tests,
12 emulator tests and GitHub checks passed. The updated Effects guide is live.
The connected ESP32 V2 consumer staged 1.0.8, confirmed it after its health
trial, and resumed normal startup at **app 1.0.8 / base 1.0.4**. The capture is
`.artifacts/battery-gauge-consumer-ota.log`. No packets arrived during the
observed startup, and this run did not visually validate the revised gauge.
The producer's latest fleet report remains app 1.0.6 / base 1.0.3; its USB base
upgrade is still needed. Do not infer that the visual report for both displays
establishes both firmware versions.

### Producer deployment and recovery, September 20, 2026

FeatherS2 UID `c7fd1a30c4c2` entered USB maintenance and verified all eight
base files with `make deploy-base`. After unmounting CIRCUITPY, a normal-mode
reset started OTA. The first network attempt returned `OSError` and resumed
app 1.0.6; a second boot downloaded and confirmed **1.0.8 / base 1.0.4**,
sequence **13**, with **399 frames / 267 sends** in the trial report. Firebase
reports no OTA error and `battery: {status: "unsupported", voltage: null}`.
The ESP32 V2 also reports current 1.0.8/base1.0.4/sequence13; its latest
battery snapshot after disconnecting laptop USB was **3.691 V** (uncalibrated).

The producer's post-confirmation reset entered CircuitPython native
`SafeModeReason.HARD_FAULT`, with software reset reason and no previous Python
traceback. The slot journal remained current 1.0.8 and BOOT read released.
After cleanly unmounting the drive, an explicit normal-mode reset with the
one-boot network skip restored microphone processing and ESP-NOW initialization.
This recovers operation but does not establish the native fault's cause or fix
it. No flash erase or slot replacement was performed. Logs are
`.artifacts/battery-gauge-producer-base.log`,
`.artifacts/battery-gauge-producer-ota.log`, and
`.artifacts/battery-gauge-producer-recovery.log`.

The user was asked to select Battery for the two-wing gauge-only visual check;
that confirmation remains separate from firmware/report validation.

The recovered producer then registered all five short presses through
Ember/Aurora/Ripple/Chroma to `EFFECT 5 Battery display=6`, with audio processing
continuing. The user confirmed the consumer shows a steady gauge with no
scrolling and the FeatherS2 shows two amber dashes. The gauge-only two-wing
visual check is complete. Passive host monitoring was stopped, leaving the
normal application running in the selected Battery effect.

### Recurrent sleep illumination investigation

After the successful gauge rollout, the user reported intermittent LEDs turning
bright after long-press sleep. App 1.0.8 already uses the output-hold sequence
introduced in 1.0.6. Read-only source inspection and a passive 12-second USB
listen were performed; the connected FeatherS2 console was idle with a Done
title. No reset, GPIO reconfiguration or new firmware was applied during this
inspection, so the board's existing sleep/stopped state was left undisturbed.
The affected node and USB-versus-battery reproduction remain unconfirmed.

README now documents an input-side 10 kΩ pull-down as a proposed floating-input
test, and default-off wing power switching as the stronger hardware solution.
The wing's DIN pad is level-shifted; both its diode-fed VBAT and VUSB sources
must be considered for power isolation. Neither hardware change is installed.
Do not treat the older two-wing visual pass as resolution of this recurrence.

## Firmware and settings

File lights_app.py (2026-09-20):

"""FeatherS2 microphone producer and FeatherS2/ESP32 V2 wireless lighting."""

import array
import gc
import time

import board
import digitalio
from neopixel_write import neopixel_write
from config import CONFIG
from audio_spectrum import Spectrum
from audio_features import Analyzer
from animation import CulvertAnimation
from sound_reactive import measure
from effects import ButtonGesture, SleepTransition, EFFECT_NAMES
from battery import BatteryMonitor

if board.board_id == "unexpectedmaker_feathers2":
    PIXEL_PIN = board.IO38  # Factory jumper's physical position, not D6 alias.
elif board.board_id == "adafruit_feather_esp32_v2":
    PIXEL_PIN = board.D32
    if CONFIG.radio_role != "follower":
        raise RuntimeError("ESP32 V2 wiring is configured for consumer mode only")
else:
    raise RuntimeError("Unconfigured board: " + board.board_id)
SAMPLE_RATE = CONFIG.sample_rate
SAMPLE_COUNT = CONFIG.hop_size


class EffectButtons:
    def __init__(self):
        self.inputs = []
        try:
            for gpio, step in ((CONFIG.button_next_gpio, 1),
                               (CONFIG.button_extra_next_gpio, 1),
                               (CONFIG.button_previous_gpio, -1)):
                if gpio is None:
                    continue
                pin = digitalio.DigitalInOut(getattr(board, "IO%d" % gpio))
                self.inputs.append((pin, ButtonGesture(CONFIG.button_debounce_s, CONFIG.button_sleep_hold_s), step))
                pin.switch_to_input(pull=digitalio.Pull.UP)
                print("BUTTON GPIO%d step=%+d pull=UP" % (gpio, step))
        except Exception:
            self.deinit()
            raise

    def poll(self, animation, now, sleep, allow_sleep=True):
        for pin, button, step in self.inputs:
            gesture = button.update(not pin.value, now)
            if sleep.started is not None:
                continue
            if gesture == ButtonGesture.HOLD:
                if allow_sleep:
                    sleep.request(now, CONFIG.sleep_fade_s)
                    print("SLEEP requested: red fade %.1f s" % CONFIG.sleep_fade_s)
                else:
                    print("SLEEP ignored during OTA trial; retry after confirmation")
            elif gesture == ButtonGesture.SHORT:
                animation.set_effect((animation.effect + step) % len(EFFECT_NAMES))
                print("EFFECT %d %s display=%d" %
                      (animation.effect, EFFECT_NAMES[animation.effect], animation.effect + 1))

    def deinit(self):
        for pin, _, _ in self.inputs:
            pin.deinit()


def microphone():
    if board.board_id != "unexpectedmaker_feathers2":
        raise RuntimeError("Microphone wiring is configured only for FeatherS2")
    import audioi2sin
    # SEL/LR grounded selects the left channel. ICS43434 uses standard I2S
    # with 24 significant bits inside 32-bit slots, then scaled to signed 16-bit.
    return audioi2sin.I2SIn(
        board.IO5, board.IO6, board.IO9, sample_rate=SAMPLE_RATE,
        bit_depth=32, output_bit_depth=16, mono=True,
        left_justified=False, samples_signed=True,
    )


def read_level(mic, samples):
    count = mic.record(samples, len(samples))
    if count != len(samples):
        raise RuntimeError("Incomplete I2S capture: %d/%d" % (count, len(samples)))
    return measure(samples, count)


def test_microphone(seconds=10):
    """Print levels without driving LEDs; call with make test-mic."""
    samples = array.array("h", [0] * SAMPLE_COUNT)
    print("MIC TEST: stay quiet, then clap or speak near the microphone")
    with microphone() as mic:
        start = time.monotonic()
        next_log = start + 0.5
        lowest = 32768.0
        highest = 0.0
        max_span = 0
        while time.monotonic() - start < seconds:
            rms, peak, span = read_level(mic, samples)
            # Ignore the microphone's initial wake-up interval.
            if time.monotonic() - start < 0.2:
                continue
            lowest = min(lowest, rms)
            highest = max(highest, rms)
            max_span = max(max_span, span)
            if time.monotonic() >= next_log:
                print("MIC rms=%.1f peak=%.1f span=%d" % (rms, peak, span))
                next_log = time.monotonic() + 0.5
    print("MIC TEST RESULT min_rms=%.1f max_rms=%.1f max_span=%d" %
          (lowest, highest, max_span))
    if max_span == 0:
        raise RuntimeError("Microphone data is flat; check power, SEL, and GPIO 5/6/9")


def benchmark(seconds=5):
    """Finite live capture/FFT/render benchmark, without driving the LEDs."""
    run(seconds=seconds, drive_pixels=False)


def run(seconds=None, drive_pixels=True, health=None):
    CONFIG.validate()
    # Allocate the FFT/renderer BEFORE starting the continuous I2S DMA stream.
    spectrum = Spectrum(CONFIG)
    analyzer = Analyzer(CONFIG)
    animation = CulvertAnimation(CONFIG)
    battery = BatteryMonitor(CONFIG.battery_sample_s)
    radio = None
    if CONFIG.radio_role == "leader":
        from wireless import Wireless
        radio = Wireless(CONFIG)
    samples = array.array("h", [0] * CONFIG.hop_size)
    period = CONFIG.hop_size / CONFIG.sample_rate
    buttons = EffectButtons()
    sleep = SleepTransition()
    gc.collect()
    with digitalio.DigitalInOut(PIXEL_PIN) as pin:
        pin.switch_to_output(value=False)
        try:
            with microphone() as mic:
                print("AUDIO calibration: keep quiet for %.1f seconds" % CONFIG.calibration_s)
                print("Didgeridoo: %d Hz, FFT=%d hop=%d, IO38, %d pixels, brightness=%.2f" %
                      (CONFIG.sample_rate, CONFIG.fft_size, CONFIG.hop_size,
                       CONFIG.pixel_count, CONFIG.brightness))
                print("EFFECT %d %s; BOOT advances while running" % (animation.effect, EFFECT_NAMES[animation.effect]))
                started = previous = next_log = time.monotonic()
                flat_since = None
                frames = overruns = discontinuities = 0
                total_work = max_work = 0.0
                while seconds is None or time.monotonic() - started < seconds:
                    count = mic.record(samples, len(samples))
                    now = time.monotonic()
                    dt = now - previous
                    previous = now
                    # ESP32-S2's driver cannot report every DMA overflow; a long
                    # wall-clock gap is an additional warning, not proof of loss.
                    if count != len(samples) or mic.overflow or dt > 3 * period:
                        discontinuities += 1
                        spectrum.reset_history()
                        analyzer.discontinuity()
                        print("AUDIO discontinuity: samples=%d gap_ms=%.1f" % (count, dt * 1000))
                        if count != len(samples):
                            continue
                    raw = spectrum.push(samples)
                    if raw is None:
                        continue
                    features = analyzer.update(raw, max(period / 2, dt))
                    if raw["span"] == 0:
                        if flat_since is None:
                            flat_since = now
                    else:
                        flat_since = None
                    if flat_since is not None and now - flat_since > CONFIG.flat_timeout_s:
                        raise RuntimeError("Microphone data is flat; check GPIO 5/6/9, power and SEL=GND")
                    buttons.poll(animation, now, sleep, allow_sleep=not (health and health.trial))
                    if animation.effect == 5:
                        animation.battery_voltage = battery.update(now)["voltage"]
                    pixels = (sleep.pixels(now, CONFIG) if sleep.started is not None else
                              animation.render(features, max(period / 2, dt)))
                    if drive_pixels:
                        neopixel_write(pin, pixels)
                    if radio is not None:
                        radio.publish(features, animation, now, sleep)
                    if health is not None:
                        health(features, radio)
                    if sleep.done(now):
                        raise SleepRequested()
                    if features.attackEvent:
                        print("ATTACK strength=%.2f" % features.attack)
                    if features.yellEvent:
                        print("YELL vocal=%.2f" % features.vocal)
                    if now >= next_log:
                        print("AUDIO rms=%.1f noise=%.1f vol=%.2f drone=%.2f harm=%.2f timbre=%.2f growl=%.2f vocal=%.2f rough=%.2f active=%s clip=%s" %
                              (features.rms, features.noiseFloor, features.volume, features.drone,
                               features.harmonics, features.timbrePosition, features.growl,
                               features.vocal, features.roughness, features.active, features.clipped))
                        print("SPECTRUM levels=" + str(tuple(round(v, 2) for v in features.spectrum)))
                        next_log = now + CONFIG.log_interval_s
                        # Explicit collections bound fragmentation; include them
                        # and LED output in the processing-time measurement.
                        gc.collect()
                    work = time.monotonic() - now
                    frames += 1
                    total_work += work
                    max_work = max(max_work, work)
                    if work > period:
                        overruns += 1
                        if overruns == 1 or overruns % 100 == 0:
                            print("AUDIO processing over budget: %.1f ms / %.1f ms" %
                                  (work * 1000, period * 1000))
                print("AUDIO BENCH frames=%d fps=%.1f work_mean_ms=%.1f work_max_ms=%.1f budget_ms=%.1f overruns=%d discontinuities=%d" %
                      (frames, frames / (time.monotonic() - started),
                       total_work * 1000 / max(frames, 1), max_work * 1000,
                       period * 1000, overruns, discontinuities))
                if radio is not None:
                    print("RADIO BENCH sent=%d errors=%d skipped=%d" %
                          (radio.sent, radio.errors, radio.skipped))
        finally:
            neopixel_write(pin, bytes(CONFIG.pixel_count * 3))
            buttons.deinit()
            if radio is not None:
                radio.deinit()


def run_follower(health=None):
    from wireless import Wireless
    animation = CulvertAnimation(CONFIG)
    battery = BatteryMonitor(CONFIG.battery_sample_s)
    radio = Wireless(CONFIG)
    with digitalio.DigitalInOut(PIXEL_PIN) as pin:
        pin.switch_to_output(value=False)
        try:
            previous = next_log = time.monotonic()
            frames = 0
            sleep_announced = False
            while True:
                now = time.monotonic()
                dt = max(0.001, now - previous)
                previous = now
                features = radio.receive(now, animation)
                lost = radio.receiver.fade_if_lost(now, dt)
                if animation.effect == 5:
                    animation.battery_voltage = battery.update(now)["voltage"]
                # Ignore sleep during the initial OTA health trial. An intentional
                # sleep/reset must not be mistaken for a failed candidate.
                sleep = radio.receiver.sleep
                if health and health.trial:
                    if sleep.started is not None:
                        print("SLEEP ignored during OTA trial; retry after confirmation")
                        sleep.started = None
                if sleep.started is not None and not sleep_announced:
                    print("SLEEP received: red fade remaining=%.2f s" %
                          max(0.0, sleep.duration - sleep.elapsed(now)))
                    sleep_announced = True
                pixels = (sleep.pixels(now, CONFIG) if sleep.started is not None else
                          animation.render(features, dt))
                neopixel_write(pin, pixels)
                radio.receiver.clear_events()
                if health is not None:
                    health(features, radio)
                if sleep.done(now):
                    raise SleepRequested()
                frames += 1
                if now >= next_log:
                    age_ms = (int((now - radio.receiver.last_receive) * 1000)
                              if radio.receiver.accepted else -1)
                    lit = sum(1 for i in range(0, len(pixels), 3)
                              if pixels[i] or pixels[i + 1] or pixels[i + 2])
                    print("LIGHTS frame=%d received=%d rejected=%d effect=%s indicator=%d link=%s age_ms=%d active=%s vol=%.2f drone=%.2f growl=%.2f vocal=%.2f lit=%d/%d peak=%d" %
                          (frames, radio.receiver.accepted, radio.receiver.rejected,
                           EFFECT_NAMES[animation.effect],
                           animation.effect + 1 if animation.indicator_remaining > 0 else 0,
                           "lost/fading" if lost else "live", age_ms, features.active,
                           features.volume, features.drone, features.growl, features.vocal,
                           lit, CONFIG.pixel_count, max(pixels)))
                    print("SPECTRUM levels=" + str(tuple(round(v, 2) for v in features.spectrum)))
                    next_log = now + CONFIG.log_interval_s
                    gc.collect()
                time.sleep(max(0, CONFIG.receiver_frame_s - (time.monotonic() - now)))
        finally:
            neopixel_write(pin, bytes(CONFIG.pixel_count * 3))
            radio.deinit()


class SleepRequested(BaseException):
    """Unwind hardware contexts without triggering the OTA failure handler."""


def enter_deep_sleep():
    import alarm
    import microcontroller
    import supervisor
    import wifi
    # The caller has already blacked out LEDs and closed I2S, GPIO and ESP-NOW.
    # Disable the watchdog also for CircuitPython's USB-connected simulated sleep.
    microcontroller.watchdog.mode = None
    supervisor.runtime.autoreload = False
    wifi.radio.enabled = False
    # Keep the powered wing's data input LOW through VM teardown and sleep.
    # Releasing it to high impedance can latch stray bits after the black frame.
    # Do not use a with/finally here: DeepSleepRequest unwinds Python contexts.
    sleep_pin = digitalio.DigitalInOut(PIXEL_PIN)
    sleep_pin.switch_to_output(value=False)
    neopixel_write(sleep_pin, bytes(CONFIG.pixel_count * 3))
    sleep_pin.value = False
    time.sleep(0.001)  # Allow the all-black frame to latch before holding the pin.
    print("SLEEP entering deep sleep; wing data held LOW; reset each board to wake")
    # Pin preservation is an output hold, NOT a PinAlarm or other wake source.
    alarm.exit_and_deep_sleep_until_alarms(preserve_dios=(sleep_pin,))


def main(health=None):
    try:
        if CONFIG.radio_role == "follower":
            run_follower(health=health)
        else:
            run(health=health)
    except SleepRequested:
        enter_deep_sleep()


if __name__ == "__main__":
    main()

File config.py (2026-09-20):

"""Installation tuning. Frequencies in Hz, times in seconds, levels in PCM units."""


class Config:
    # Confirmed hardware pins live only in code.py.
    sample_rate = 16000
    fft_size = 1024
    hop_size = 1024
    bands = ((45, 180), (180, 450), (450, 1000), (1000, 3500), (3500, 8000))
    # Eight diagnostic columns; independent of the five musical detector bands.
    spectrum_edges = (45, 90, 180, 350, 700, 1400, 2800, 5000, 8000)
    spectrum_attack_s = 0.05
    spectrum_release_s = 0.30
    spectrum_gain = 1.0
    spectrum_full_scale = 2.0  # Multiple of the slowly adapting RMS reference.
    spectrum_curve = 0.6  # Compress amplitude to make quieter harmonics visible.
    spectrum_rotation = 0  # Landscape 8 columns x 4 rows; optionally 180.
    timbre_band = (150, 1000)
    vocal_band = (700, 3500)
    roughness_band = (180, 3500)
    roughness_metric = "participation"  # Faster than logarithmic flatness on S2.
    noise_tonal_bins = 2.0  # A Hann-windowed sinusoid occupies about two effective bins.
    noise_expected_fill = 0.5  # Expected effective-bin fraction for noise power.
    gain = 1.0
    calibration_s = 2.0
    warmup_s = 0.2
    calibration_quantile = 0.2
    min_noise_rms = 2.0
    noise_rise_s = 120.0
    noise_fall_s = 4.0
    noise_learn_ratio = 1.8
    level_initial = 120.0
    level_rise_s = 12.0
    level_fall_s = 45.0
    adaptation_limit = 2.0  # Cap each observation before updating the reference.
    active_on_ratio = 2.8
    active_off_ratio = 1.6
    active_full_ratio = 5.0
    silence_hold_s = 0.45
    feature_attack_s = 0.09
    feature_release_s = 0.6
    drone_attack_s = 0.3
    drone_release_s = 1.8
    timbre_s = 0.22
    growl_attack_s = 0.16
    growl_release_s = 0.85
    vocal_attack_s = 0.08
    vocal_release_s = 0.5
    drone_snr = (2.0, 6.0)
    drone_concentration = (0.4, 0.85)
    pitch_change_fraction = 0.3
    harmonics_ratio = (0.03, 0.65)
    mid_ratio = (0.08, 0.55)
    flatness_range = (0.03, 0.4)
    spread_hz = (200.0, 1200.0)
    modulation_range = (0.015, 0.18)
    modulation_s = 0.16
    spectrum_reference_s = 0.6
    shape_flux_range = (0.02, 0.25)
    roughness_weights = (0.55, 0.25, 0.20)  # Flatness, modulation, shape flux.
    vocal_total_ratio = (0.10, 0.55)
    vocal_drone_ratio = (0.12, 1.5)
    vocal_reference_s = 15.0
    vocal_excess_range = (0.04, 0.25)
    yell_on = 0.58
    yell_off = 0.25
    yell_rise = 0.10
    yell_cooldown_s = 0.6
    attack_flux_range = (0.06, 0.4)
    attack_rise_range = (0.08, 0.6)
    attack_weights = (0.65, 0.35)  # Positive spectral flux and RMS rise.
    attack_on = 0.5
    attack_off = 0.18
    attack_cooldown_s = 0.18
    attack_release_s = 0.22
    echo_event_ratio = 0.6
    echo_memory_s = 0.8
    event_warmup_s = 0.15
    decay_s = 3.5
    flat_timeout_s = 2.0
    log_interval_s = 1.0
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

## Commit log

2026-09-15 Add isolated producer button input diagnostic
2026-09-16 Record Spectrum deployment and reception on ESP32 V2 consumer
2026-09-16 Record visual confirmation of Spectrum on both wings
2026-09-16 Add laser-themed effects guide and Google profile menu
    Document the four released effects, share the account dropdown across pages, and verify desktop/mobile navigation. Record producer OTA provisioning, maintenance observation, and measured timing.
2026-09-16 Record successful producer OTA and two-board 1.0.4 convergence
2026-09-16 Add three-second hold and broadcast red fade into reset-only sleep
    [config.py, effects.py, lights_app.py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]
2026-09-16 Hold wing data LOW through deep sleep to prevent stray pixels
    [lights_app.py, test_sleep.py]
2026-09-16 Record successful two-board sleep and reset tests for 1.0.6
2026-09-16 Record OTA indicator deployment on both boards
2026-09-20 Add local battery voltage effect and device report telemetry
2026-09-20 Record Battery release validation and pending hardware deployment
2026-09-20 Keep Battery effect on a persistent gauge
2026-09-20 Record producer Battery rollout and two-wing visual confirmation
2026-09-23 Specify Reverse TFT dashboard and shared device support
2026-09-25 Add producer enclosure revision 11 and hardware workflow
    [DidgeLights-enclosure-v11.f3d, DidgeLights-v10-H2D.3mf, button-carrier-domed.stl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]
2026-09-29 docs: specify consumer button rail and pinhole reset
2026-09-29 docs: plan consumer button rail revision
2026-10-08 feat: add validated Mac audio fixture capture
    [record_fixture.py, test_record_fixture.py]
2026-10-08 fix: harden capture error handling
    [record_fixture.py, test_record_fixture.py]
2026-10-08 fix: pad Mac audio capture startup latency
    [record_fixture.py, test_record_fixture.py]
2026-10-08 fix: validate recorder duration arguments
    [record_fixture.py, test_record_fixture.py]
2026-10-08 fix: capture exact PCM duration from Mac stream
    [record_fixture.py, test_record_fixture.py]
2026-10-08 fix: reject positive ffmpeg exit after exact capture
    [record_fixture.py, test_record_fixture.py]
2026-10-08 fix: close semantic events at final frame timestamp
    [audio_events.py, test_audio_events.py]
2026-10-08 feat: analyze WAV fixtures through producer pipeline
    [sound_review.py, test_sound_review.py]
2026-10-08 fix: harden Mac recorder process handling
    [record_fixture.py, test_record_fixture.py]
2026-10-08 fix: reject malformed sound label types
    [sound_review.py, test_sound_review.py]
2026-10-08 fix: bound recorder pipe reads
    [record_fixture.py, test_record_fixture.py]
2026-10-08 fix: keep recorder temp fd through validation
    [record_fixture.py, test_record_fixture.py]
2026-10-08 fix: reap recorder process on capture errors
    [record_fixture.py, test_record_fixture.py]
2026-10-08 fix: harden sound review validation
    [audio_events.py, sound_review.py, test_audio_events.py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]
2026-10-08 fix: preserve recorder reap state
    [record_fixture.py, test_record_fixture.py]
2026-10-08 fix: reject natural recorder signal exits
    [record_fixture.py, test_record_fixture.py]
2026-10-08 fix: harden sound review comparison metrics
    [sound_review.py, test_sound_review.py]
2026-10-08 fix: preserve effect events and feature cadence
    [sound_review.py, test_sound_review.py]
2026-10-08 fix: consume replay events once and record detector config
    [sound_review.py, test_sound_review.py]
2026-10-08 fix: complete synchronized sound review workflow
    [sound_review.py, test_sound_review.py]
2026-10-08 fix: support partial final WAV analysis hop
    [sound_review.py, test_sound_review.py]
2026-10-08 fix: use actual final analysis interval
    [sound_review.py, test_sound_review.py]
2026-10-08 fix: close sound review timing and overlay gaps
    [sound_review.py, test_sound_review.py]
2026-10-08 fix: flush delayed terminal effect events
    [sound_review.py, test_sound_review.py]
2026-10-08 fix: make delayed effect rendering deterministic
    [sound_review.py, test_sound_review.py]
2026-10-08 fix: honor causal delay in effect replay
    [sound_review.py, test_sound_review.py]
2026-10-08 fix: allow for CoreAudio startup latency
    [record_fixture.py, test_record_fixture.py]
2026-10-08 test: add human-reviewed drone yell fixture
    [test_sound_review.py]
2026-10-08 docs: design event visibility filters
2026-10-08 docs: plan event visibility filters
2026-10-08 feat: filter known sound review events
2026-10-08 test: cover extensible review event filters
2026-10-12 Add RF telemetry with sleep upload and manifest-driven OTA (#1)
    * Add sleep-uploaded RF telemetry and manifest-driven OTA files
    * Allow bounded data assets in OTA app slots
    * Allow targeted OTA releases and app-owned protocol metadata
2026-10-13 Call installed layer device base in live web UI
2026-10-13 Restore Reverse TFT OTA check-ins in current backend (#4)
    * Restore Reverse TFT OTA check-in support
    * Default to CI-gated auto-merge for PRs
2026-10-13 Consolidate Echo Glow enclosures and prepare hardware releases (#5)
    * Add Echo Glow producer direct USB enclosure release
    * Consolidate hardware enclosures and prepare tagged print kits
    * Remove source-page preview link to release-only image
    * Clarify hardware release tag convention
2026-10-13 Compact Echo Glow producer enclosure without pixel wing (#10)
    * Specify compact Echo Glow producer without pixel wing
    * Define measured producer battery envelope
    * Plan compact Echo Glow producer CAD revision
    * Document compact Echo Glow producer revision 4
2026-10-14 Soften Echo Glow producer enclosure edges (#12)
    * Specify producer edge softening
    * Document softened producer enclosure edges
